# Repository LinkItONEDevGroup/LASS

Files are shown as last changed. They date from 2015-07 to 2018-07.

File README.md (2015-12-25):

# LASS
Project Name: 

	Location Aware Sensing System (LASS)

Vision: 
	
	We hope location aware sensor devices can be easy to provide/build by anyone.
	The sensors data can be manage globally.
	Any sensors data can be display, get, analyze by everyone.
	These sensors data become useful to everyone.
	Then we can monitor our environment globally.

Features:

	Sensor devices can be easy to buy parts and build by Maker
	Open source architecture to support the community
	All sensors result include gps location information
	The sensors data send to internet, and can be manage by any PCs
	Architecture design to support sensor customization
	Visual sensors data is easy through the tool we provided.
	Support sensors data visualize on the google map.
	Support export function, data can be easy analyze through perfessional statistic software R
	Mobile phone UI supported by integrated with Blynk
	Default support more and more sensors.

Press release:
	[【開源公益專案】LASS環境感測網路系統](http://makerpro.cc/2015/09/projectplus-lass/) On [MakerPRO](http://makerpro.cc/)
	
[Presentation slides](https://github.com/LinkItONEDevGroup/LASS/blob/master/Doc/LASS-AllandFuture.pdf)

Contents in [wiki](https://github.com/LinkItONEDevGroup/LASS/wiki):

	0.2 We need your help
	0.3 Device Status
	0.4 Supported sensor status
	1.0 How to get started
	1.1 How to setup the sensor device
	1.2 How to analyse sensor data?
	1.3 How to customize your sensors
	1.4 How to customize your alarms
	2.1 User Data Format Specification
	2.3 Shell requirement
	3.1 Data presentation CLI manual
	4.1 Make a wish
	4.2 Request donation of default supported sensors

Contents in [hackpad](https://lass.hackpad.com/LASS-README-DtZ5T6DXLbu) : workspace for contributors and users

	Contributors Area ( Only contributors have write permission )
	LASS - Contributors List
	LASS - Events
	LASS - Sensors Integration status
	LASS - Data specification
	LASS - Sensors data specification
	LASS - FAQ
	
	Users Area ( Anyone have write permission )
	LASS - Sensor customization service
	LASS - Referenced projects
	LASS - Use case sharing
	LASS - Need help
	LASS - User suggestion
	LASS - Make a wish
	LASS - Scratch pad area

Top level architecture:
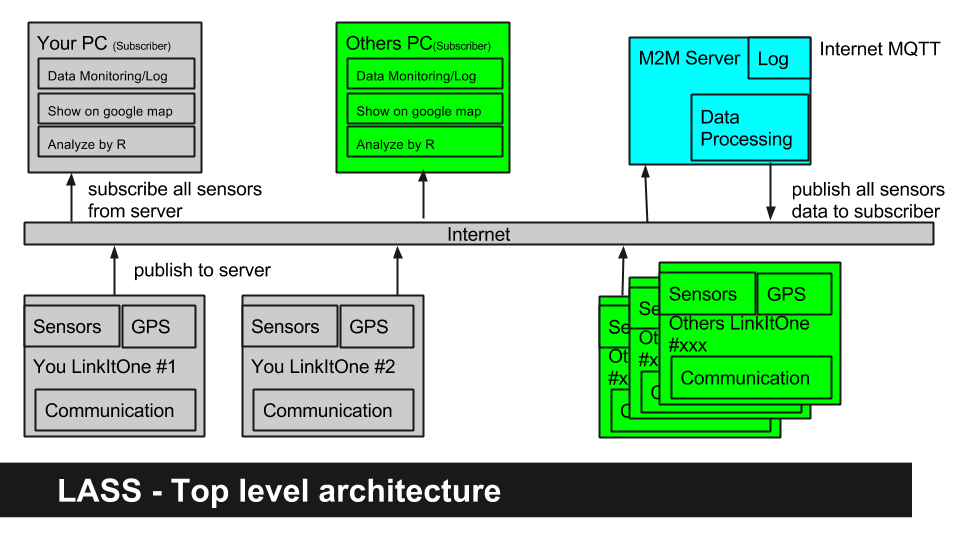
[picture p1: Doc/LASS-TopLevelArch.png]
LASS-TopLevelArch


	Devices (LinkItONE with sensors) sense any data you need ----> 
	Send to gpssensor.ddns.net by MQTT protocol ----> 
	Server (mosquitto server) publish to the subscriber ---->
	Data user subscribe data to get raw data, data with real time chart, export to google map
		Data user have customization capacity to use the data what ever they like

Device architecture:	
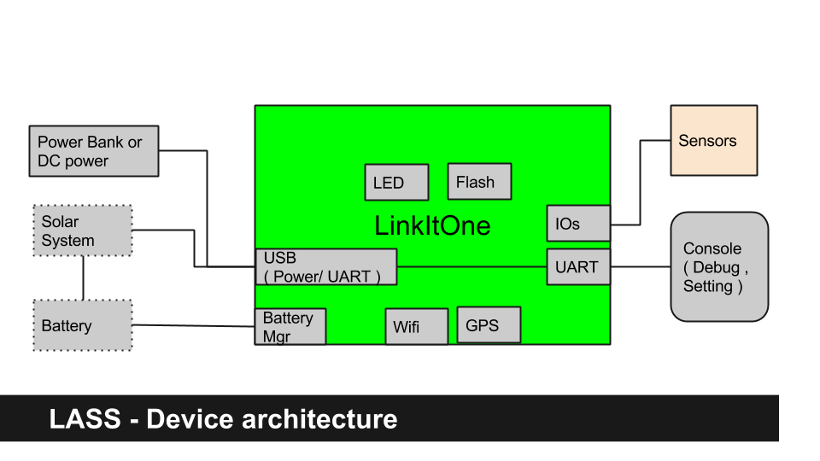
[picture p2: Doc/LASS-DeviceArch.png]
LASS-DeviceArch


Change Logs:

	V0.1 
		Devices send sensors value with GPS related information to server
		The server publish the information to subscribers.
		The device log data to flash when network fail at startup stage.
		The log data will be send when network OK at startup stage.
	
	V0.2
		Front End support: 
		
		Plot sensor data in realtime.
		Support device_id filter.
		CLI(Command line interface) support
		User setting can be adjust through CLI
		Support export to KML
		Use google map map to show it. 	
	
	V0.3
		Device:
		
		Solar charger supported and tested.
		User have more configable options
		Auto power saving mode support
		Wifi will get re-connected once it become available
		More organized code for sensor customization
		Architeture support more sensors at the same time.
		Data include date time from GPS information
		Logged data will send out once wifi get connected
		Monitor battery status to switch power mode
		MQTT organize by application scenario
		
		Front end support:
		
		Auto log support
		Data save/load supported
		Data support filter by date time
		Data date time by gps information support
	
	V0.4
		Device:
		
		Start to support dust sensor, UV sensor ( basic calibrated ) 
		Extend MQTT library buffer setting ( PubSubClient need update )
		
		Frond end support;
		Auto save data, Auto monitor
		GPS KML export value more reasonable.

	V0.4.5
		Example:
		
		Make one example to support [Blynk] (http://www.blynk.cc/), check Blynk directory.
			The example not integrate with LASS.
		
	V0.5
		Device:
		
		LASS support Blynk as mobile phone GUI to read all sensors data.

	V0.5.1 - V0.5.2 
		Frond end:
		
			Fake data generation for data analyze purpose.
			CVS export supported
			R example for data import and google plot 
	V0.6
		Device:
		
			Alarm supported include 3 alarm mode (self detect, central, partner )
			
	V0.6.1
		Frontend:
			GPS altitude information supported in CSV, KML (google map, google earth tested)
	V0.6.2 
		Frontend:
			front end minor features and bug fix
	V0.6.3 
		Device:
			Add audio record to SD example
			fix (1)data loss cause affected by MQTT publish to partner.(2)ALARM_ENABLE=0 compile error
	V0.6.4
		Frontend:
			more exception handler
			add server log importer
		Device:
			add FMT_OPT format to support GPS disable
			default support 20 sensors, and 10 reserved for user
			fix MQTT payload can't > 256 bytes, Library/PubSubClient.zip need to be updated.
			add default record_id to system sensor in order to check data loss
			add startup LED blink
	V0.6.5
		Device:
			Integrated APP_ID=2, pm25sensorG3
			Blink 3.1 sample code verified with LinkItONE at Blynk/Blynk.ino

	V0.6.6 
		Device:
			LASS support Blynk 3.1

Project status:
	
	It's working although we still have lots of idea to do. 
		
Usage procedure:
	
	ViewData: 
		mosquitto_sub -v -h gpssensor.ddns.net -t Sensors/#
		You may need to install the tool from here: http://mosquitto.org/download/
		
	LinkItONE: (you can skip this step if you only want to view the current data)
		Install the libraries ( all in Device_LinkItOne/Libraries )
		Modify user configuration in the code ( Search keyword "REPLACE" )
		Download firmware to LinkItONE
		User Interface:
			the console output use 115200N81
			System LED: 
				On   - Wifi/GPS ready, online publishing
				Off  - Wifi or GPS not ready, offline logging
				Blink- Sensing
        
	Original:
	    The idea come from here: http://iot-hackseries.s3-website-us-west-2.amazonaws.com/linkitone-setup.html

Remind:

	We try our best to test the system but we may make mistakes. Used at your own risk.
	
Created 26/06/2015
By Wuulong, https://github.com/LinkItONEDevGroup/LASS.git

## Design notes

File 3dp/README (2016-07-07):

The LASS devices may need varient kind of cases. The directory intend to collect them in order to share with others.
Please kindly add some information related to 3dp files here.

First try case: 
	caseA_test.stl

Second version: verified
	FRAME_V2_MAX_FINAL.skp
	FRAMELIFT_FINAL.skp
	
LASS_CASE_01.pdf
	The case user make that announce at LASS FB
	https://www.facebook.com/groups/1607718702812067/permalink/1633630400220897/

Scott_Chen
	Perfessional case that fit field try #1. 
	Include support for mount on the UAV
	Original->LASS_V3->LASS_V3.1_Cover
	
	LASS_V3,LASS_V3.1_Cover announcement
		https://www.facebook.com/groups/1607718702812067/permalink/1671977613052842/
	LASS4U
		LASS4U BOX 安裝說明: installation procedure
		LASS4U BOX CAD: CAD source and STL

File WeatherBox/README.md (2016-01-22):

## Arduino

### Library:
* DHT https://github.com/adafruit/DHT-sensor-library
* BH1750 https://github.com/claws/BH1750
* Si1145 https://github.com/adafruit/Adafruit_SI1145_Library
* TinyGPS https://github.com/mikalhart/TinyGPS
* ArduinoJson https://github.com/bblanchon/ArduinoJson

### References:
* [G3 PM2.5 感測器](http://www.icshop.com.tw/product_info.php/products_id/20460)
* [APRS气象站传感器套件](http://wiki.dfrobot.com.cn/index.php/(SKU:SEN0186)_APRS%E6%B0%94%E8%B1%A1%E7%AB%99%E4%BC%A0%E6%84%9F%E5%99%A8%E5%A5%97%E4%BB%B6)

## Raspberry Pi

### 設定開機自動執行程式

安裝 Supervisor

    # apt-get install supervisor

設定 Supervisor
```bash
# vi /etc/supervisor/supervisord.conf
[program:thingspeak]
command=/usr/bin/python /home/pi/thingspeak.py
```

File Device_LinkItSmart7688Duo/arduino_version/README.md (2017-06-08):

# MAPS-LinkIt Smart 7688 Duo
Image of PCB layout

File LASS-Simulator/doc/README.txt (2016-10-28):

README

Please refer "LASS simulator.pdf"
Current version: 0.2

By Version:
V0.0.1 
  Basic application fundation, CFG, logging, CLI, unit test, simulation
  Quick support  Deposition, Car, Population

V0.1
  Export ESRI
  Some setting from file
  Quick wind effect
  
V0.2
	quick load sensor data from LASS
	output LASS sensor data to ASC, CSV format  
	2 day LASS true-data simulation and output for animation

V0.2.1
	simulation history evaluation method.

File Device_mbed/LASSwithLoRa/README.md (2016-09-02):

##LASS mbed NXP LPC1768 實驗步驟

* 架構：

	感測器 -> LPC1768 -> 使用LoRa送出(Gemtek GL6509) 
	-> Gemtek MQTT Server -> Topic Gemtek MQTT 
	-> 抓取回來解析後重新包裝成LASS格式 
	-> 上傳至LASS MQTT Server

* 硬體資料與接線圖：https://lass.hackpad.com/LASS-mbed-NXP-LPC1768-LzijtlOOWIG

* 開發平台：https://developer.mbed.org/

* 操作：

	點選Compiler -> 點選Import -> 點選Click here  
	-> 在Source URL貼上http://developer.mbed.org/users/royedfa5229/code/LASS_LoRa_mbed/ (也可以使用Upload將檔案上傳)
	-> 可更改Import Name -> main.cpp為主程式 
	-> 按下Compile(注意！右上角為你使用的開發板) 
	-> 將下載下來的檔案放進開發板模擬的USB隨身碟 
	-> 重新插拔及燒入完成

* 觀看LCD即可知道數值,若需要更詳細觀察可下載【CoolTermWin】來使用

##程式說明與檔案內容物

* main.cpp為主程式

* 請更改char gps_lat[] = "自己的緯度";char gps_lon[] = "自己的經度";

* 若是使用不同mbed或是想更換Pin腳，可更改pin為自己要的pin腳Serial device(pin, pin);Serial lora(pin, pin);DHT dht22(pin, SEN51035P);Grove_LCD_RGB_Backlight rgbLCD(pin, pin);

* LASSwithLoRa底下的DHT、Grove_LCD_RGB_Backlight、mbed為Libraries

##測試

* 請看測試部分：https://lass.hackpad.com/LASS-mbed-NXP-LPC1768-LzijtlOOWIG

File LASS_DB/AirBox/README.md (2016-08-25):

# The AirBox device information

This folder contains the device information of the AirBox deployment in several major cities.

- **AirBox-SiteName.txt**: The file contains the device information of the AirBox deployment in Taipei Taiwan. It also contains the information of some devices that do not belong to the other city deployment projects.
- **AirBox-SiteName-NewTaipei.txt**: The file contains the device information of the AirBox deployment in New Taipei Taiwan.
- **AirBox-SiteName-Taichung.txt**: The file contains the device information of the AirBox deployment in Taichung Taiwan.

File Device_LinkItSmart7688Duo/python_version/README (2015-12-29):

Installation procedure:
        1. install mt7688duo.ino by using Arduino IDE
        2. copy non-ino files into mylinkit.local:/root by scp
        3. ssh root@mylinkit.local
                chmod 755 mt7688duo_install.sh
                /root/mt7688duo_install.sh
Running procedure:
                python mt7688duo.py

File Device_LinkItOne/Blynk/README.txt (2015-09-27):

Installation procedure:
	After install Blynk library, Blynk.ino should be able to run.
	The library is identical with the Blynk 3.1, we only need Blynk sub directory..
	
This sample verified with the Blynk 3.1 and iphone. checked with Analog A0, Virtual V0

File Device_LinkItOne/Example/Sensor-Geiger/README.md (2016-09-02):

##Geiger LinkItOne 實驗步驟

* 架構：

	感測器 -> LinkItOne -> Print數值

* POCKET Geiger 官方網站：http://www.radiation-watch.org/2011/05/professional.html

* 硬體資料與接線圖：http://radiation-watch.sakuraweb.com/share/type5_connect_with_arduino.pdf

* 開發平台：https://www.arduino.cc/en/Main/Software

* 操作：

	在Arduino內安裝LinkItOne的套件 -> 點選Sensor_Geiger.ino -> 點選Tools
	-> 選擇Board與Port -> 點選Verify -> Upload -> Serial Monitor

##程式說明

* 將原本官網所提供的Arduino Code 稍微修改成 LinkItOne 能夠使用

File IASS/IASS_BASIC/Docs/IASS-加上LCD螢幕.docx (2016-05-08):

# 替IASS加上LCD螢幕

如果您想要在IASS感測器上立即看到目前的感測值，那麼就需要替它加上LCD螢幕。在IASS感測器加上螢幕是很容易的事，只要將LCD用杜邦線接到板子各對應的孔，並將LCD_DISPLAY變數值更改為1，上傳到Arduino就可以了。

IASS預設使用內建I2C模組的16x2(1602)的LCD，如下圖右側，而左側為編號2004（20x4）的LCD，如果您使用不同尺寸的LCD，需自行修改程式。

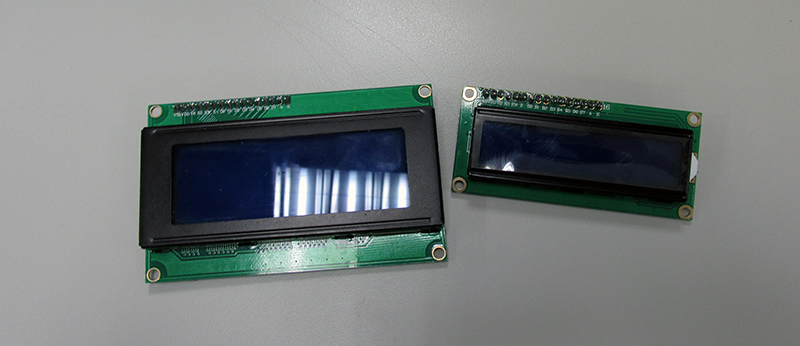
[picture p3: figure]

### 1）準備材料：

1. LCD 1602 5V LCM IIC I2C 16x2 $95 x 1 http://goods.ruten.com.tw/item/show?21408019307836
2. 杜邦線（母→公） 數條

### 2）接上LCD

此類的I2C LCD模組皆有四個接腳如下：

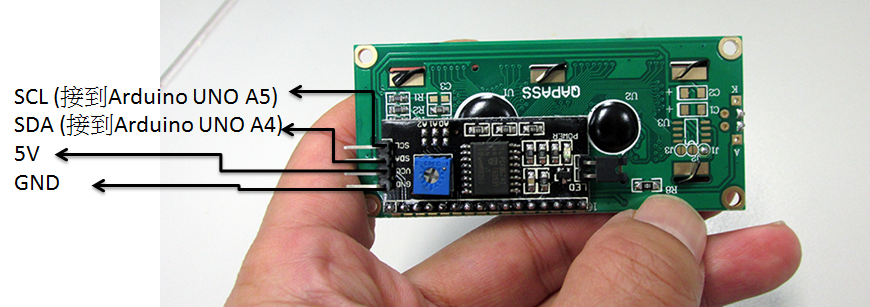
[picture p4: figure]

請參考下圖使用杜邦線將各接腳接到麵包板及Arduino上。

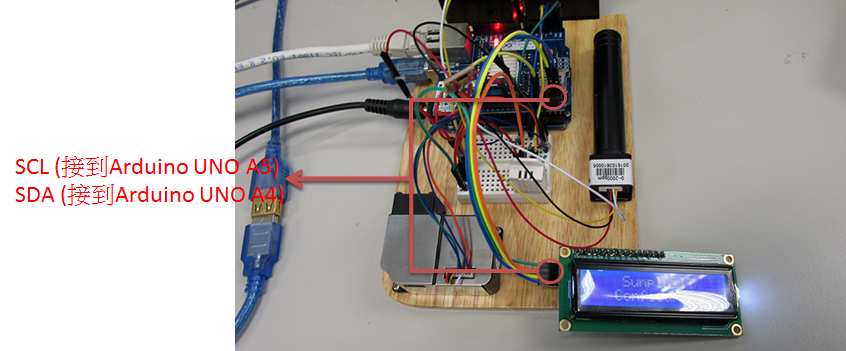
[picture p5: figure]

### 3）將LCD固定好

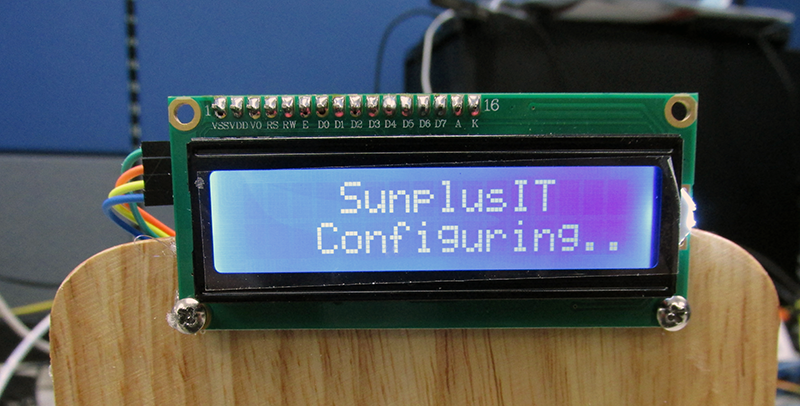
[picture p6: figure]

### 4）程式修改

我們只要將Arduino code中的LCD_DISPLAY變數更改為1就可以，改好後上傳寫入Arduino，完成後您便會看到LCD開始顯示訊息。

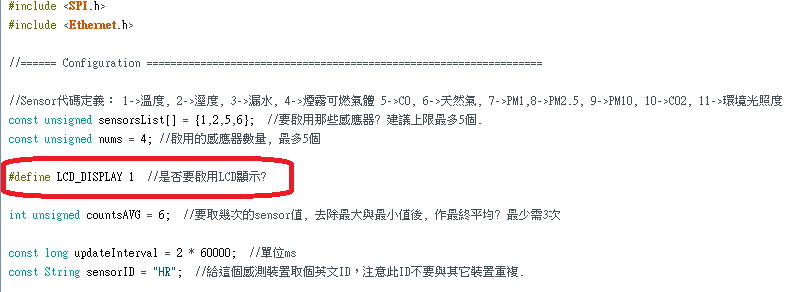
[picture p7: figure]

### 5）最後成果：感測值顯示在LCD上，由右往左循序的移動顯示。

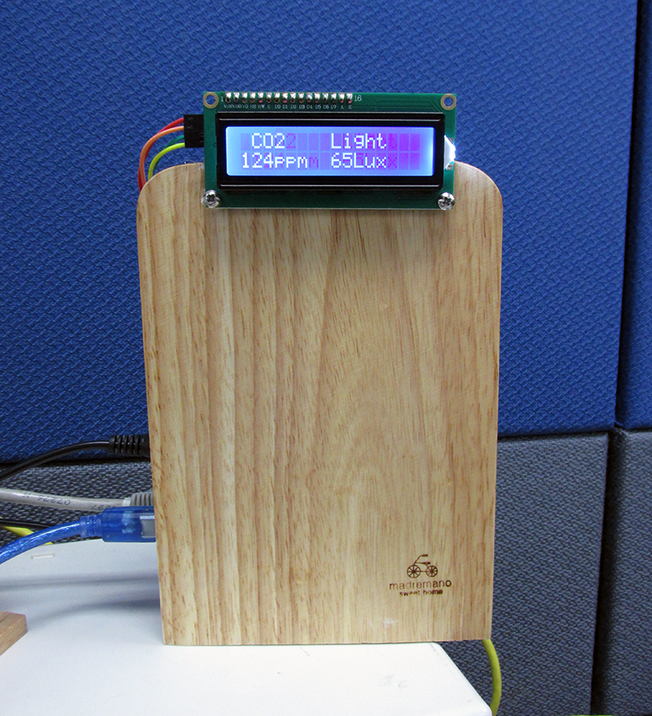
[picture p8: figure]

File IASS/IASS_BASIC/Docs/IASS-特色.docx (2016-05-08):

# IASS特色

## Every One Can DIY Your Own Sensor Device

IASS是一套免費開源的室內環控系統，使用Arduino開發板，搭配市面上常見且價廉物美的感測器，不需要撰寫任何程式，希望任何人皆能在30分鐘內行DIY組裝完成符合自己需求的感測裝置。

# IASS特色

### 1. 任何人皆能DIY感測裝置：

不需要程式設計或相關電子工程知識，每個人皆能DIY自己的環控系統。

### 2. 支援多種感測功能：

目前支援12種環境感應功能：溫度,溼度,漏水,噪音,一氧化碳,天然氣, PM2.5, PM10, PM100, 二氧化碳,環境光照度，可依自身需求決定要加裝的感應器。

### 3. 不需要撰寫程式：

提供現成的Arduino程式可直接使用，分為sensor與device兩種，使用者可依需求選擇不同的sensors程式搭配成device。

### 4. 提供預設搭配好的感測裝置：

除了使用者可自行搭配決定感測器種類外，亦提供預設數種device直接使用：
Office辦公室：溫溼、PM2.5、CO2、光照度
電腦機房：溫溼、漏水、可燃氣體
家居室內：溫溼、一氧化碳、天然氣

### 5. 自動上傳ThingSpeak：

組裝後的device接上網路後會自動上傳ThingSpeak以提供遠端瀏覽觀看（需自行註冊ThingSpeak帳號並於程式中放入API KEY）

### 6. 支援上傳指定 server：

除上傳ThingSpeak之外，亦可選擇將資料傳送到指定的server來接收。(使用GET)

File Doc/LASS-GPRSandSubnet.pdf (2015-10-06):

## LASS 進化 -

## 整合異質網路

2015/10/7 哈爸

http://is.gd/YipnPl

## LASS 再進化

LASS，目前已經算是一個感測器網路的雛形。站在這個基礎 上，我們得思考，如何再對目前環境感測器實現上的困難，再 突破

## 目前的問題

最關鍵的問題是廣域佈建的困難
1. 佈建地點沒電 => 要省電，用電池，要用太陽
能
2. 沒網路，資料傳不出來 => 要增加網路覆蓋，
就是增加傳輸距離

## 怎麼解決

單一的傳輸路徑與佈建方式，其實都容易有系統
上的難點。多方式佈建，則有整合上的困難與成
本的增加。
LinkItONE 內建很多的通訊方式，讓整合上的困 難降低，也讓成本增加很少。我們將利用這個優
勢

## 架構概念

Internet 是廣域網路被證明的解方，網路架構依 附在 Internet 上，使用 MQTT。考慮成本與實用 性，預設網路是 Wifi。這個部分已經完成

在佈建上困難的地方，將使用 GPRS 電信網路。
在極度困難，需要省電的情況，引用異質網路介
面

## 架構概念

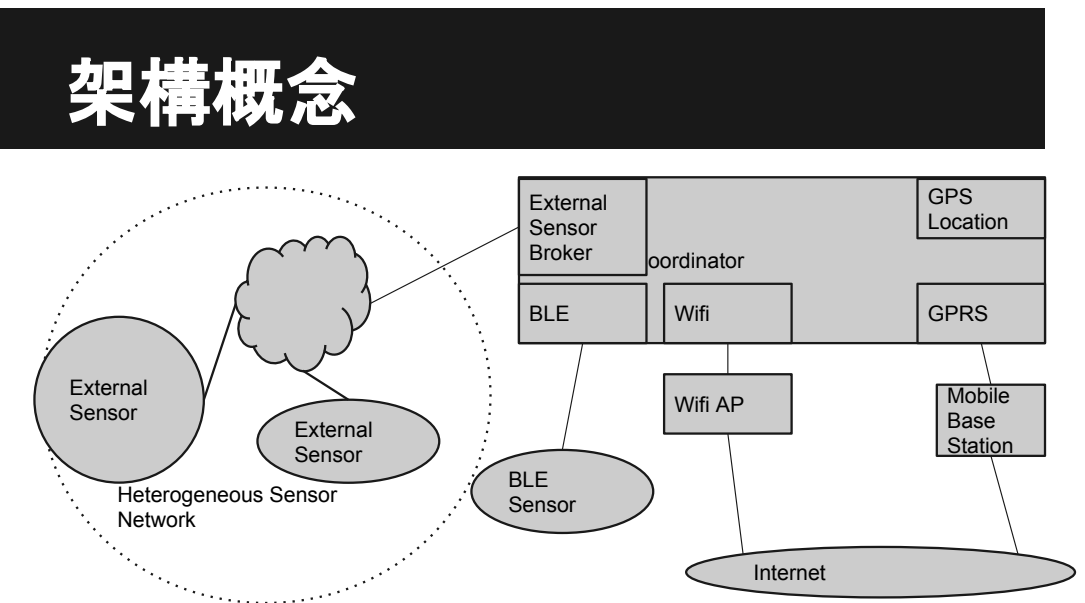
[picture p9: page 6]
Heterogeneous Sensor Network; LinkItONE Coordinator; GPS Location; External Sensor; External Sensor Broker; Wifi; Wifi AP; Internet; BLE; GPRS; Mobile Base Station; BLE Sensor

## 本次進化預計實現的項目

啟用 GPRS 將感測器 資料經由電信網路，轉入
Internet, 匯入原來 LASS 架構。

定義異質網路匯入架構，與概念性的驗證可實現
性，提供給異質網路接入的可靠基礎。

## 預計效益

在不方便有 Wifi, 與電信費用支出可接受的場
景，LASS 將很容易在電信網路可達的地方佈
建。
在電信網路達不到的地方，將可提供使用者彈性
選用合適的連接方式，用很簡單的方式做連結。

作法

本者開源專案由大家貢獻，並將結果回饋給大家
的基本精神。真正實作人員將由社群招募，並由
社群的貢獻來完成。

## 結果驗證

Sensor 資料可經由電信網路，轉入目前 LASS 以 Internet 為基礎的感測器網路架構
外接感測器，可以通訊的方式傳入 LASS 設備，
並轉傳上 LASS 感測器網路架構

## 所需協助

有興趣處理這個問題的 Maker 加入
異質網路資源的贊助（硬體與技術支援）
比方說 Bluetooth sensor, Zigbee sensor ...

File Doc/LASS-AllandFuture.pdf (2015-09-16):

# ＬＡＳＳ於感測器網路課程的分享

# V1.0 哈爸

# LASS 分享

2015/8/25 哈爸

http://is.gd/YipnPl

### Location Aware Sensor System by LinkIt ONE

# 關於哈爸

# 我是 Maker

# 軟體、嵌入式設計十多年相關經驗

# Computex 國際論壇講者

# 國際論壇認證制定參與者 前巨匠 Linux 認證講師，Java 認證講師

# 為何要做-夢想是什麼

# 點一下，就可以看到環境狀態在地圖上顯示出來 可選各種資料，在大範圍的地區

# 這要多少種感測器？如何部署？系統如何整合？多少錢？

# 難道真的是夢？五年前是，但在自造者時代，這不是夢。 這就是 LASS 要做的事情

# 方法是什麼

# 1. 如果有一個系統，能讓我很方便地提供某一個 位置的任一種感測器的資料，並在地圖中顯示

出來

# 2. 只要讓這個方法非常容易讓另外一個人也實現

# 這樣是不是就看到曙光？

# 這是什麼-系統功能

# 具備環境感測器網路系統架構 讓Maker 有能力自製所需要能與系統相容的感測器 將感測器資料還給使用者 完成度高的系統雛型 賦予所有使用者俱備監測全部感測器的能力

# 如何讓另外一個人也方便實現

# 開源(買得到，做得出來) 在哪買，怎麼做

## 完整系統雛型的 Open source

# 怎麼看資料做分析都公開

方便

# 盡可能降低各種進入的門檻

# 參考資料

### LASS README (https://github.com/LinkItONEDevGroup/LASS)

### LASS Wiki (https://github.com/LinkItONEDevGroup/LASS/wiki)

### LASS Hackpad (https://lass.hackpad.com/LASS-README-DtZ5T6DXLbu)

後話

# 這是 Open 的，取你的所需，去用它。鼓勵衍伸性專案與應 用。覺得可以將部分商業化的，也放心去做，我支持您，不過 我自己不做商業化的。

# LASS 系統設計

2015/8/8 哈爸

http://is.gd/YipnPl

### Location Aware Sensor System by LinkIt ONE

# 主要功能

# 具備環境感測器網路系統架構 讓Maker 有能力自製所需要的系統相容的感測器 將感測器所資料還給使用者 完成度高的系統雛型 賦予所有使用者俱備監測全部感測器的能力

# 系統架構

# LASS - Top level architecture LASS - Device architecture

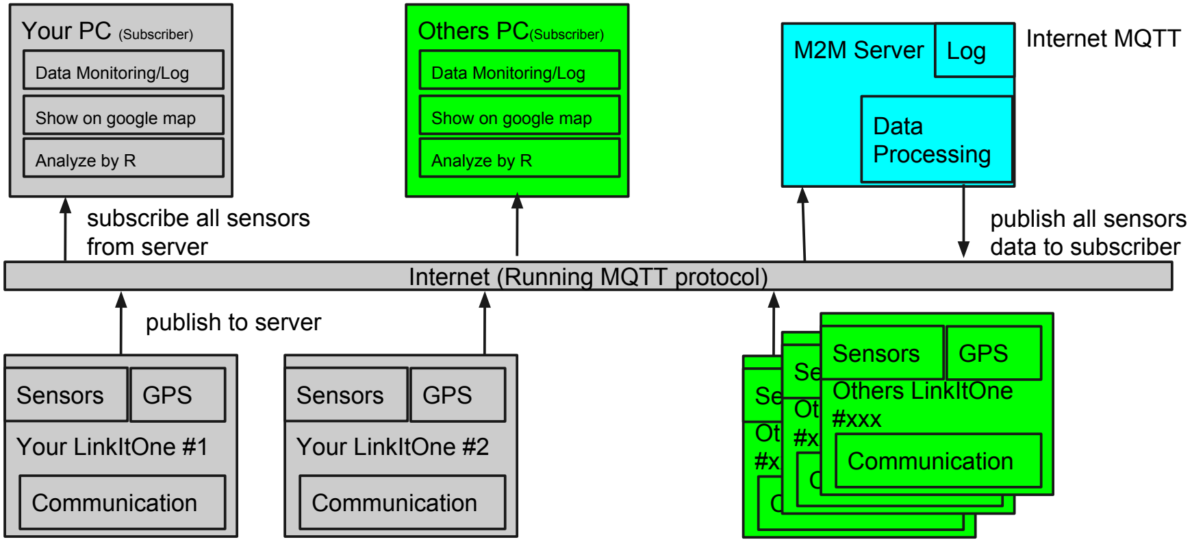
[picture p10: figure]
Your LinkItOne #1; GPS; Communication; Sensors; M2M Server; Internet MQTT Log; Data Processing; publish to server; Your LinkItOne #2; Others LinkItOne #xxx; Others LinkItOne; Internet (Running MQTT protocol); Your PC (Subscriber); Data Monitoring/Log; Show on google map; Analyze by R; subscribe all sensors from server; Others PC(Subscriber); publish all sensors data to subscriber; #xxx

## LASS - Top level architecture

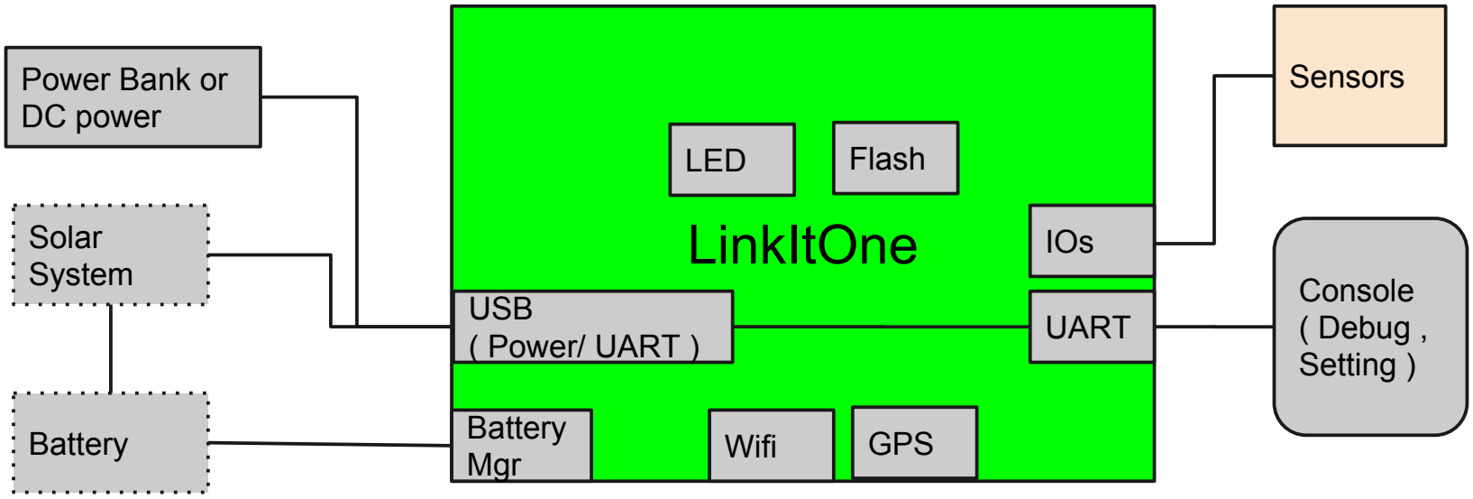
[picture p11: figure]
LinkItOne; Sensors; Flash; Wifi Battery Mgr; LED; Solar System; USB ( Power/ UART ); Battery; Power Bank or DC power; UART; Console ( Debug , Setting ); IOs; GPS

## LASS - Device architecture

# 三層架構運作方式與特色 - 感知層

架構三層 | 系統運作方式 | 特色
感知層 | 可支援各種感測器 軟體架構設計成可輕易經由簡單的修改 達成客製化要求 已整合 Dust/UV/sound 感測器 | 持續收錄更多 sensor 支援 方便使用者建構自己需要的感測器

三層架構引用 - 黃能富教授（物聯網感測器與感測器網路設計）

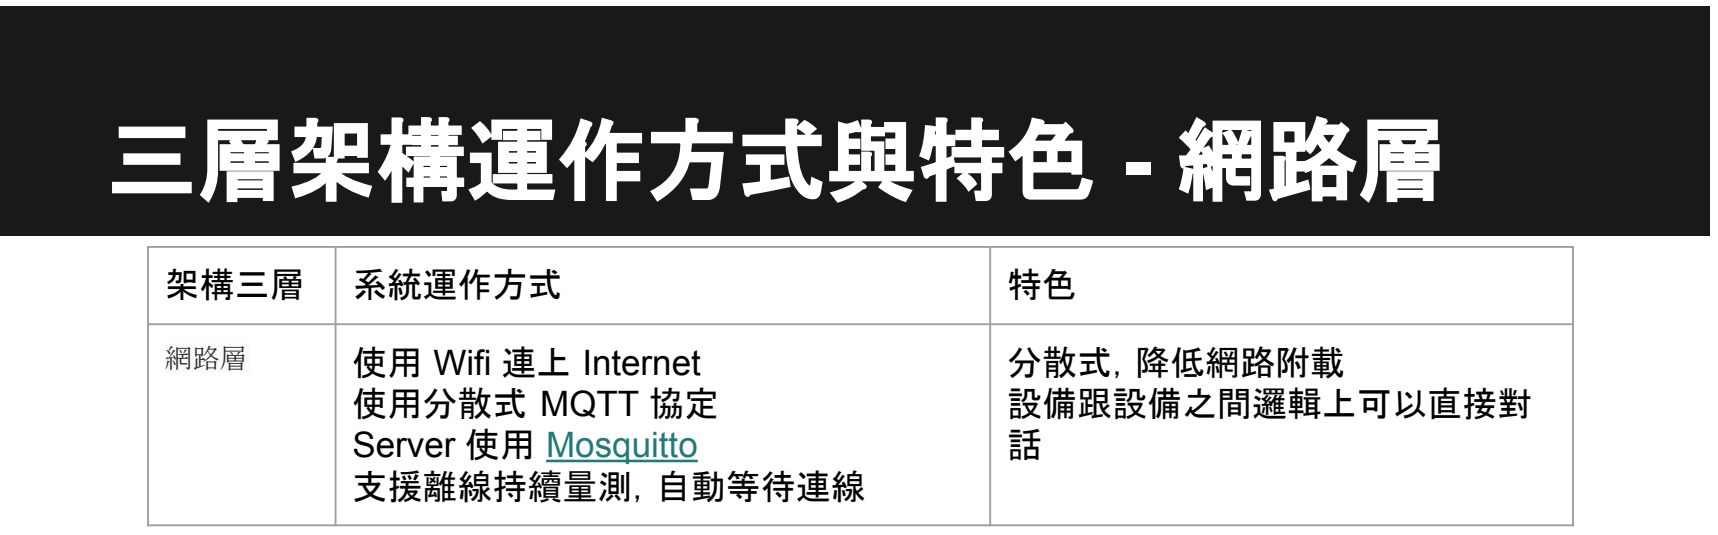
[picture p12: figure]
三層架構運作方式與特色 - 網路層; 架構三層; 系統運作方式; 網路層; 使用 Wifi 連上 Internet; 使用分散式 MQTT 協定 Server 使用 Mosquitto 支援離線持續量測，自動等待連線; 分散式，降低網路附載 設備跟設備之間邏輯上可以直接對 話

# 三層架構運作方式與特色 - 應用層

架構三層 | 系統運作方式 | 特色
應用層 | 伺服器留存 Log，提供下載 當場資料轉傳給所有監測的軟體 動態感測器圖 完整匯出 CSV, KML, R 範例支援 Google Map 顯示 支援多型態的警報機制 支援手機GUI即時監測(By Blynk) 資料架構支援異質系統共存
資料為長久可儲存的簡單架構
完整保留資料的主控權給使用者
資料型態方便進階分析 (R)
雲端精簡化，隨時可改用自己的
創意的夥伴警報機制
針對異質系統共存設計，讓不同研
究人員可以無痛分享彼此資料

# 設備端設計

### 所有感測器資料含GPS 地理資料 Wifi 網路無法連線資料能繼續感測儲存，自動等待網路聯通 無網路連線狀態下，一般情況資料可以儲存ㄧ個月以上 架構上支援多感測器 結構化針對感測器客製化設計，盡可能降低加入新感測器的困難度 支援電池供電，支援太陽能充電，目前應可支援晴天下持續運作 支援省電模式，根據電池電量自動轉換省電模式

# 雲端設計

# AWS Linux Mosquitto service

# Log (每小時 24 份，每天 30 份，每月 12 份， 每年 x 份) ：（尚未完成功能）

# 以FTP server 的形式公開

# 使用者前端設計

### 公開的MQTT 協定，使用者前端可隨客戶選用 這裏提供範例程式，簡化使用者取得資料與分析資料的困難 使用者前端能夠收取所有的感測器資料含其他系統

### Lass.py (Python)

### MQTT client

### Matlab plot

### KML export

### Data load/save

### 支援 Blynk，提供手機端 GUI 介面

# 目前支援的感測器

# 系統支援的感測器是可客製化的。

# 新增的感測器支援，可由社群提供。

# 預設硬體介面為 Grove, 目前支援以下感測器。持續加強中，

更新請參考 Sensor Integration List (https://lass.hackpad.com/LASS-Sensors-Integration-status-c0wWVTBqIWc)

Grove-Dust Sensor (http://www.icshop.com.tw/product_info.php/products_id/14220)

Grove-UV Sensor (http://www.icshop.com.tw/product_info.php/products_id/12316)

Grove-Sound Sensor (http://www.seeedstudio.com/depot/Grove-Sound-Sensor-p-752.html)

# 資料格式

# 只有相同的資料格式才方便做異質系統整合 資料格式需規格化，尤其是感測器與感測器資料 由於資料需跨越各種系統，越簡單越好，方便其 他系統整合

# 資料格式

# Log:

15:31:19|LASS/Test/HELLO_APP|ver_format=1|app=HELLO_APP|ver_app=0.6|device_id=LASS-

Hello|tick=68882494|date=2/8/15|time=7:30:45|device=LinkItONE|values=100.00,1.00,0.00,60.48,856.27

|gps=$GPGGA,073045.099,4402.0319,N,13124.7264,E,0,0,,128.5,M,21.5,M,,*45

收端時間|MQTT Topic|資料

請參考 (https://lass.hackpad.com/LASS-Data-specification-1dYpwINtH8R)

自我偵測模式 ( Self detect mode )
預先設定好，針對自帶 sensor 的狀況，發出緊訊

中控模式 ( Central mode )
由中控端，根據各式檢測演算法，指定 device 發出警訊 Device 會 Subscribe 特定的MQTT主題，根據命令做出警訊 夥伴模式 ( Partner mode )
預先設定好，監測另一個 Device 感測器的狀況，發出警訊 Device 會 Subscribe 夥伴發出的感測器資料，自主判斷發出警訊

# 警報架構 Alarm architecture

警報型態 | 使用情境 | 簡易可行的使用方式（舉例）
自我偵測 Self detect mode | 感測器值超過限定範圍 | 發出聲響 改變燈號 ...
中控模式 Central mode | 區域感測狀況警報 根據統計資訊智能判斷 於管理前端操作，可以隨時加強演算 法 | 半小時內平均超標 附近區域一起發生異常 發 Email, 簡訊, ...
夥伴模式 Partner mode | 監測對象超過限定範圍，需要通知的 對象得到警報 | 老家下雨，桌上點燈 重要觀測對象警報

# LASS - 警報型態 Alarm mode

# LASS - Demo

2015/8/8 哈爸

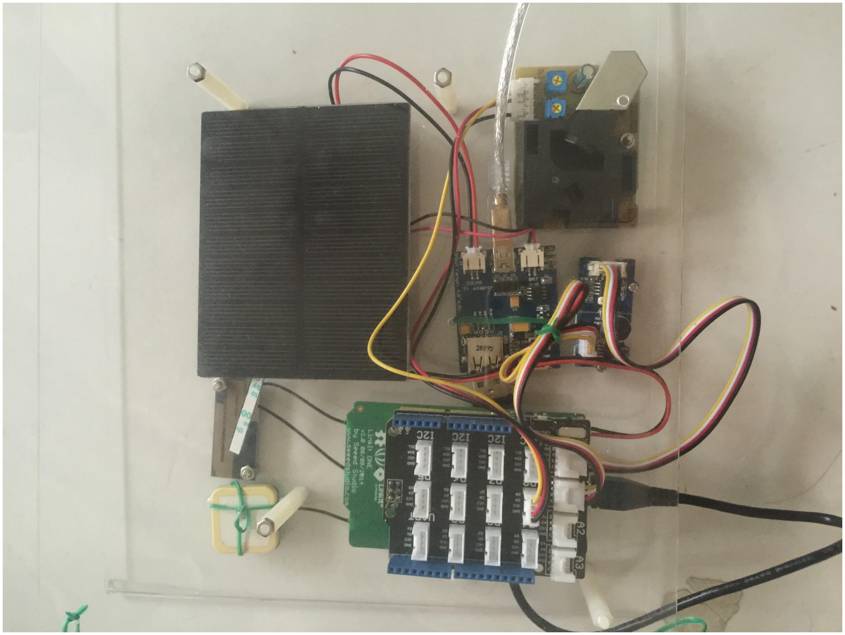
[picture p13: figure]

# Device

設備

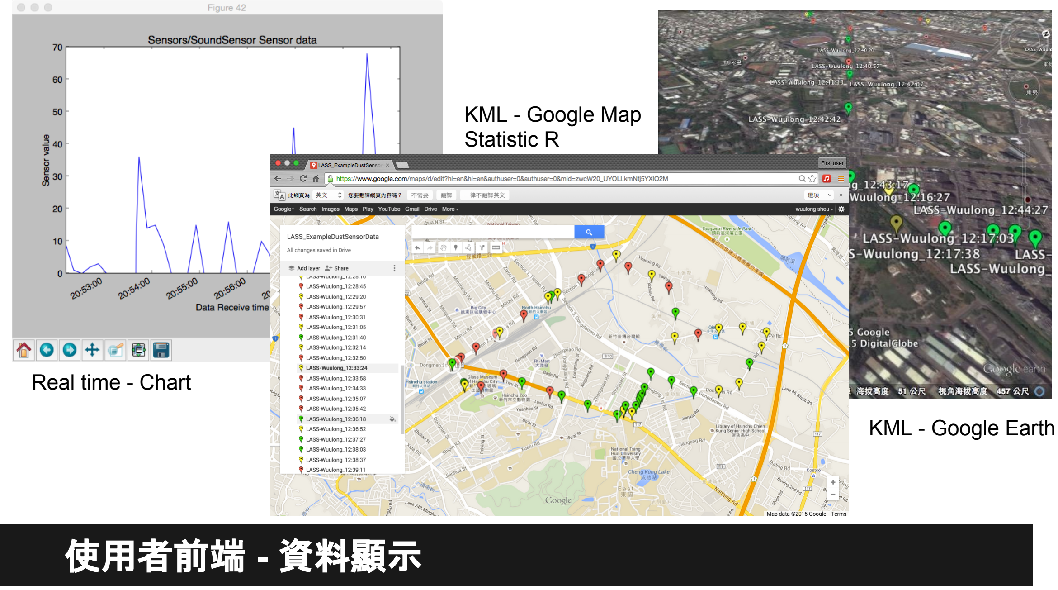
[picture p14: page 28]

# 使用者前端 - 資料顯示

Real time - Chart

KML - Google Map
Statistic R

KML - Google Earth

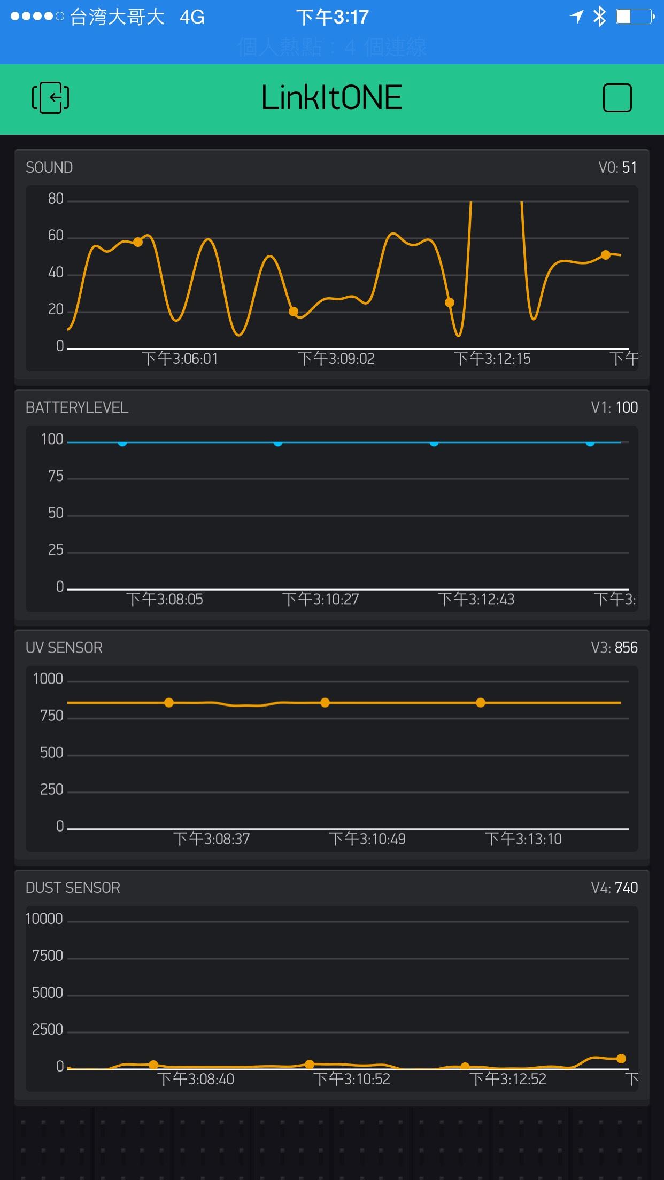
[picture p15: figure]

# 使用者前端 - 手機介面

# Log - 執行 log

# Raw - 可儲存/匯入的資料 CSV - 匯出給其他系統的通用型態

# KML - 匯出給 Goolge Map / Google Earth

CLI User manual (https://github.com/LinkItONEDevGroup/LASS/wiki/3.1-Data-presentation--CLI-manual)

## 使用者前端 - Files

# LASS 未來展望

2015/8/13 哈爸

http://is.gd/YipnPl

### Location Aware Sensor System by LinkIt ONE

# 目標在哪裡

# 點一下，就可以看到環境狀態在地圖上顯示出來 可選各種資料，在大範圍的地區

# LASS - 生命週期

原型期 | 客製化期 | 融合期 | 貢獻期

# 生命週期 - 原型期

要做什麼 | 設計實作系統架構 讓所有基本的系統架構完成雛形，讓細部組件能 夠得以持續改進 將設計與文件，製作方式，使用方式開源
會達成什麼 | Maker 可以自製 資料已經可以納入整體資料的一部分
對社會的貢獻是什麼 | 讓研究人員能夠自製全域感測器展開相關的研究 讓感測器網路的設計能有個例子，提供給教學上使用 讓感測器網路產品能有一個微小的共同基礎，能持續改善

# 生命週期 - 客製化期

要做什麼 針對各種使用情境，對感測器進行客製化 建立維護社群（開臉書群組） 建立社群支援機制 提高社群與參與 Maker 的價值 推廣

簡化零件的取得，有人出售零件包
準備教材，進入Maker 教育體系
針對各式情境，再對 LASS 進化，讓一些困
難問題能給予幫助
加強預設支援感測器種類
尋找感測器贊助廠商，讓廠商支援與社群接
軌

會達成什麼 Maker 更容易製作感測器 更多Maker 針對各種使用情境將感測器客製 化 更多使用者，自製或是購買去量測環境資料 LASS 將更能在特定情境下使用

臉書： LASS-開源公益的環境感測器網路 (https://www.facebook.com/groups/1607718702812067/)
CAVEDU 教育團隊 (http://www.cavedu.com/)

對社會的貢
獻是什麼

在特定情境下，能開始有真實的資料 產出，以
利所有人應用

在特定情境下，普通使用者 (非Maker) 有能
力，買來就去量。為自己環境出一份力

# 生命週期 - 融合期

要做什麼 | 加強各種情境資料標準化 加強資料分析工具 社群加強異質系統融合 實作全域即時查詢介面 資料採礦 | 加強產品化考量，幫助衍伸性專案 產品的可 實現性
會達成什麼 | 有各種資料能夠在全域中顯示 針對特定情境產出有價值的資料 更完整的資料處理處理的系統 更完整的中央管理機制 | 產生產品化的可能有效路徑
對社會的貢 獻是什麼 | 針對特定情境，我們能看到環境全域的狀態 與歷史資料 針對特定情境，我們能簡易的發現異常，並 期待做出反應 | 真正讓使用者拿到更好的 產品去感測環境

# 生命週期 - 貢獻期

要做什麼 | 隨著社群的自由發展持續演化出下一代系統
會達成什麼 | 更多情境的有效全域資料 不同情境的有效資料能 夠交互使用，產生更大的價值 使用者輕易取得資料呈現的結果 中央管理系統能更有效率地做出反應
對社會的貢獻是什麼 | 我們能看到環境全域的狀態與歷史資料 我們能簡易的發現異常，並期待做出反應

# 我們的原則

### 基本上任何對達成目標有幫助的，我們都很樂意支援（當然需要有其正當性與對社 會能有貢獻為原則）

### 對 Maker, 以及對 LASS 社群有貢獻的，我們也樂意支援

### 這個要大家化異求同的目標達成的可能就是，盡可能地開放，盡可能的分享，盡可 能的合作。LASS 不是我們的，LASS 是大家的，資料是大家的，系統與硬體只是 實作的方式而已

# 原則 - LASS 本身

# 能不能支援更多感測方式 ? Yes 能不能使用更多的通訊方式 ? Yes

## 能不能不用 LinkItONE ? Yes

# 歡迎使用更多的平台，以不破壞架構為原則 能不能接上其他雲端 ？ Y/N 如果異質資料還能融合的話就可以，不適合的話，請以衍 伸專案的方式進行

# 原則 - LASS 衍伸計畫

# 歡迎衍伸計畫，專題，比賽 歡迎衍伸計劃針對全部或部分進行產品化 基本上 LASS 也朝向更容易產品化前進，以降 低衍伸性產品商品化的難度（以不破壞整體架構 為原則）

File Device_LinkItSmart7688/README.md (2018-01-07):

# LASS7688 Project

This is the main page for the LASS7688 project. The development of this project is based on the AnySense_7688 project. The project is distributed in an open sourced manner, and you are welcome to contribute and help us!

## Change log

* 2018/1/7: version 0.1 released (use G5T, and support OTA, SD storage, OLED, restful data uploading)

## Hardware

* MediaTek LinkIt Smart 7688
* MediaTek LinkIt Smart 7688 Breakout (optional)
* T/H/PM sensor: Plantower PMS5003T
  * https://www.taiwaniot.com.tw/product/pms5003t-g5t-攀藤粉塵溫濕度二合一感測器/
  * http://mntech.com.tw/PMS5003T
* 0.96" OLED (optional)
  * https://www.taiwaniot.com.tw/product/0-96吋oled-液晶屏顯示模組/
  * http://www.icshop.com.tw/product_info.php/products_id/12424
* SD card (optional)

## How to install the codes (for new LinkIt Smart 7688 boards)?

Please login your 7688 board, and switch your 7688 to station mode (note: the other choice is to turn off WiFi and enable Ethernet connection). Then, please change the working directory to /root and follow the following steps:

1. Use the coommand to get the latest version of the codes: 
   ```
   git clone https://github.com/cclljj/LASS7688

2. update the values of GPS_LAT and GPS_LON with your GPS coordinates in the file /root/LASS7688/APP_LASS7688_config.py

3. Run the setup script:
   ```
   /root/LASS7688/setup.sh

Then, the script will install and configure everything. The system will reboot after the installation is done, and hopefully the system will start to upload data to the backend database.

## How to re-install the codes?

Please use the designated account/password to login the system, and remove the existing project source codes:

## Acknowledgement

The project was inspired by Spark Lee's Linkit7688_PM2.5 project (https://github.com/future/Linkit7688_PM2.5). We also thank Ming-Wei Cheng (a.k.a. A-Hai) for his technical advices and anonymous users for their valueable feedbacks.

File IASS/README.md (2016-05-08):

A)[IASS的特色](https://chtseng.wordpress.com/2016/03/31/iass%e7%89%b9%e8%89%b2/)

B)使用IASS的三種樣本，開始準備材料及組裝

&nbsp;&nbsp;B.1)選擇您需要的感測裝置類型<br>
&nbsp;&nbsp;&nbsp;&nbsp;- [辦公室專用感測裝置](https://chtseng.wordpress.com/2016/03/31/diy-%e8%be%a6%e5%85%ac%e5%ae%a4%e7%9a%84%e6%84%9f%e6%b8%ac%e8%a3%9d%e7%bd%ae/)			
&nbsp;&nbsp;&nbsp;&nbsp;- [居家安全專用感測裝置](https://chtseng.wordpress.com/2016/03/31/%e5%b1%85%e5%ae%b6%e5%ae%89%e5%85%a8%e5%b0%88%e7%94%a8%e6%84%9f%e6%b8%ac%e5%99%a8diy/)<br>
&nbsp;&nbsp;&nbsp;&nbsp;- [機房專用感測裝置](https://chtseng.wordpress.com/2016/03/31/%e6%a9%9f%e6%88%bf%e5%b0%88%e7%94%a8%e6%84%9f%e6%b8%ac%e5%99%a8diy-2/)<br>
		
&nbsp;&nbsp;B.2)[是否加裝LCD螢幕](https://chtseng.wordpress.com/2016/04/14/%E6%9B%BFiass%E5%8A%A0%E4%B8%8Alcd%E8%9E%A2%E5%B9%95/)
		
&nbsp;&nbsp;B.3)選擇要使用直接上傳ThingSpeak還是自建主機版本的Arduino程式
			
&nbsp;&nbsp;B.4)[Arduino程式燒錄](https://chtseng.wordpress.com/2016/03/31/%E7%A8%8B%E5%BC%8F%E7%87%92%E9%8C%84%E5%8F%8A%E5%A0%B1%E8%A1%A8%E8%A8%AD%E5%AE%9A/)	
	
&nbsp;&nbsp;B.5)若您選擇上傳ThingSpeak版本：	
&nbsp;&nbsp;&nbsp;&nbsp;- [ThingSpeak報表設定](https://chtseng.wordpress.com/2016/04/14/thingspeak-%E5%A0%B1%E8%A1%A8%E8%A8%AD%E5%AE%9A/)
	
&nbsp;&nbsp;B.6)若您選擇自建主機版本：<br>
&nbsp;&nbsp;&nbsp;&nbsp;- [安裝及設定IASS主機] (https://chtseng.wordpress.com/2016/04/13/%e8%87%aa%e8%a1%8c%e6%9e%b6%e8%a8%adiass%e4%b8%bb%e6%a9%9f-2/)
<br><br>
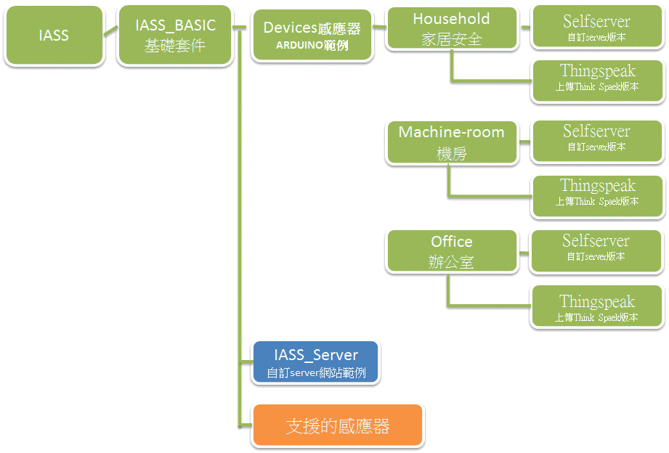
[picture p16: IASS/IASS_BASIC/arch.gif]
架構圖


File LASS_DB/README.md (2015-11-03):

#Description

This program will do the followings:
  1. to work as a MQTT subscriber of LASS
  2. to convert the MQTT messages into BSON format and insert into MongoDB
  3. to convert the MQTT messages into BSON format and insert into Couchbase
  
**MongoDB**: https://www.mongodb.org  <br>
**Couchbase**: http://www.couchbase.com

#Data Format
	LASS data format version 2.0 or the later version (i.e., the default data format of LASS version 0.7.1+)
	
#Parameters 

You may need to configure the following parameters in order to have the program run on your platform.

  * **MongoDB_SERVER**: the host address of your own MongoDB server
  * **MongoDB_PORT**: the port number of your own MongoDB server
  * **Couchbase_SERVER**: te host address and the data bucket name of your own Couchbase DB

#Requirements:
  * **Paho**: The Paho Python Client provides a client class with support for both MQTT v3.1 and v3.1.1 on Python 2.7 or 3.x. It also provides some helper functions to make publishing one off messages to an MQTT server very straightforward. <br>
	  URL: https://eclipse.org/paho/clients/python/

  * **PyMongo**: PyMongo is a Python distribution containing tools for working with MongoDB, and is the recommended way to work with MongoDB from Python.  <br>
    URL: https://api.mongodb.org/python/current/

  * **Couchbase**: The Python client for Couchbase. <br>
    URL: https://pypi.python.org/pypi/couchbase
    
  * **re**: This module provides regular expression matching operations in Python. <br>
    URL: https://docs.python.org/3/library/re.html
    
  * **json**: JSON encoder and decoder in Python. <br>
    URL: https://docs.python.org/3/library/json.html

#Installation
  * Download MQTT software from http://mosquitto.org
    * untar the package
    * install MQTT (on Mac OS X)
      * cmake .
      * make
      * sudo make install
    * Test MQTT
      * run server: mosquitto &
      * subscript a topic: mosquitto_sub -t MY/TOPIC
      * publish a message (on the other terminal): mosquito_pub -t MY/TOPIC -m 12345
  * Download MongoDB from https://www.mongodb.org
    * for Mac OS 
      * make new directory for the database: sudo mkdir /data
      * make new directory for the database: sudo mkdir /db
      * change the ownership of the directory: chown -R username /data/db
      * run MongoDB:  ./mongod
    * for Ubuntu 14.04
      * sudo apt-key adv --keyserver hkp://keyserver.ubuntu.com:80 --recv 7F0CEB10
      * echo "deb http://repo.mongodb.org/apt/ubuntu trusty/mongodb-org/3.0 multiverse" | sudo tee /etc/apt/sources.list.d/mongodb-org-3.0.list
      * sudo apt-get update
      * sudo apt-get install -y mongodb-org
      * sudo service mongod start
  * Download Couchbase from http://www.couchbase.com
  * Install Python Couchbase module 
    * install libevent from http://libevent.org
      * for Mac OS 
        * download the tar package
        * untar
        * ./configure
        * make
        * sudo make install
      * for Ubuntu 14.04
        * sudo apt-get install libevent-dev
    * install libcouchbase from https://github.com/couchbase/libcouchbase
      * for Mac OS 
        * git clone git://github.com/couchbase/libcouchbase.git
        * cd libcouchbase && mkdir build && cd build
        * ../cmake/configure
        * make
        * sudo make install
      * for Ubuntu 14.04
        * sudo wget -O/etc/apt/sources.list.d/couchbase.list http://packages.couchbase.com/ubuntu/couchbase-ubuntu1404.list
        * wget -O- http://packages.couchbase.com/ubuntu/couchbase.key | sudo apt-key add -
        * sudo apt-get update
        * sudo apt-get install libcouchbase2-libevent libcouchbase-dev
    * install python couchbase module (https://pypi.python.org/pypi/couchbase)
      * Module document: http://pythonhosted.org/couchbase/#
      * sudo pip install git+git://github.com/couchbase/couchbase-python-client

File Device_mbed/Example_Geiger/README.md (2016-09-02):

##Geiger mbed NXP LPC1768 實驗步驟

* 架構：

	感測器 -> LPC1768 -> Print數值

* POCKET Geiger 官方網站：http://www.radiation-watch.org/2011/05/professional.html

* 硬體資料與接線圖：http://radiation-watch.sakuraweb.com/share/type5_connect_with_arduino.pdf

* 開發平台：https://developer.mbed.org/

* 操作：

	點選Compiler -> 點選Import -> Search criteria -> LASS_Geiger_mbed 
	-> 或在https://developer.mbed.org/users/royedfa5229/code/LASS_Geiger_mbed/ (點選Import)
	-> 可更改Import Name -> main.cpp為主程式 
	-> 按下Compile(注意！右上角為你使用的開發板) 
	-> 將下載下來的檔案放進開發板模擬的USB隨身碟 
	-> 重新插拔及燒入完成

##程式說明與檔案內容物

* main.cpp為主程式
* 此程式主要是將原官網提供的Arduino code 轉換成 mbed 能使用

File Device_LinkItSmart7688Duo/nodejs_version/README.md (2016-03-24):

LASS Linkit 7688 Duo 實驗步驟

* 請參考文件： https://hackpad.com/1HcedS5HQnI

* 原理：MCU負責感測並送至MPU=>MPU之NodeJS負責對時，組MQTT上傳
* 準備：7688 Duo/G3/DHT/行動電源
* 連接六條硬體接線
* 7688Duo=>設定為Station Mode並設定連上手機分享以上網
* Copy DHT目錄至Arduino Library
* 開啟LASS-7688Duo.ino並上傳
* 編輯iot.js 改 deviceId: "TEST_001"=>改成你的device id
* scp iot.js至7688 root
* ssh至7688
* (以下看能否改為install.sh)
opkg update
opkg install mosquitto mosquitto-client libmosquitto
npm install mqtt --save
npm install ntp-client --save

##編輯/etc/rc.local
#!/bin/sh -e
node /root/iot.js
exit 0
##

chown 777 /etc/rc.local
reboot -f

* 用mqtt-spy工具連上gpssensor.ddns.net看 
  LASS/Test/PM25 或 LASS/Test/PM25/TEST_001 (兩邊都會有資訊)

* Todo:
* 利用手機更新GPS
* 手機介面

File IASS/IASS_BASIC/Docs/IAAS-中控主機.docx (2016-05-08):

# 自行架設IASS主機

IAAS感測裝置除了可上傳資訊到thingspeak.com之外，也可傳送到到指定的IP ，讓我們可將這些資訊自行接收儲存下來，並自行開發程式來處理及運用這些資訊。IASS本身也提供了一套基本的IASS主機程式，提供使用者可快速的安裝使用。該範例為使用PHP+mySQL所編寫，安裝上相當容易，步驟如下：

A） 準備一個可執行PHP + mySQL的web server，下載並解壓IAASweb.zip。
B） 建立資料庫：下載iaas_db.sql，並透過phpMyAdmin匯入mySQL。
C） 透過phpMyAdmin新增一mySQL account，將此帳號資訊填入pdo.php。
D） 將各感應device的ID及sensors代號列表填入pdo.php。
E） 將整個IAASweb目錄上傳web server。
F） 將web主機相關資訊更新到各感應device。
G） 後續修改及調整。

# A) 準備web server，下載並解壓IAASweb.zip。

您可以使用一般的PC，也可以用樹莓派RPI或香蕉派BPI搭配一台小型LCD螢幕來架設。

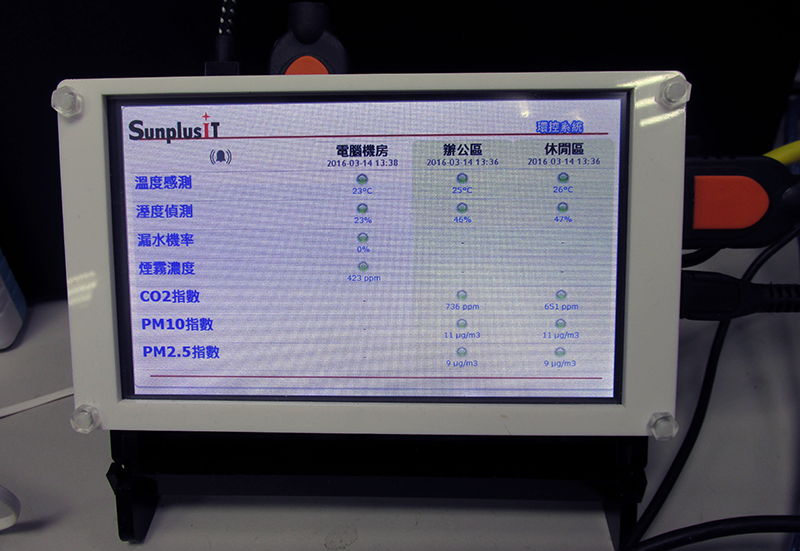
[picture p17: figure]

# B) 建立資料庫

1. 下載iaas_db.sql，使用phpMyAdmin匯入執行，完成後會建立一個sensor_data資料庫，裏面有四個tables。

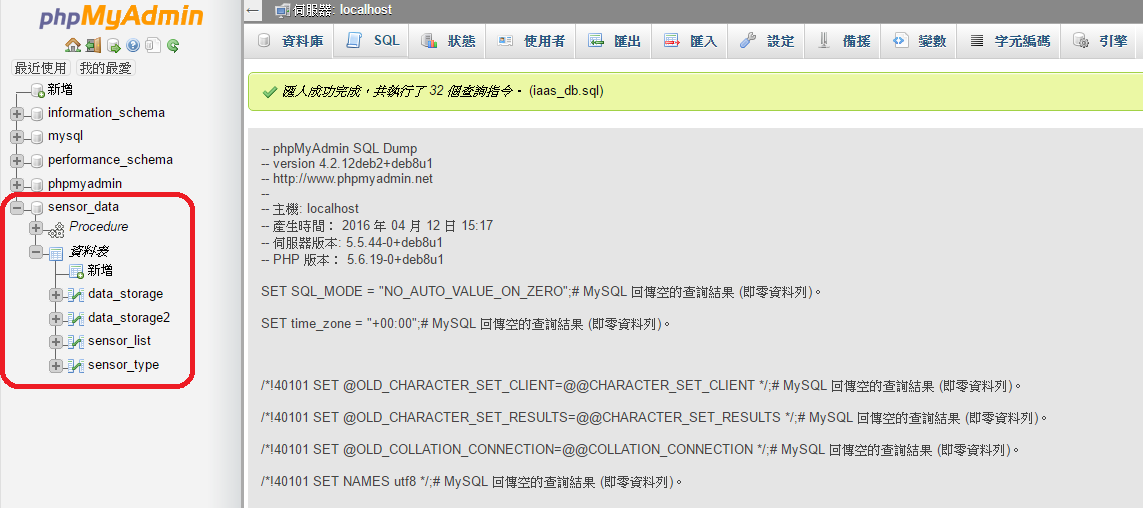
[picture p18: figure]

# C) 新增mySQL account

1. 透過phpMyAdmin新增一mySQL帳號，給予它存取sensor_data資料庫的權限。

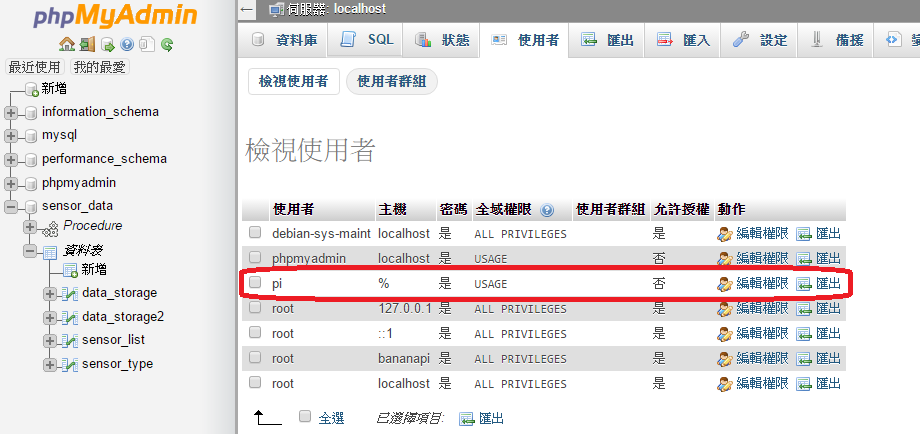
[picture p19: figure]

2. 編輯 conn/pdo.php 檔案，將剛剛新增的帳號及密碼填入。

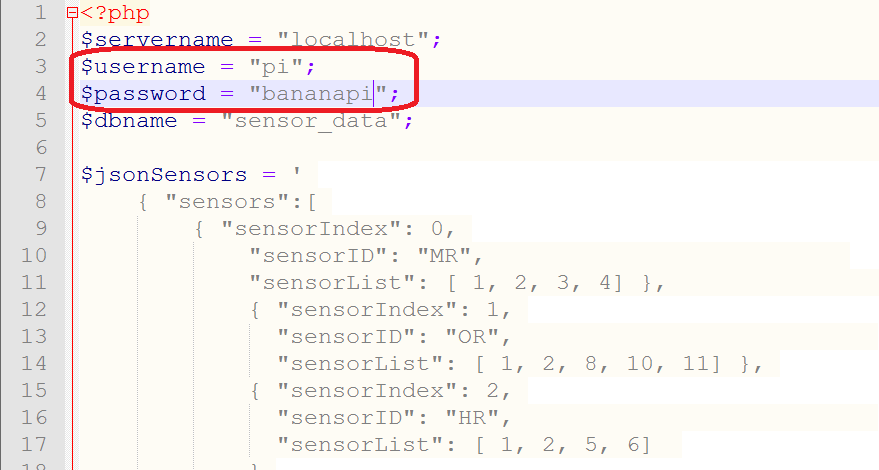
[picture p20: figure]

# D) 設定要顯示的裝置及sensors

1. 接下來，我們要設定主機上要顯示那些感測器的資訊。請回頭檢視一下您目前使用中的IAAS感應裝置，假設您目前有三台，請看一下它們的Arduino Code，分別記下sensorsList[]以及sensorID的值。（這兩個值是可自行設定的）

第一台：

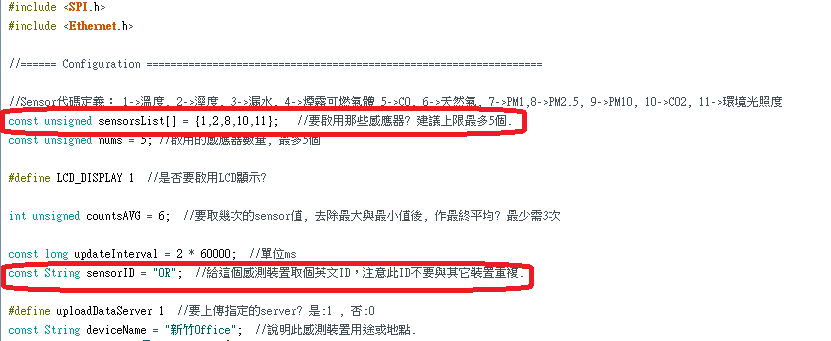
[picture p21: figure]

第二台：

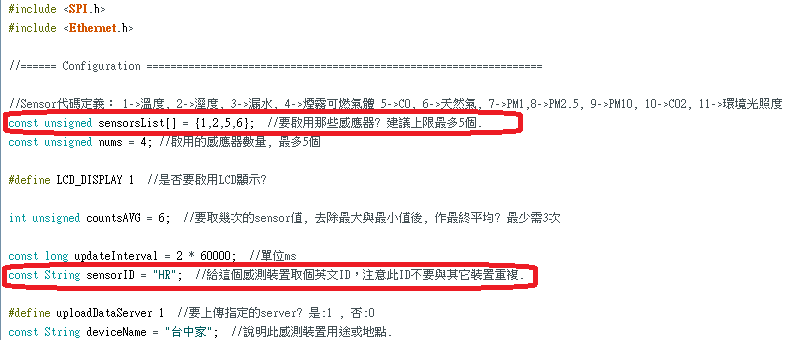
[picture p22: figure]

第三台：

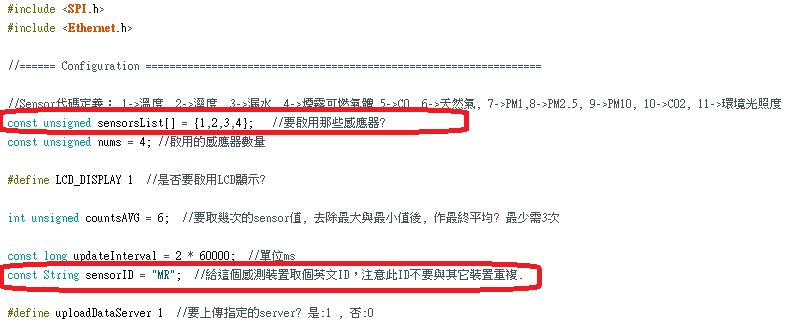
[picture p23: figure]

2. 編輯 conn/pdo.php 檔案，將各台的sensorList[]及sensorID資訊填入。

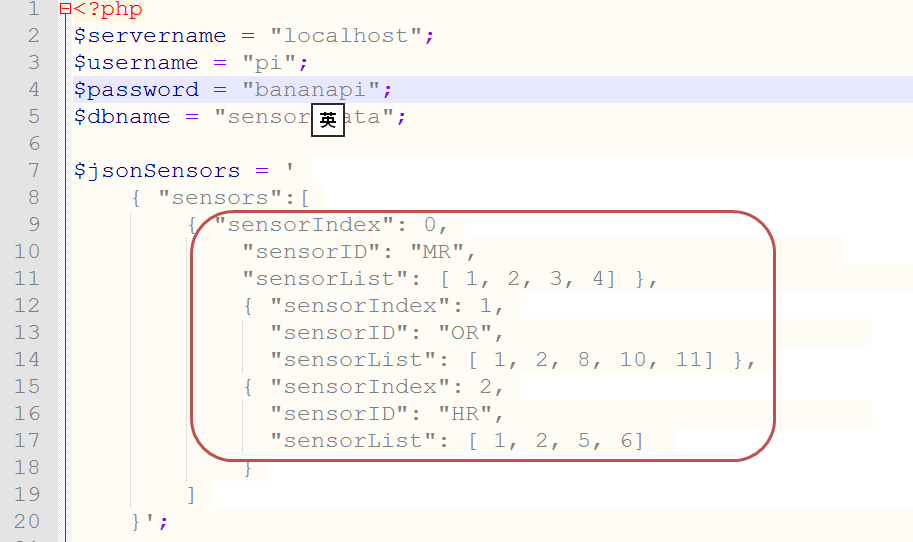
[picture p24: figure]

# E) 將IAASweb目錄整個上傳到網站伺服器。

上傳後，請記下該網站的存取路徑，下一步驟中需要使用。

# F) 將web主機相關資訊更新到各感應device

接下來我們要更新IAAS各device的Arduino code，讓感測資料能正確傳送到指定的伺服器，請尸修改下列的紅圈處。

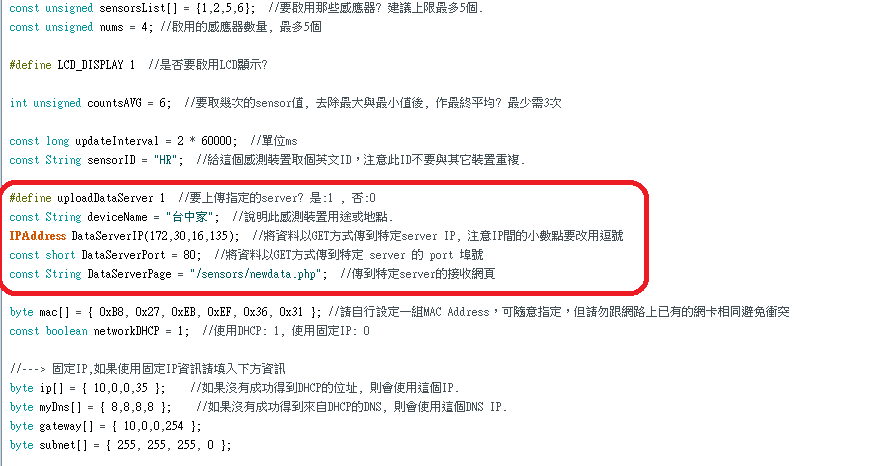
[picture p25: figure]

# 後續修改及調整

當網站開始有資料進來之後，進入網頁後您會發現所有燈號是紅色的，這是因為還未設定上限警示值的緣故。

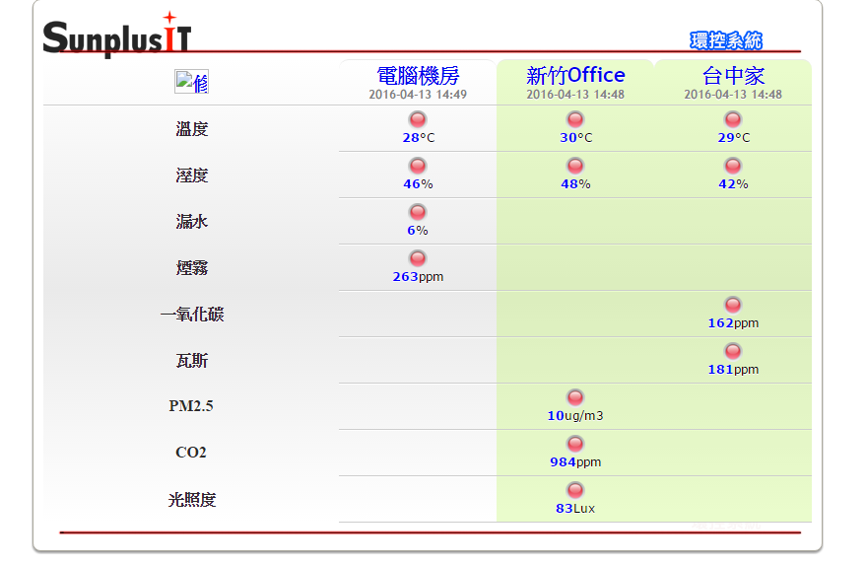
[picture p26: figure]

請進入phpMyAdmin，修改sensor_list表格中alarm_max及alarm_min此兩項資訊，即可讓頁面正確的顯示綠燈或紅燈。


我們依據不同感應器並針對不同場所，輸入上下區間值如下：


OK ，此時網頁已能正確的顯示燈號了。


另外，sensor_type表格中的maxV及minV則是用來設定曲線圖Y軸的上下限，您可依據不同感應的特性來調整這些值。


各感測值的曲線圖顯示結果。


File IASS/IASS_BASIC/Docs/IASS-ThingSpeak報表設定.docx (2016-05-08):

# ThingSpeak報表設定

# 注入靈魂，把程式燒錄到感測裝置上！

接下來，請在PC上安裝好Arduino IDE，並將感測裝置接上，確定Arduino IDE的設定及序列埠都正確。


到https://github.com/LinkItONEDevGroup/LASS/tree/master/IASS/IAAS_CODES/devices 目錄下，進入Office目錄，將office.ino程式內容Copy下來Paste到Arduino IDE，請視需要修改下方的參數（紅色部份是必要的修改）：

//Sensor代碼定義： 1->溫度, 2->溼度, 3->漏水, 5->CO, 6->天然氣, 7->PM2.5,8->PM10, 9->PM100, 10->CO2, , 11->環境光照度

const unsigned sensorsList[] = {1,2,7,8,9,10,11}; //要啟用那些感應器?

const unsigned nums = 7; //啟用的感應器數量

const String sensorID = "MR"; //給這個感測裝置取個英文ID，注意此ID不要與其它裝置重複.

const String deviceName = "電腦機房"; //說明此感測裝置用途或地點.

int unsigned countsAVG = 6; //要取幾次的sensor值, 去除最大與最小值後, 作最終平均? 最少需3次

const boolean uploadThingsSpeak = 1; //要上傳ThingsSpeak? 是:1 , 否:0

const String writeAPIKey = "{你的ThinkSpeak APIKEY}";

const long updateThingSpeakInterval = 5 * 60000; //單位ms

const boolean uploadDataServer = 0; //要上傳指定的server? 是:1 , 否:0

IPAddress DataServerIP(192,168,3,2); //將資料以GET方式傳到特定server IP，若不需要上傳則用 ""

const short DataServerPort = 80; //將資料以GET方式傳到特定 server 的 port 埠號

const String DataServerPage = "/iaas/update.php"; //將資料以GET方式傳到特定server的接收網頁路徑

byte mac[] = { 0xDE, 0xAD, 0xBE, 0xEF, 0xFE, 0xED }; //請自行設定一組MAC Address，可隨意指定，但請勿跟網路上已有的網卡相同避免衝突

const boolean networkDHCP = 1; //使用DHCP: 1, 使用固定IP: 0

//---> 固定IP,如果使用固定IP資訊請填入下方資訊

byte ip[] = { 10,0,0,35 }; //如果沒有成功得到DHCP的位址, 則會使用這個IP.

byte myDns[] = { 8,8,8,8 }; //如果沒有成功得到來自DHCP的DNS, 則會使用這個DNS IP.

byte gateway[] = { 10,0,0,254 };

byte subnet[] = { 255, 255, 255, 0 };

修改後，便可直接燒錄至Arduino（燒錄前請先把G3 PM2.5感測器的綠線不要插上，以避免RX port被佔用無法燒錄，燒錄成功後再插回）。接下來，您會在序列埠監控視窗看到如下的訊息。


說明：

[MR-1] 28,28,28,28,28,28 --> field1=28 → 溫度會丟到ThingSpeak的Field1

[MR-2] 38,38,38,38,38,38 --> field2=38 → 溼度會丟到ThingSpeak的Field2

[MR-7] CheckFailed 22,21,21,21,24,26 --> field3=20 → PM2.5會丟到ThingSpeak的Field3

[MR-8] 19,19,18,19,18,18 --> field4=18 → PM10會丟到ThingSpeak的Field4

[MR-9] 28,28,31,31,31,31 --> field5=29 → PM100溼度會丟到ThingSpeak的Field5

[MR-10] 854,854,854,854,854,854 --> field6=854 → CO2會丟到ThingSpeak的Field6

[MR-11] 138,150,158,167,173,178 --> field7=152 → 光照度會丟到ThingSpeak的Field7

所以，我們可以準備回到ThingSpeak的Channel設定頁面，將各Field的內容補充進去。

再次進入ThingSpeak，點選剛剛所建立的Channel，您應該會發現各個Field都有各自獨立的統計圖，且已經開始有資料進來了，您可以點選各Field圖示的修改按鈕，進行細部的修正，如Title、Y軸文字、上下限等等。例如下圖：


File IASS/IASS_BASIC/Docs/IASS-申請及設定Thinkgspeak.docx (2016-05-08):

# Thingspeak設定

# 組裝好，來申請個Thinkgspeak帳號吧！

要馬上看到感測裝置所搜集的資訊，以及各時段的記錄和變化曲線，除了自己架一台server來處理之外，最快也最方便的方式就是使用IoT平台了，有些IoT平台是免費的，而且可以替你繪出詳細的統計曲線，例如FreeBoard、ThingSpeak等等。

目前IASS系統支援ThingSpeak，在您註冊ThingSpeak帳號之後，便可將專屬的API KEY放在Arduino程式中，系統便會搜集到的資料直接上傳ThingSpeak繪製如下圖：

註冊帳號並登入之後，請先在My Channels當中建立一個新Channel，這個Channel您可以將它視為剛剛所組裝好的感測設備資料接收顯示端。


請依下圖所示來設定此Channel。


按下Save Channel按鈕後，會產生如下的畫面，這是此Channel的主頁面。


請按一下API Keys，然後記下Write API Key的值，稍後我們的感測裝置需要此Key來將資料上傳到此Channel。


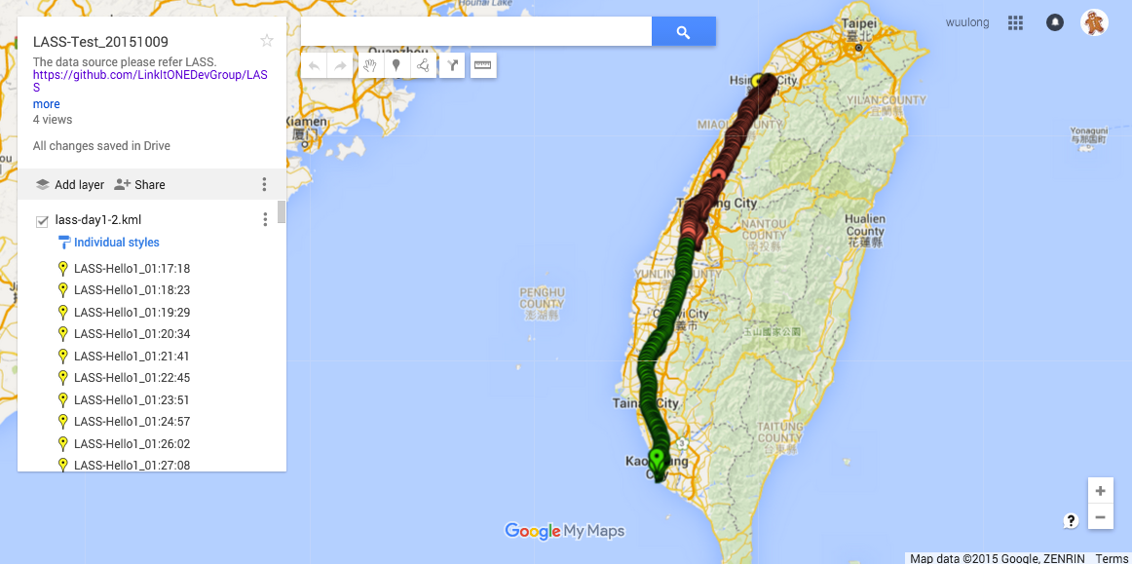
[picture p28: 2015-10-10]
Doc/LASS-20151009-day1.png

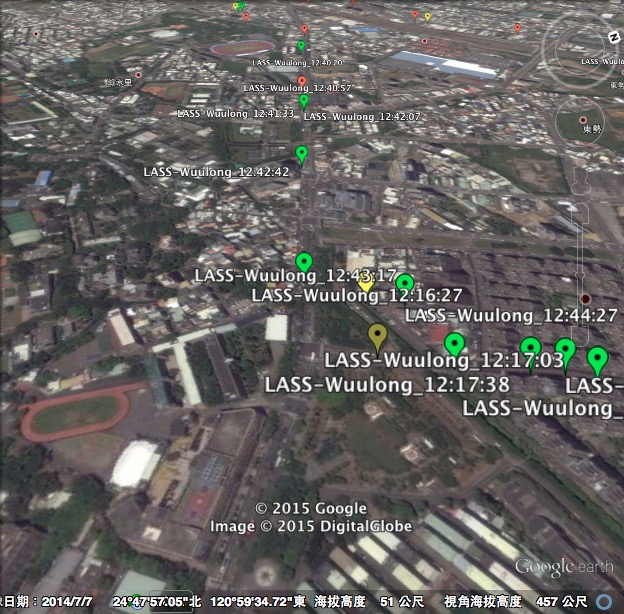
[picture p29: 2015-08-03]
Doc/DustSensor_Example3_ByGoogleEarth.jpg

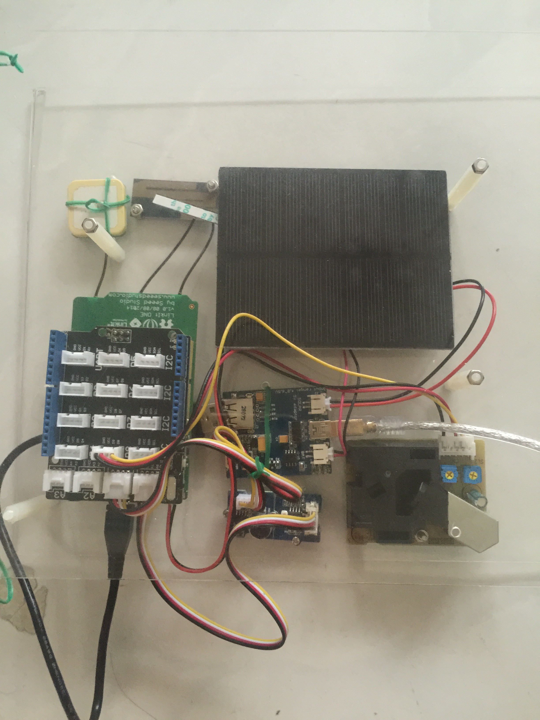
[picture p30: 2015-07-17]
Doc/DeviceExample3.jpg

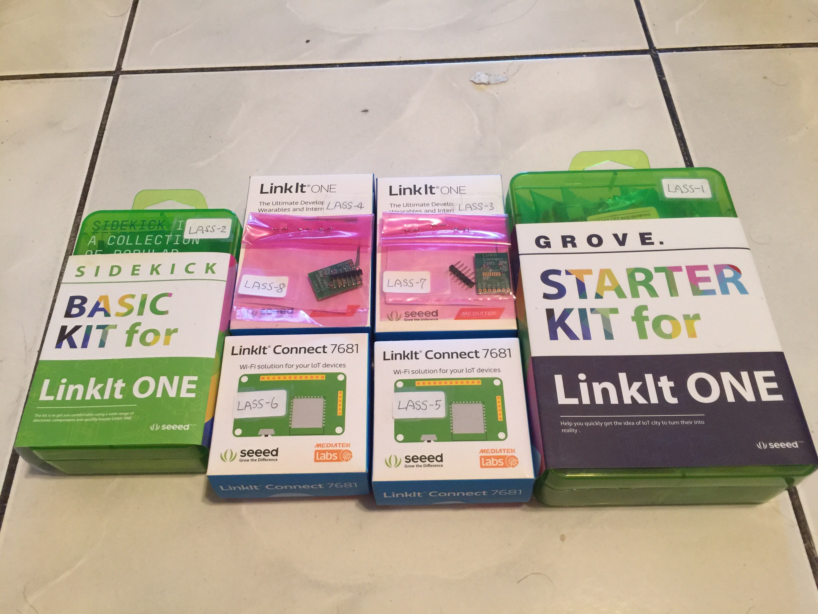
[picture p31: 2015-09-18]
Doc/Donation_20150919.JPG

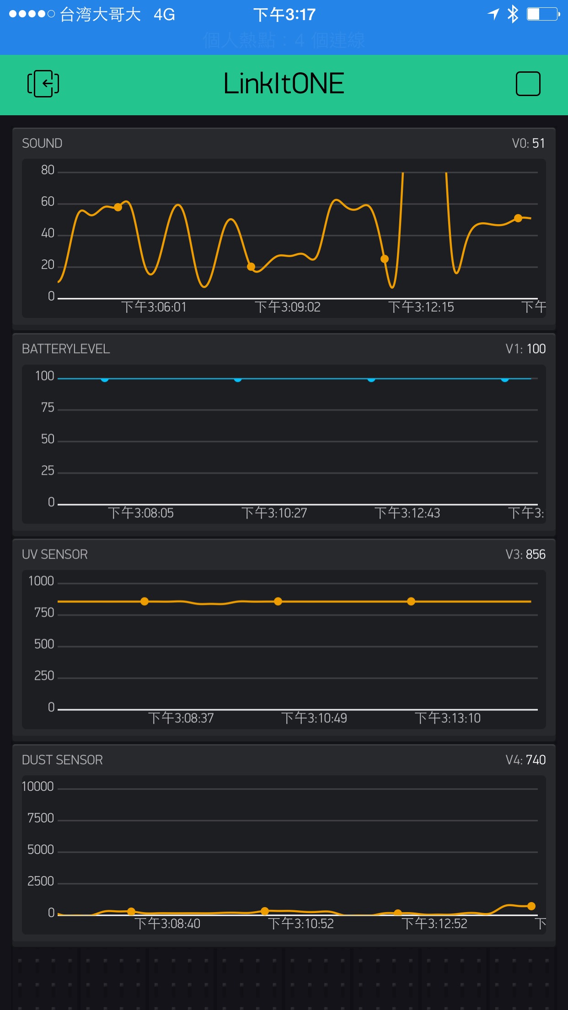
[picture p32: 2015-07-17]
Doc/Blynk_Example2.png

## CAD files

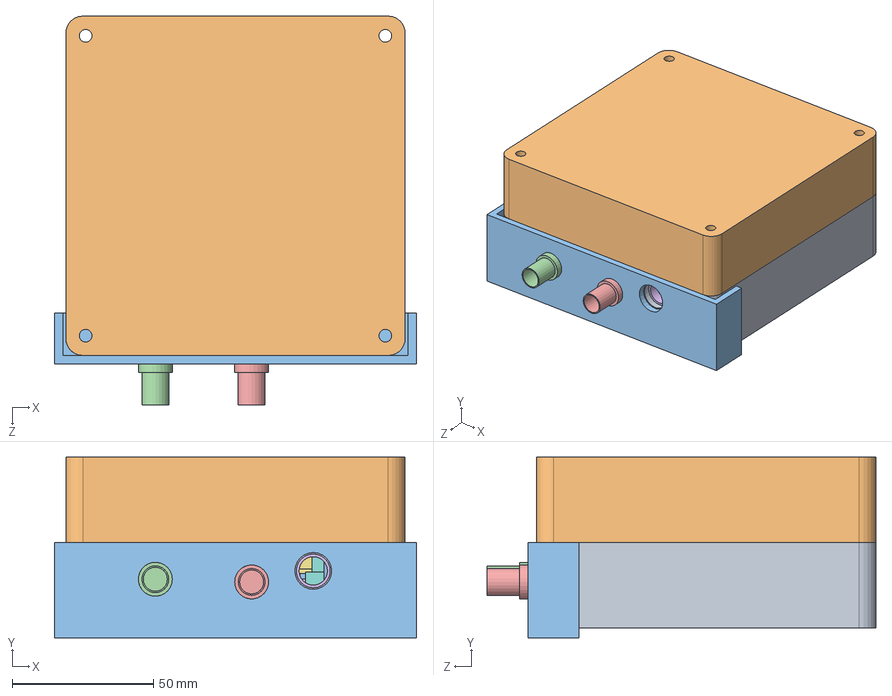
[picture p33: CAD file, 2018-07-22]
WaterBox/mechanical/design/水盒子G278C.SLDASM
128.0 x 63.9 x 137.5 mm
水質儀器_盒子G386
底層電池支架G278C
EC模組
pH模組
太陽能模組
溫度模組
超迷你開關
迷你塑膠扁柄開關

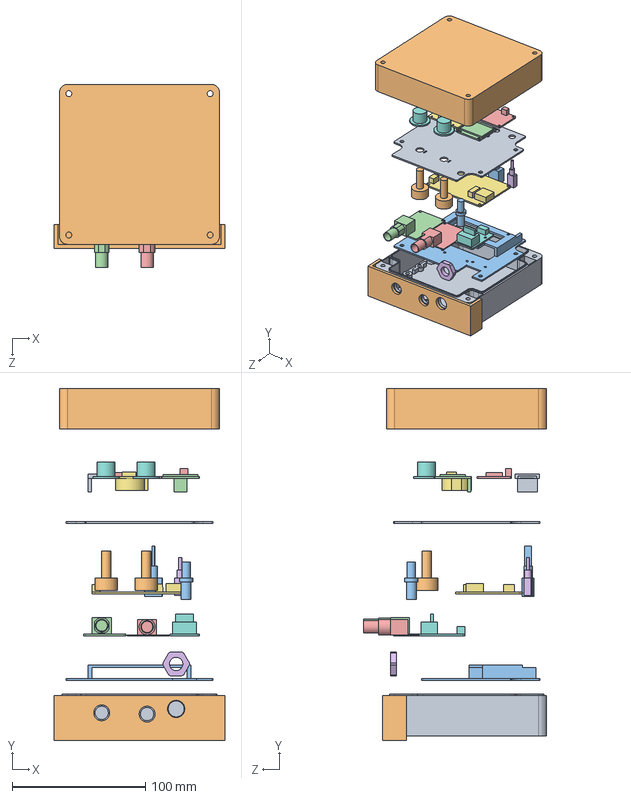
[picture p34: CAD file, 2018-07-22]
WaterBox/mechanical/3DP files/SolidWorks file/水盒子G278C.SLDASM
128.0 x 263.9 x 137.5 mm
水質儀器_盒子G386
水質儀器_盒子G386蓋子
底層電池支架G278C
EC模組
pH模組
迫緊接頭
太陽能模組
溫度模組
PCB板G278C
旋鈕 x 2
按鈕
OLED螢幕
MTDuino
超迷你開關
DS3231時間模組
旋鈕蓋 x 2
Q88 SD模組
G278C開孔支架
迷你塑膠扁柄開關

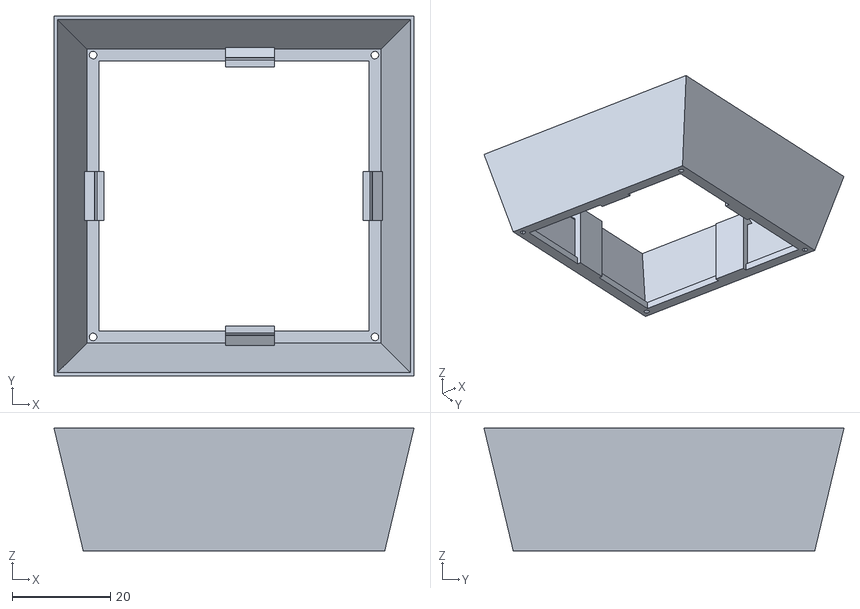
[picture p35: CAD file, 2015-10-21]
3dp/caseA_test.stl
73.4 x 73.4 x 25.0

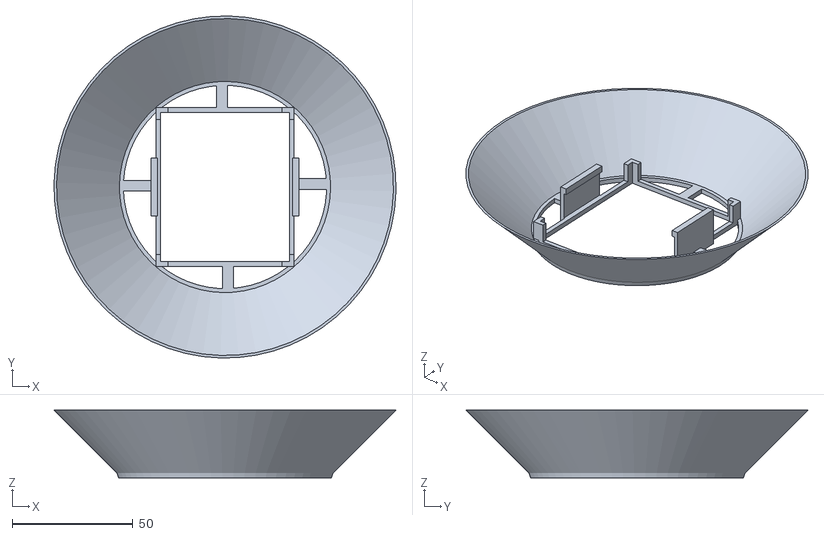
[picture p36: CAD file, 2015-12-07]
3dp/RODODO DESIGN/TOP1_CLEAN_NEW_fixed.stl
141.4 x 141.4 x 27.9

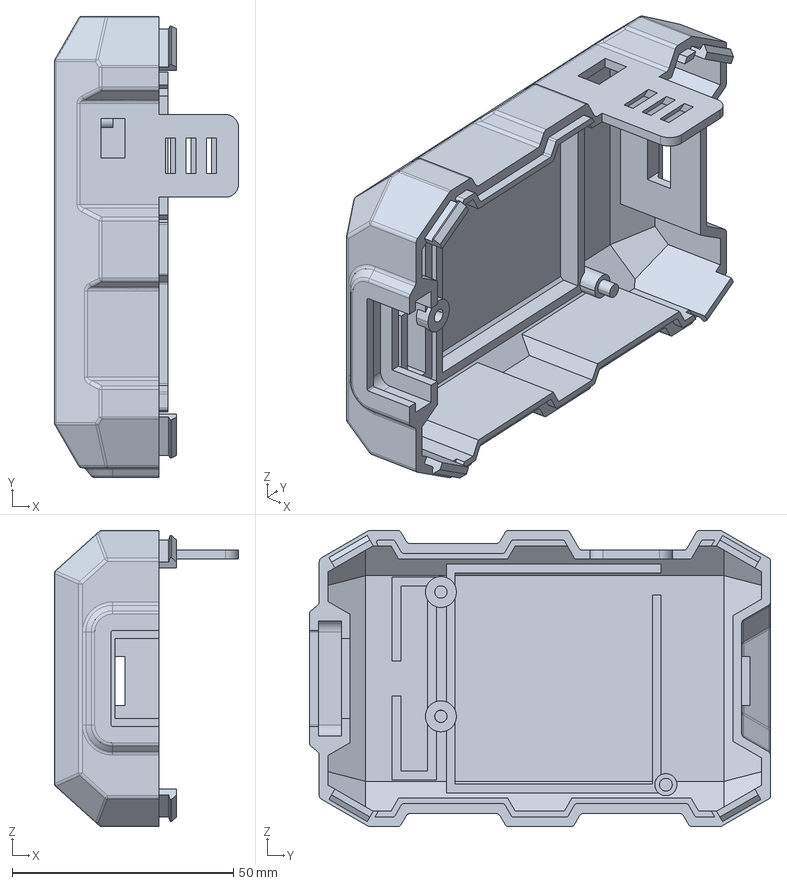
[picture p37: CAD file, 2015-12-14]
3dp/Scott_Chen/LASS cover Linkit One.igs
41.7 x 104.2 x 67.0 mm

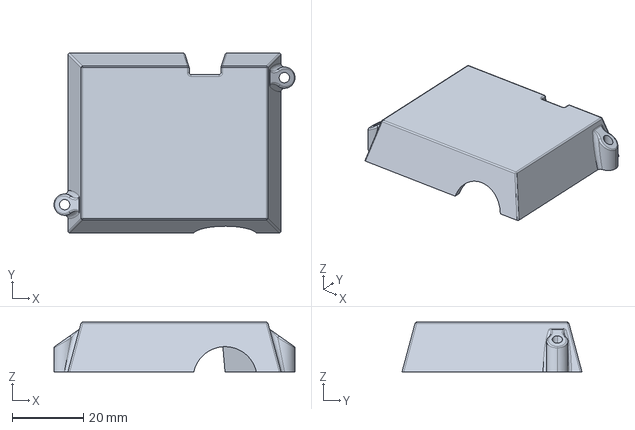
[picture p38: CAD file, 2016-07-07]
3dp/Scott_Chen/LASS4U/LASS4U BOX CAD/back cover.stp
67.9 x 50.7 x 14.0 mm

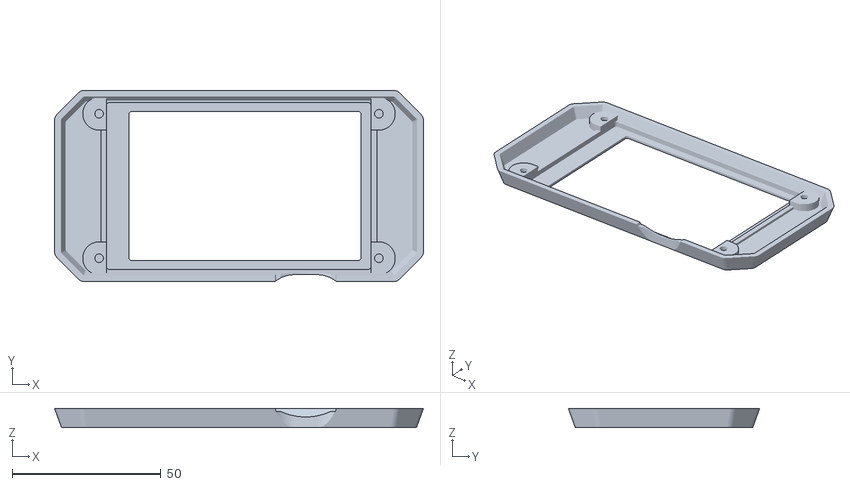
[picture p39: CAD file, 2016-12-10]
3dp/Scott_Chen/LASS4U/Lass4uV3modify/front cover(102616modify).STL
124.1 x 64.4 x 6.50

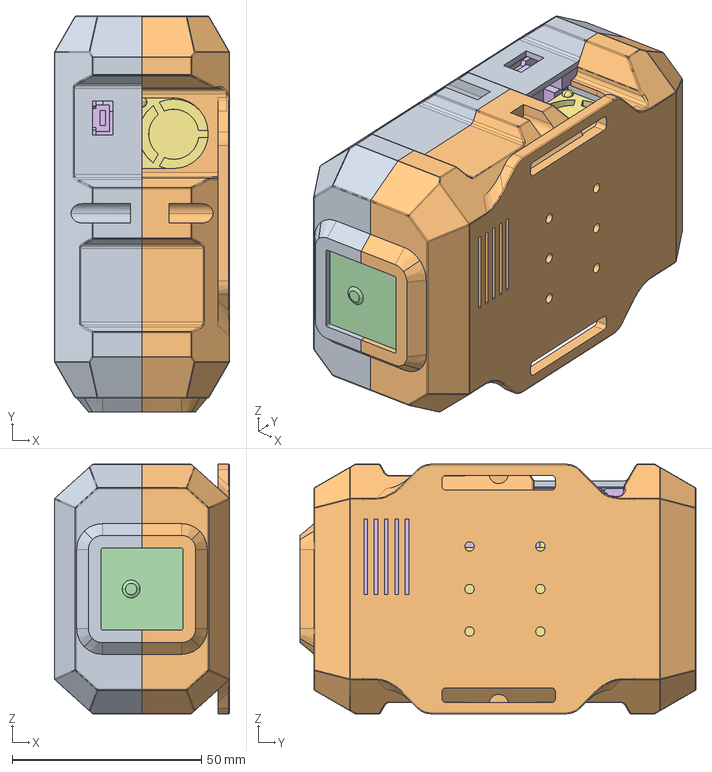
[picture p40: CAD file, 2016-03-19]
3dp/Scott_Chen/LASS_V3.1_Cover/3D CAD/LASS BOX ver3_1.stp
46.3 x 104.7 x 66.0 mm

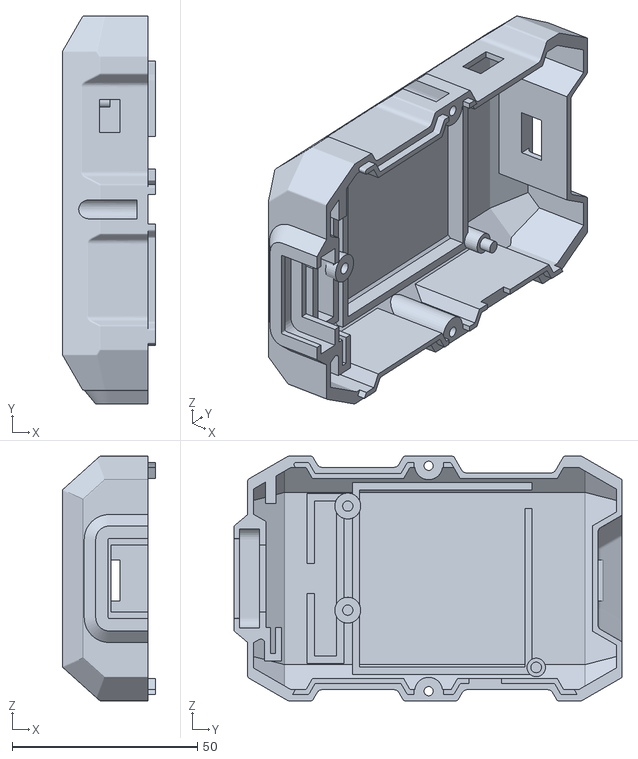
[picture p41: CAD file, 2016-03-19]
3dp/Scott_Chen/LASS_V3.1_Cover/for 3D printer/LASS BOX ver3_1 PCB side.stl
25.1 x 104.7 x 66.0

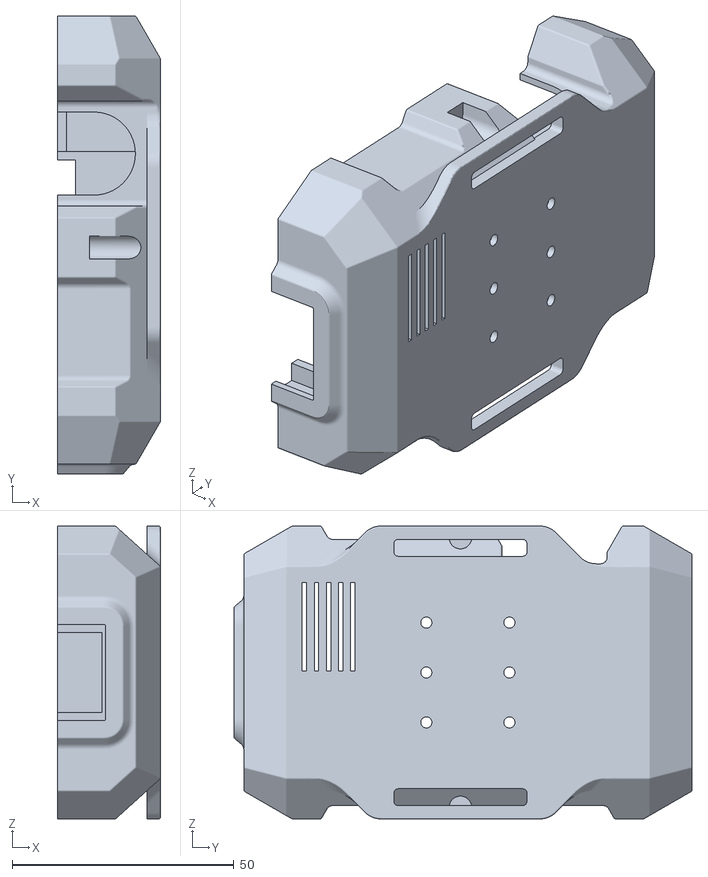
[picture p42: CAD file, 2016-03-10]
3dp/Scott_Chen/LASS_V3/for 3D printer/LASS BOX ver3 G3 side.stl
23.1 x 103.2 x 66.0

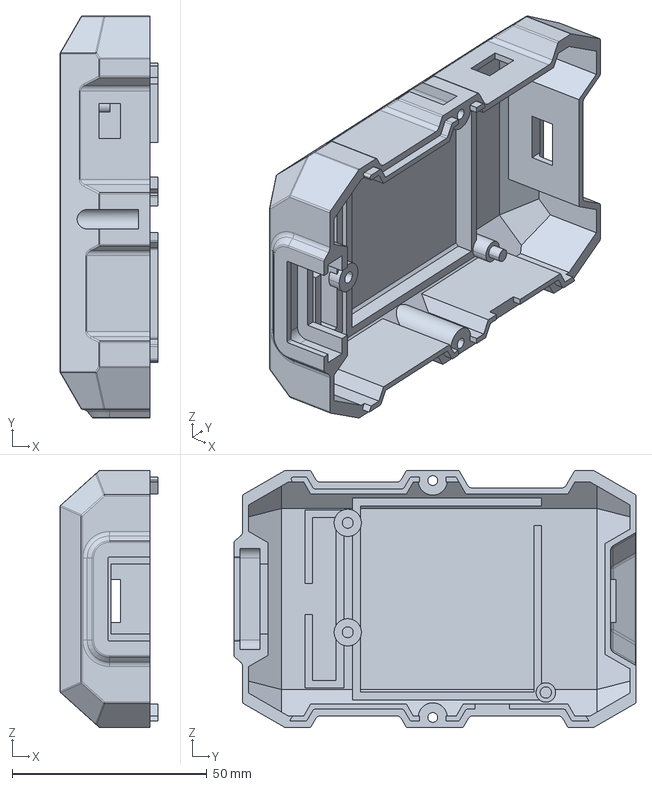
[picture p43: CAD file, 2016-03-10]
3dp/Scott_Chen/LASS_V3/LASS BOX ver3 PCB side.stp
25.1 x 103.2 x 66.0 mm

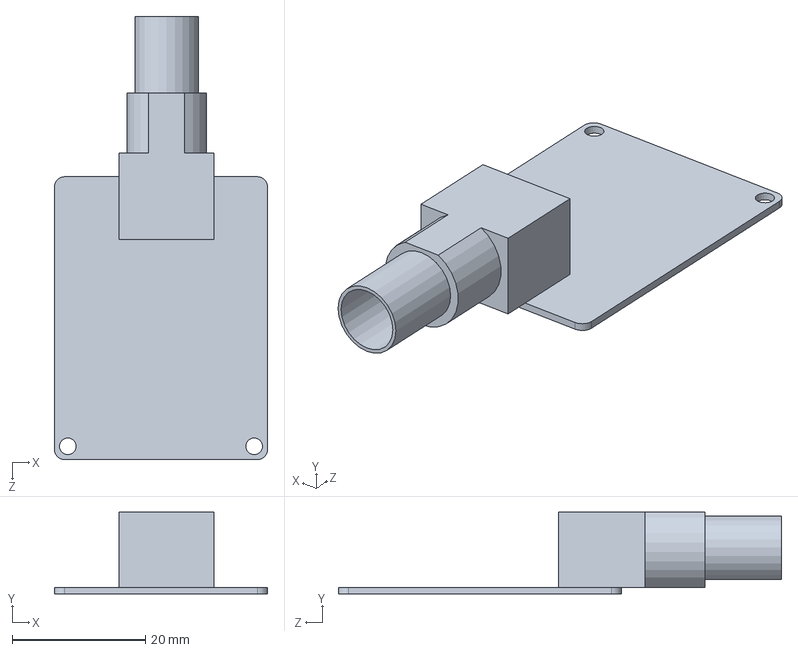
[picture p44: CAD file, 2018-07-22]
WaterBox/mechanical/3DP files/SolidWorks file/pH模組.sldprt
32.0 x 12.3 x 66.6 mm

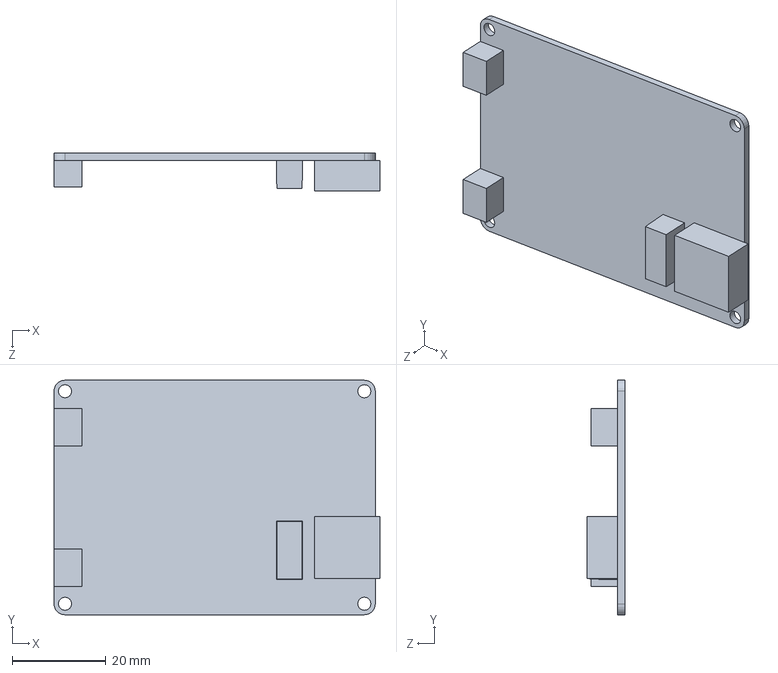
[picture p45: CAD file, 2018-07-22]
WaterBox/mechanical/design/太陽能模組.sldprt
69.5 x 50.0 x 8.00 mm

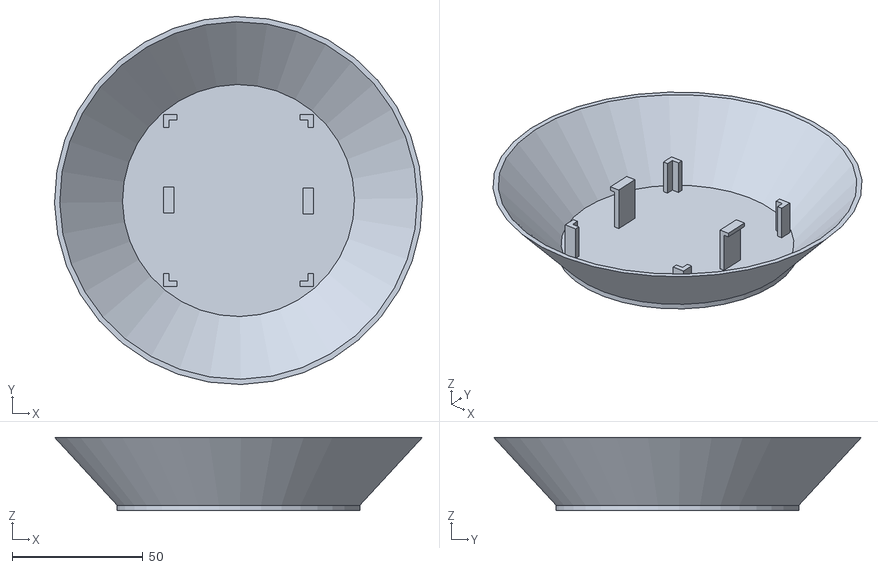
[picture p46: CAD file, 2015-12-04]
3dp/RODODO DESIGN/TOP2_CLEAN_NEW.stl
140.7 x 140.7 x 28.0

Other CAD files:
3dp/Scott_Chen/LASS G3.igs
3dp/Scott_Chen/LASS4U/LASS4U BOX CAD/Cover.stp
3dp/Scott_Chen/LASS_V3.1_Cover/for 3D printer/LASS BOX ver3_1 G3 side.stl
3dp/Scott_Chen/LASS_V3/LASS BOX ver3 over view.stp
3dp/RODODO DESIGN/FRAMELIFT_FINAL.skp
3dp/RODODO DESIGN/FRAMELIFT_FINAL.stl
3dp/RODODO DESIGN/FRAME_V21_MAX_FINAL.skp
3dp/RODODO DESIGN/FRAME_V21_MAX_FINAL.stl
3dp/RODODO DESIGN/TOP1_CLEAN_NEW.skp
3dp/RODODO DESIGN/TOP2_CLEAN_NEW.skp
3dp/Scott_Chen/LASS G3.stl
3dp/Scott_Chen/LASS cover Linkit One.stl
3dp/Scott_Chen/LASS4U/LASS4U BOX CAD/BOX_back.CATPart
3dp/Scott_Chen/LASS4U/LASS4U BOX CAD/BOX_back.stl
3dp/Scott_Chen/LASS4U/LASS4U BOX CAD/BOX_back.stp
3dp/Scott_Chen/LASS4U/LASS4U BOX CAD/BOX_front.CATPart
3dp/Scott_Chen/LASS4U/LASS4U BOX CAD/BOX_front.stl
3dp/Scott_Chen/LASS4U/LASS4U BOX CAD/BOX_front.stp
3dp/Scott_Chen/LASS4U/LASS4U BOX CAD/Cover.CATPart
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

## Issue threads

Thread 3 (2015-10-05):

Blynk seamless integration

vshymanskyy, 2015-10-05:
I see that you include a workaround for Blynk library:
```
#define ARDUINO 150 // to avoid Blynk library use yield() in function run(), without this. system will crash!
```
We at Blynk could integrate it into our library, but I need to now if there is a specific #define that is set only for LinkIt ONE, to detect this situation.
Also, it would be good for us to get a device sample to do testing on our side. Whom can we contact regarding this question? Thx.

wuulong, 2015-10-05:
Volodymyr Shymanskyy,

It's me, wuulong. Sorry for wait so long time to verify your new version.
As current my understand, Blynk only need to avoid to use yield() when
device type as LinkItONE. This work around should be able to remove, and
others LinkItONE user will not get this trouble.

Personally, I agree that if you get one device and can be maintain this
device in Blynk, that will be perfect. But I can't sent you device because
I don't have more. I will post your request into the group in FB to see if
someone can send you device. Let see if this work first.

10/3, The LASS demo Blynk interface in the Mini Maker Faire Hsinchu. Thanks
your great job to make this possible.

Wuulong
ps: this is the FB group, https://www.facebook.com/groups/1641811569367039/

On Tue, Oct 6, 2015 at 5:58 AM, Volodymyr Shymanskyy <
notifications@github.com> wrote:

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

--
許武龍 ( wuulong )
專業認證：IBM Certificated Linux Trainer for  LPIC, Security
Engineer(TWCERT/CC), JAVA Programmer(SCJP)
Interest: Maker, Embedded System, Robotics

kg6hxm, 2015-10-06:
I could send one from Denver. Where would it be going?

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

wuulong, 2015-10-06:
Volodymyr Shymanskyy,

    Great news! You got MTK Lab's donation. LinktITONE*1( at least ).
    Please provide your delivery information ( Maybe send to
wuulong@gmail.com )

  To make better support to you, I will provide the  contact of MTK Lab to
you.

This is my FB, you can add friend if you like.
https://www.facebook.com/wuulong.hsu

   I can feel we all thanks your work and hope you can continue to support
LinkItONE.

   Best Regards, Wuulong.

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

--
許武龍 ( wuulong )
專業認證：IBM Certificated Linux Trainer for  LPIC, Security
Engineer(TWCERT/CC), JAVA Programmer(SCJP)
Interest: Maker, Embedded System, Robotics

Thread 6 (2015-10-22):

lass.py enhancement

wjmuse, 2015-10-22:
1. Enable to set filter to let KML or JSON to appear only one type of sensor value on map place spot.
2. Filter should support device id or sensor id.
3. Fix lass.R to do some visualization.

wuulong, 2015-10-22:
&1 : Suggest to export all datas. And highlight one special sensor which is sensor_curr in the lass.py
&2 : Remind current lass.py already support device_id filter. What is sensor_id? The specification suggest to enable regular expression filter for the data. These method will have more flexible filter option
&3 : What problem you saw in current lass.R?

wjmuse, 2015-10-26:
@wuulong Thanks for your comment.
&1, &2, I think *sensor_curr* should be able to used as what I've thought about sensor filter. I'll follow up this as your suggestion.
&3, It may not has any problem, just make a note for myself to do some enhancement for new *ver_app*. :)

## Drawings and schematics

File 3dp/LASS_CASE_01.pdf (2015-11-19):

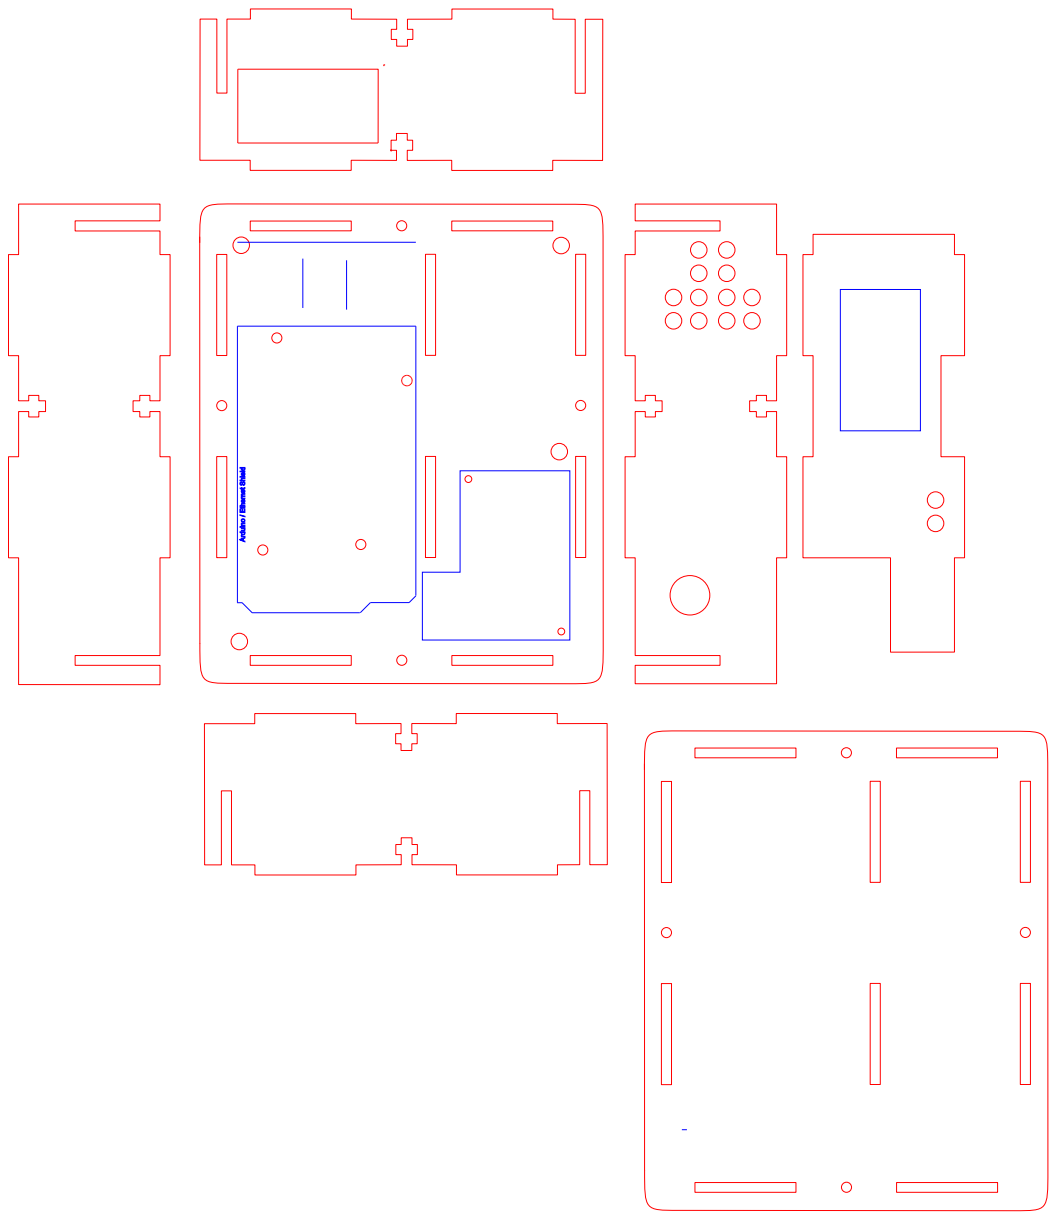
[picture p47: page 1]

Arduino / Ethernet Shield

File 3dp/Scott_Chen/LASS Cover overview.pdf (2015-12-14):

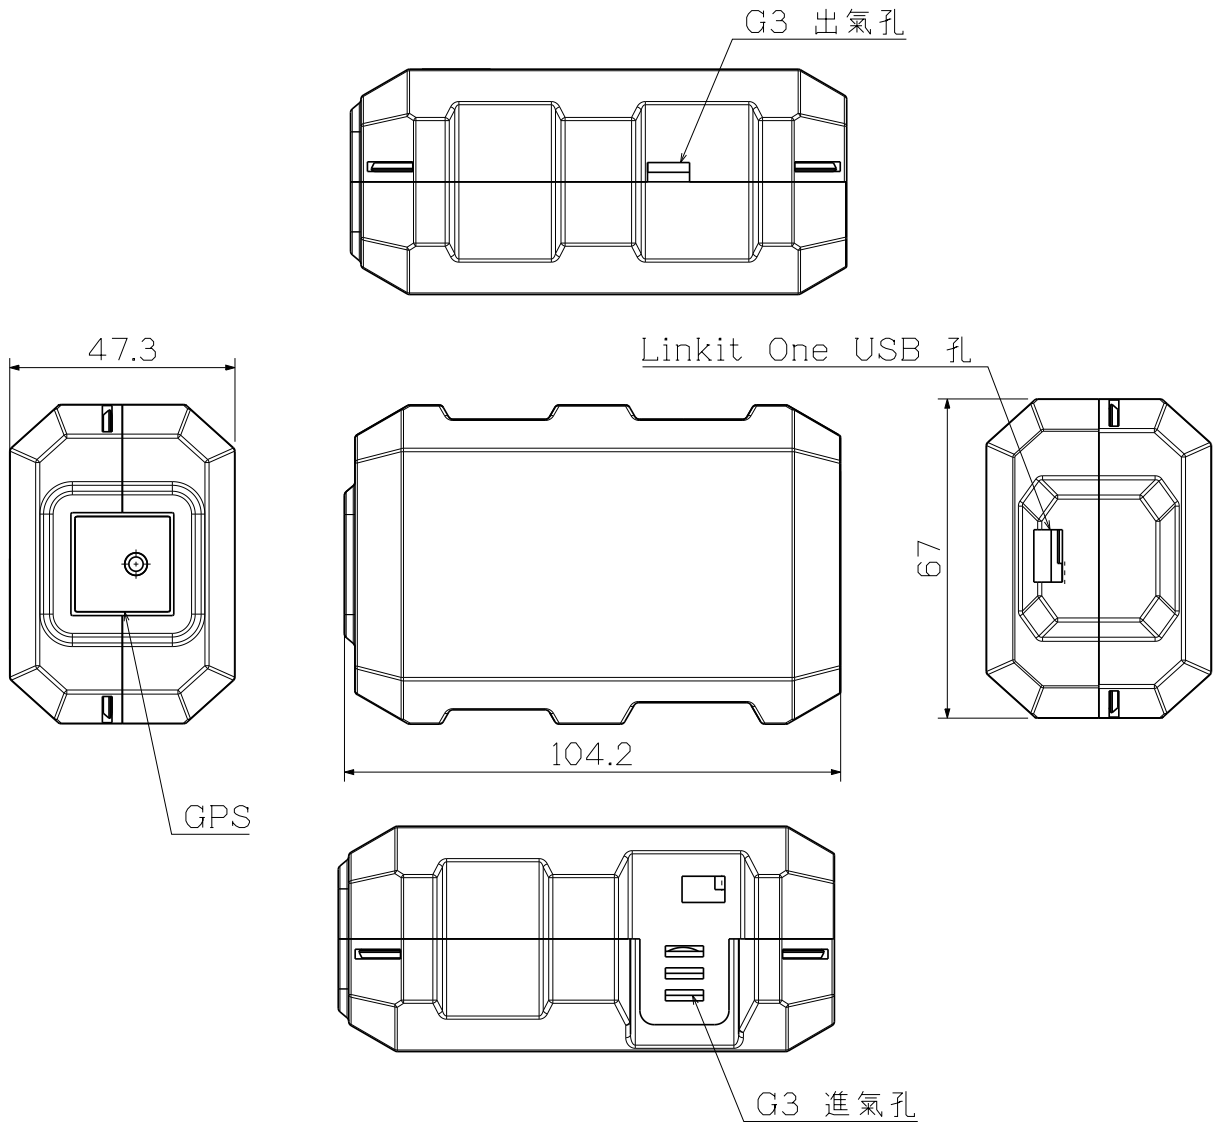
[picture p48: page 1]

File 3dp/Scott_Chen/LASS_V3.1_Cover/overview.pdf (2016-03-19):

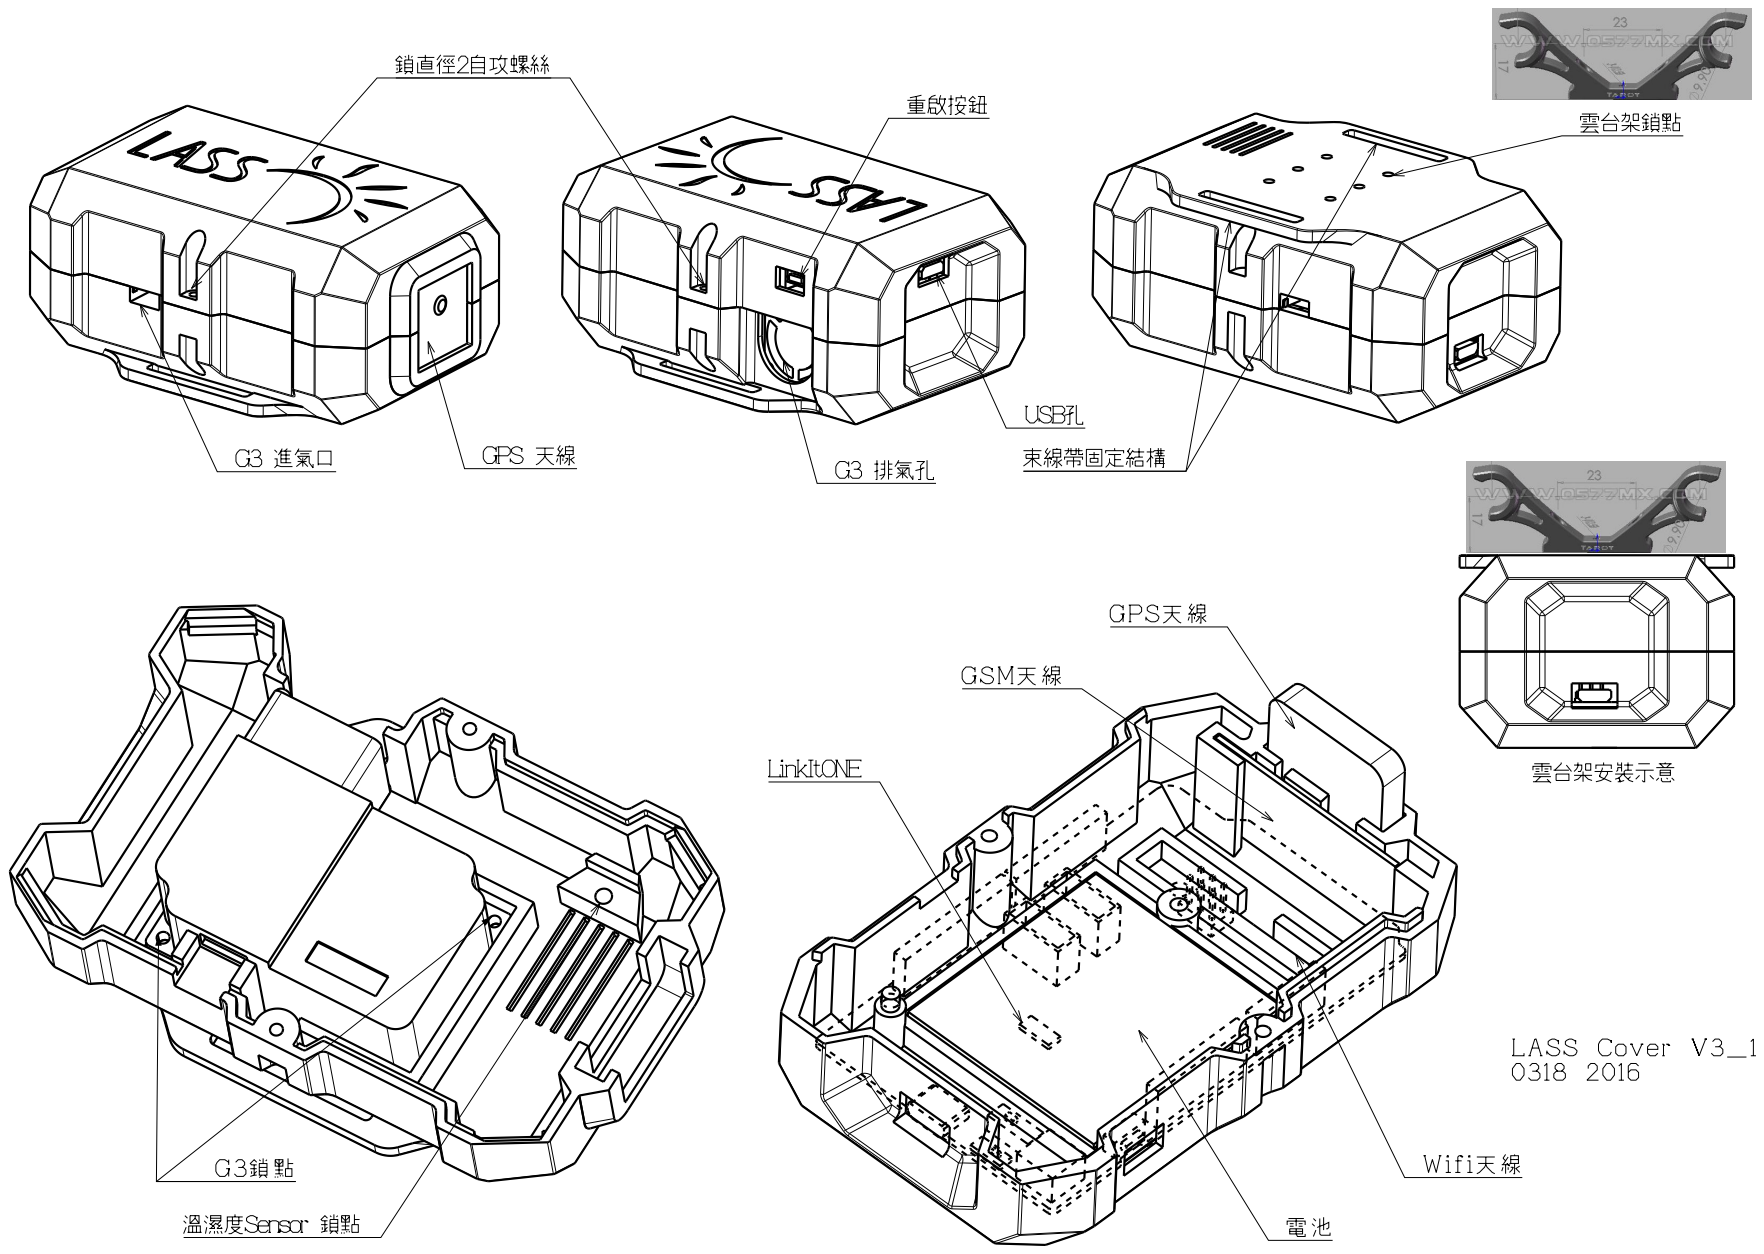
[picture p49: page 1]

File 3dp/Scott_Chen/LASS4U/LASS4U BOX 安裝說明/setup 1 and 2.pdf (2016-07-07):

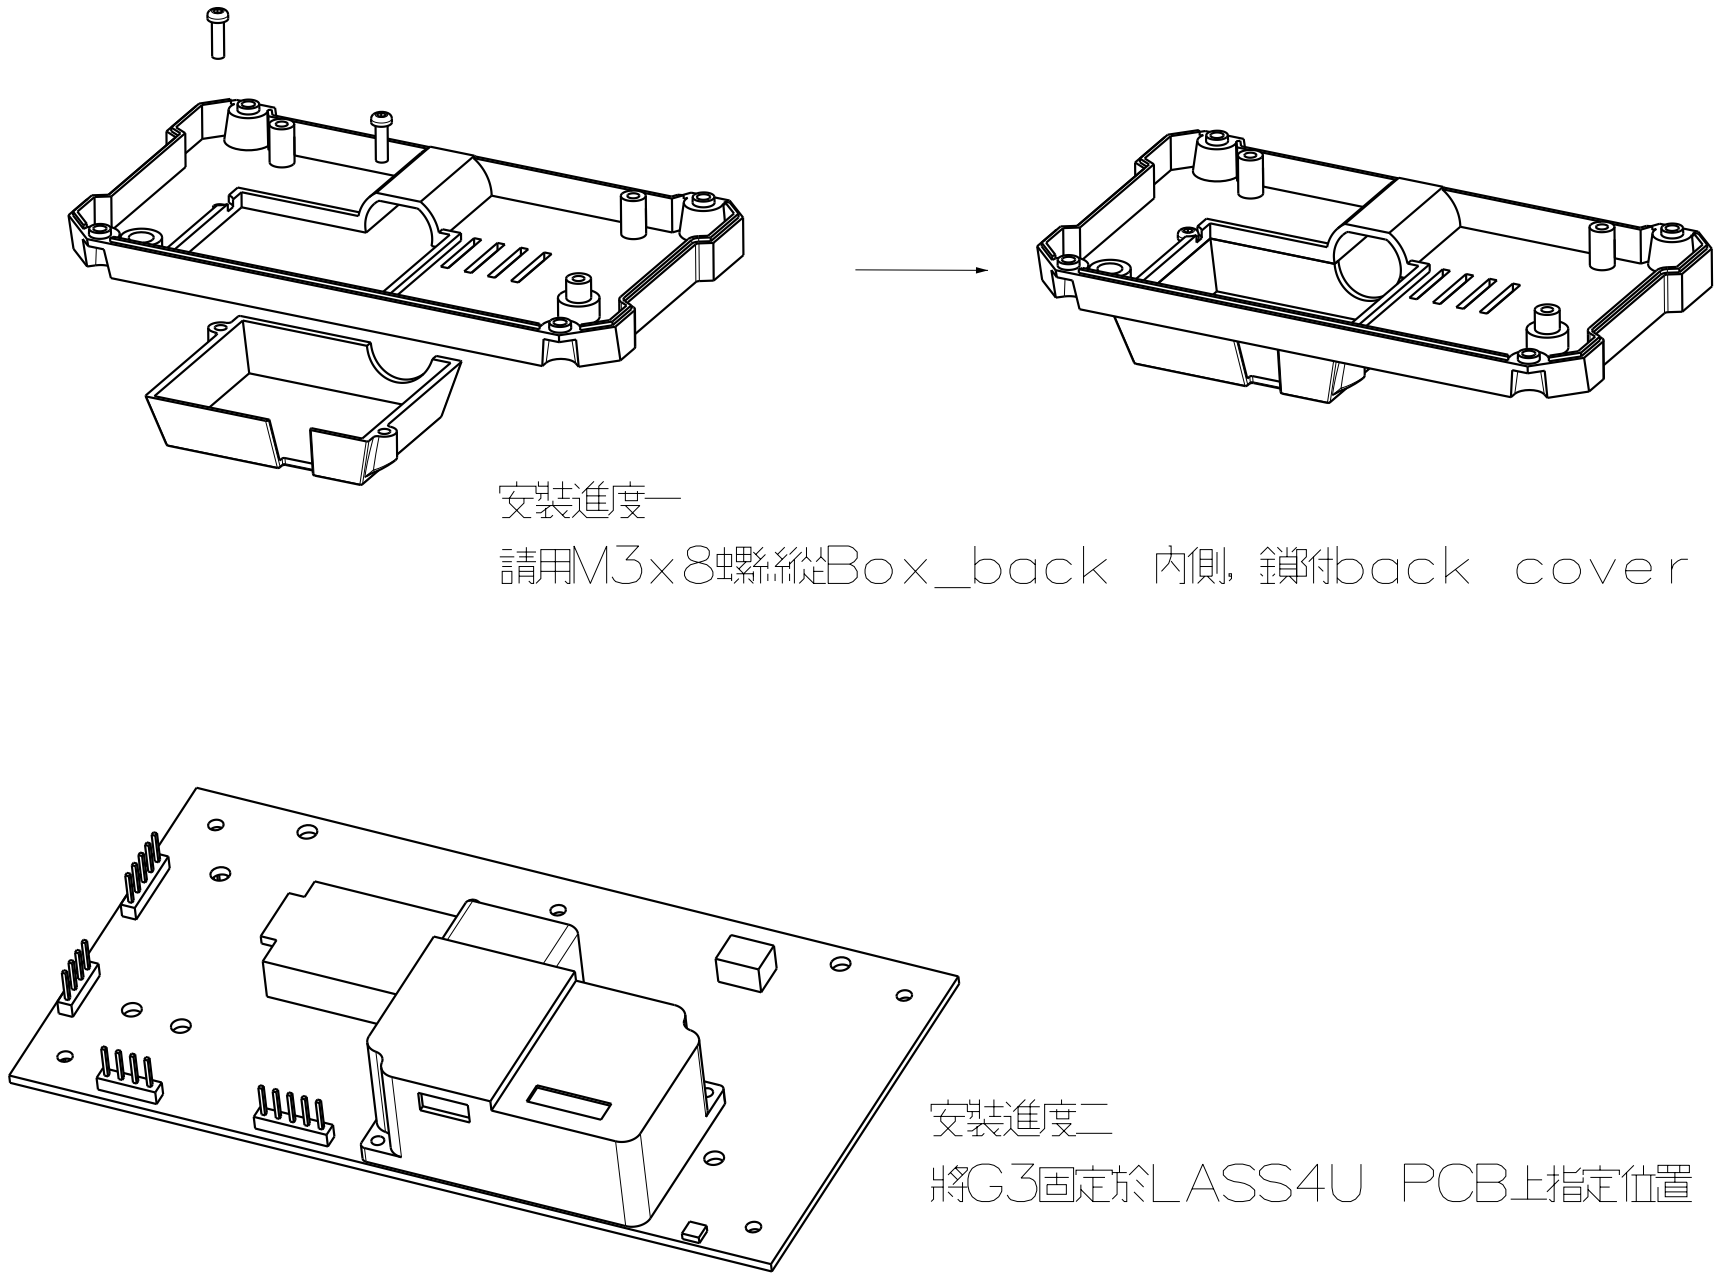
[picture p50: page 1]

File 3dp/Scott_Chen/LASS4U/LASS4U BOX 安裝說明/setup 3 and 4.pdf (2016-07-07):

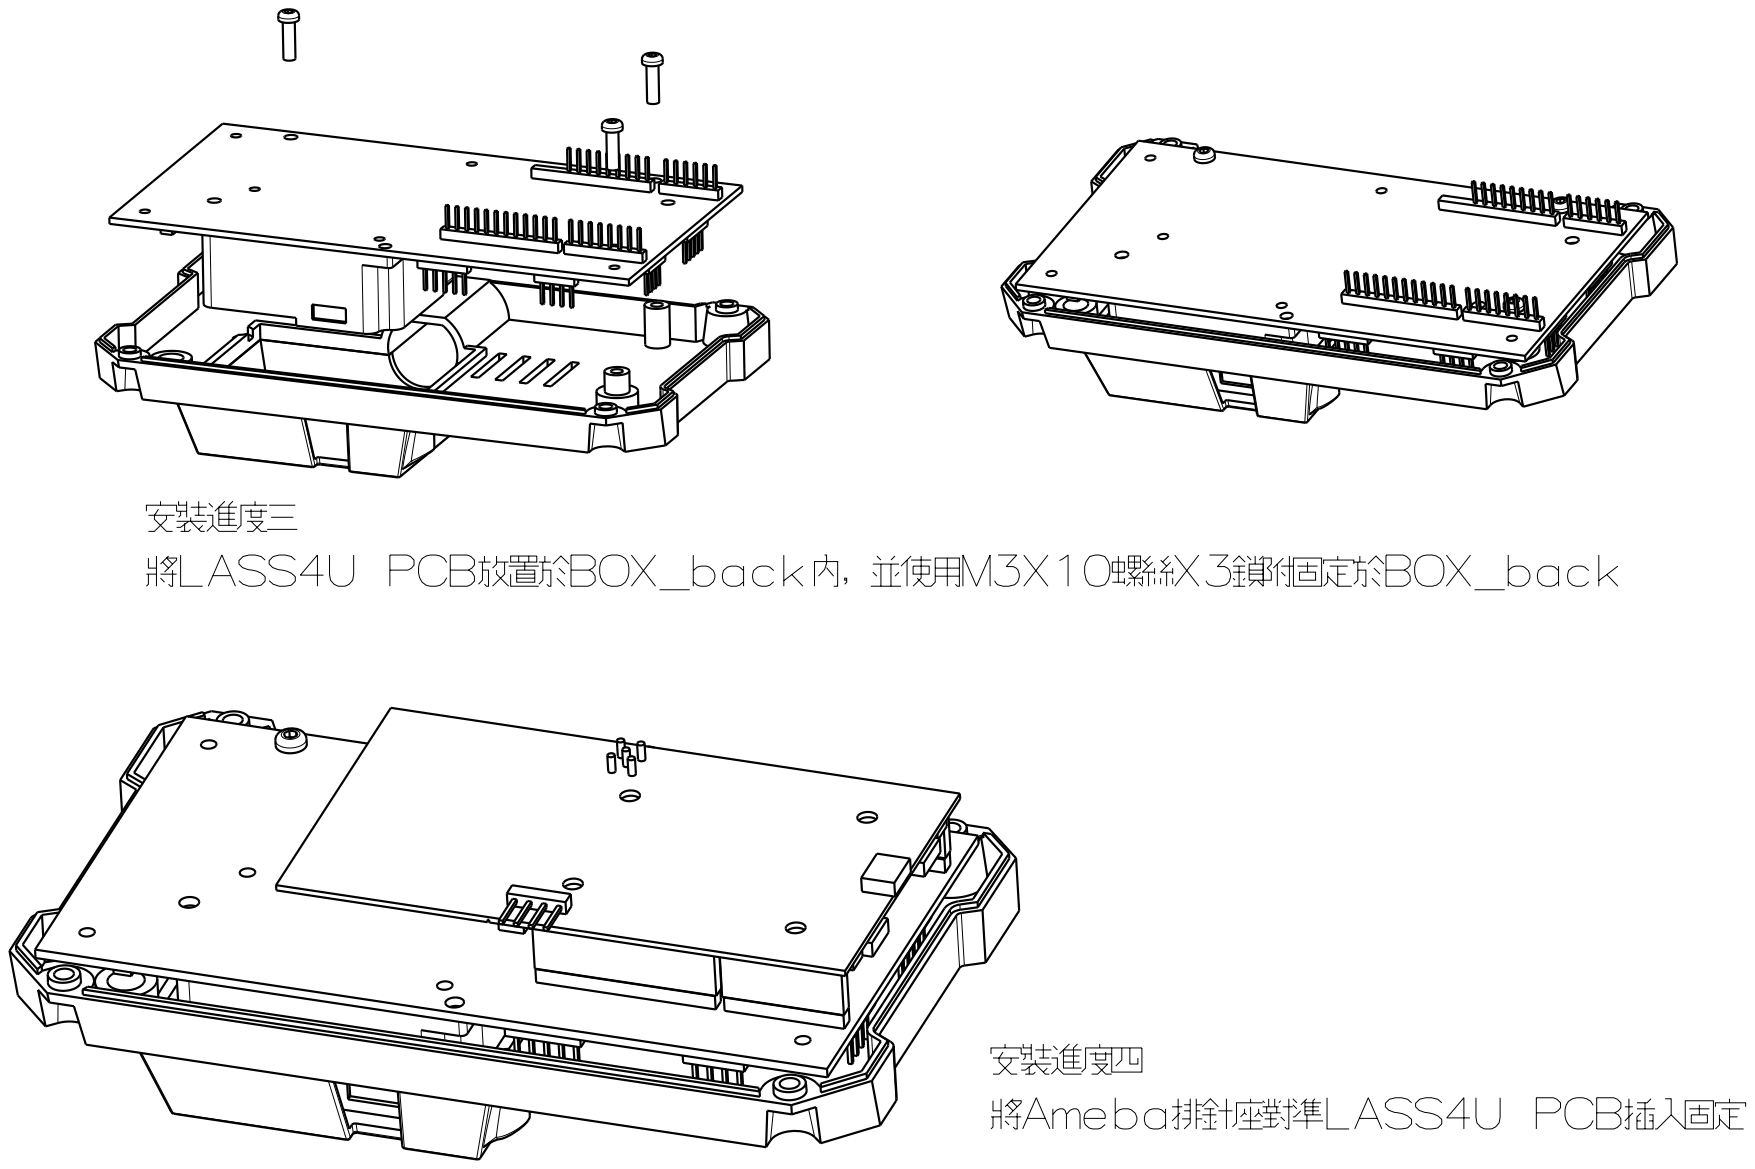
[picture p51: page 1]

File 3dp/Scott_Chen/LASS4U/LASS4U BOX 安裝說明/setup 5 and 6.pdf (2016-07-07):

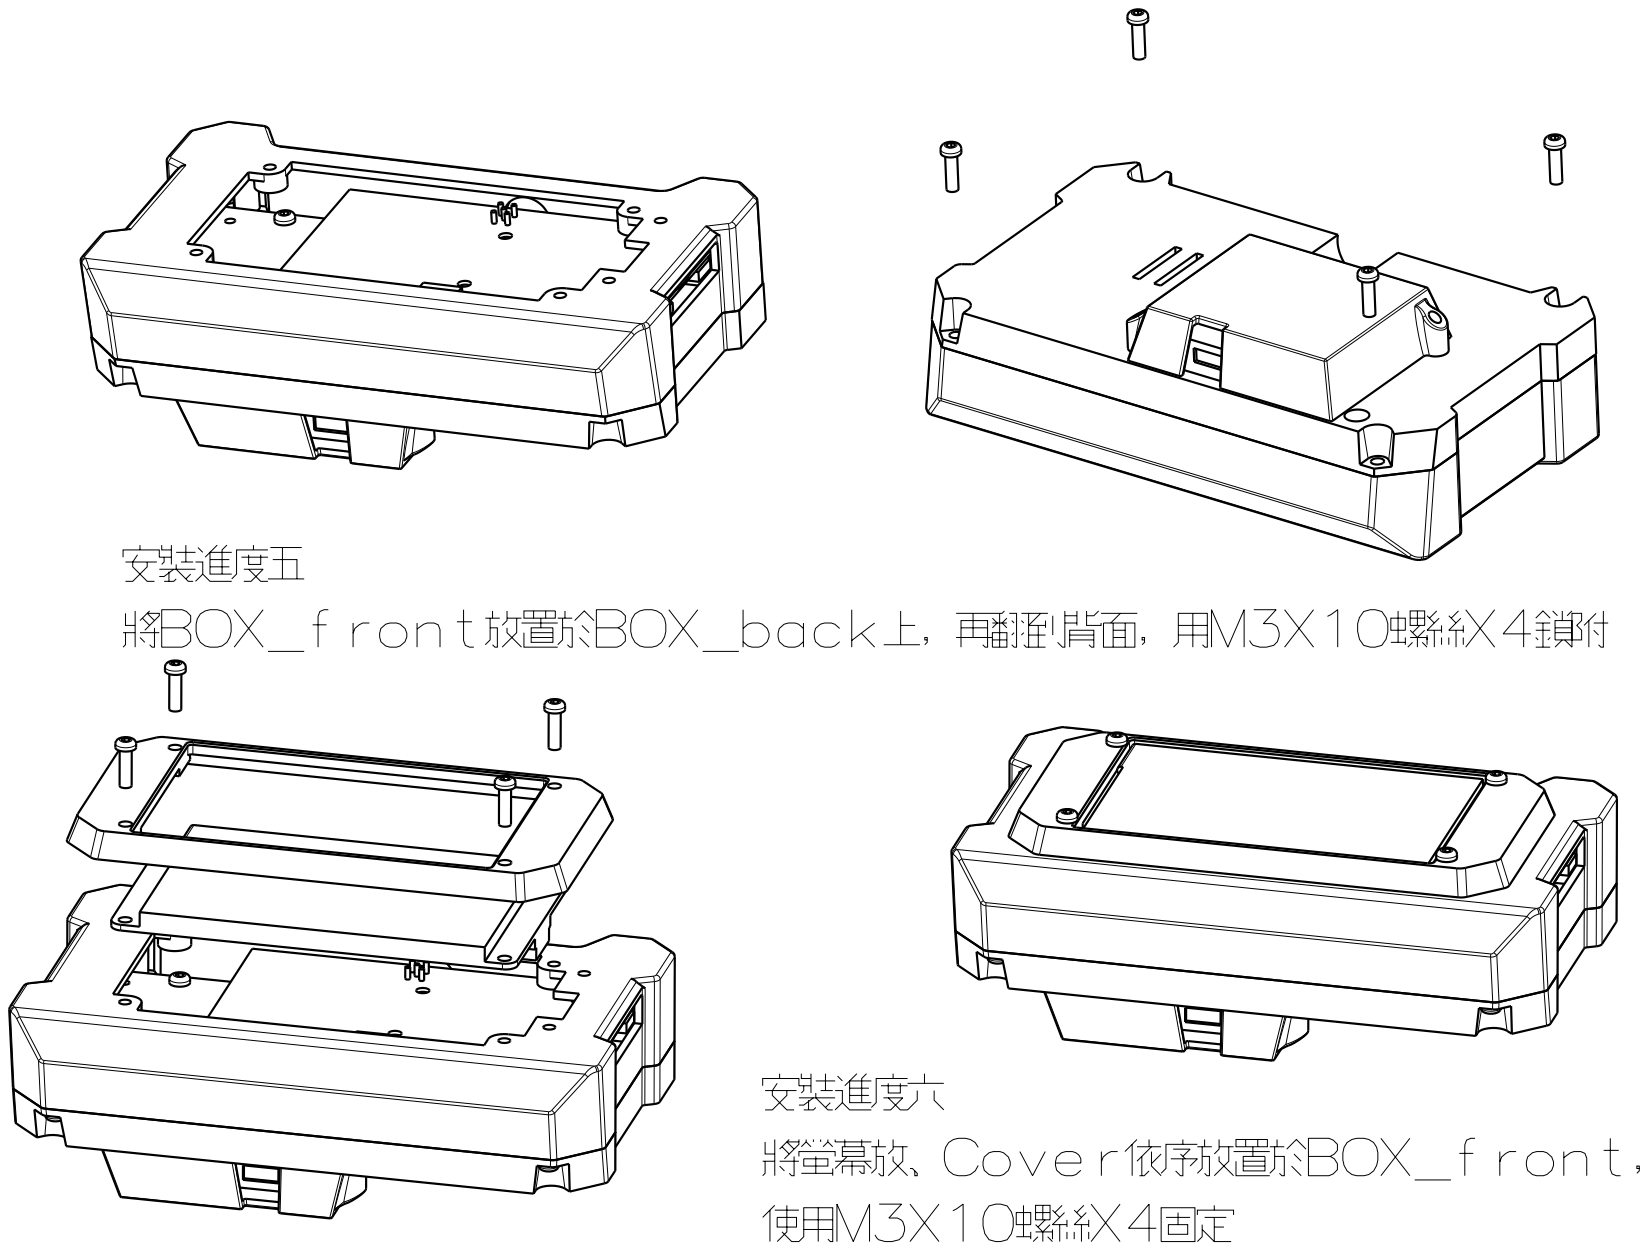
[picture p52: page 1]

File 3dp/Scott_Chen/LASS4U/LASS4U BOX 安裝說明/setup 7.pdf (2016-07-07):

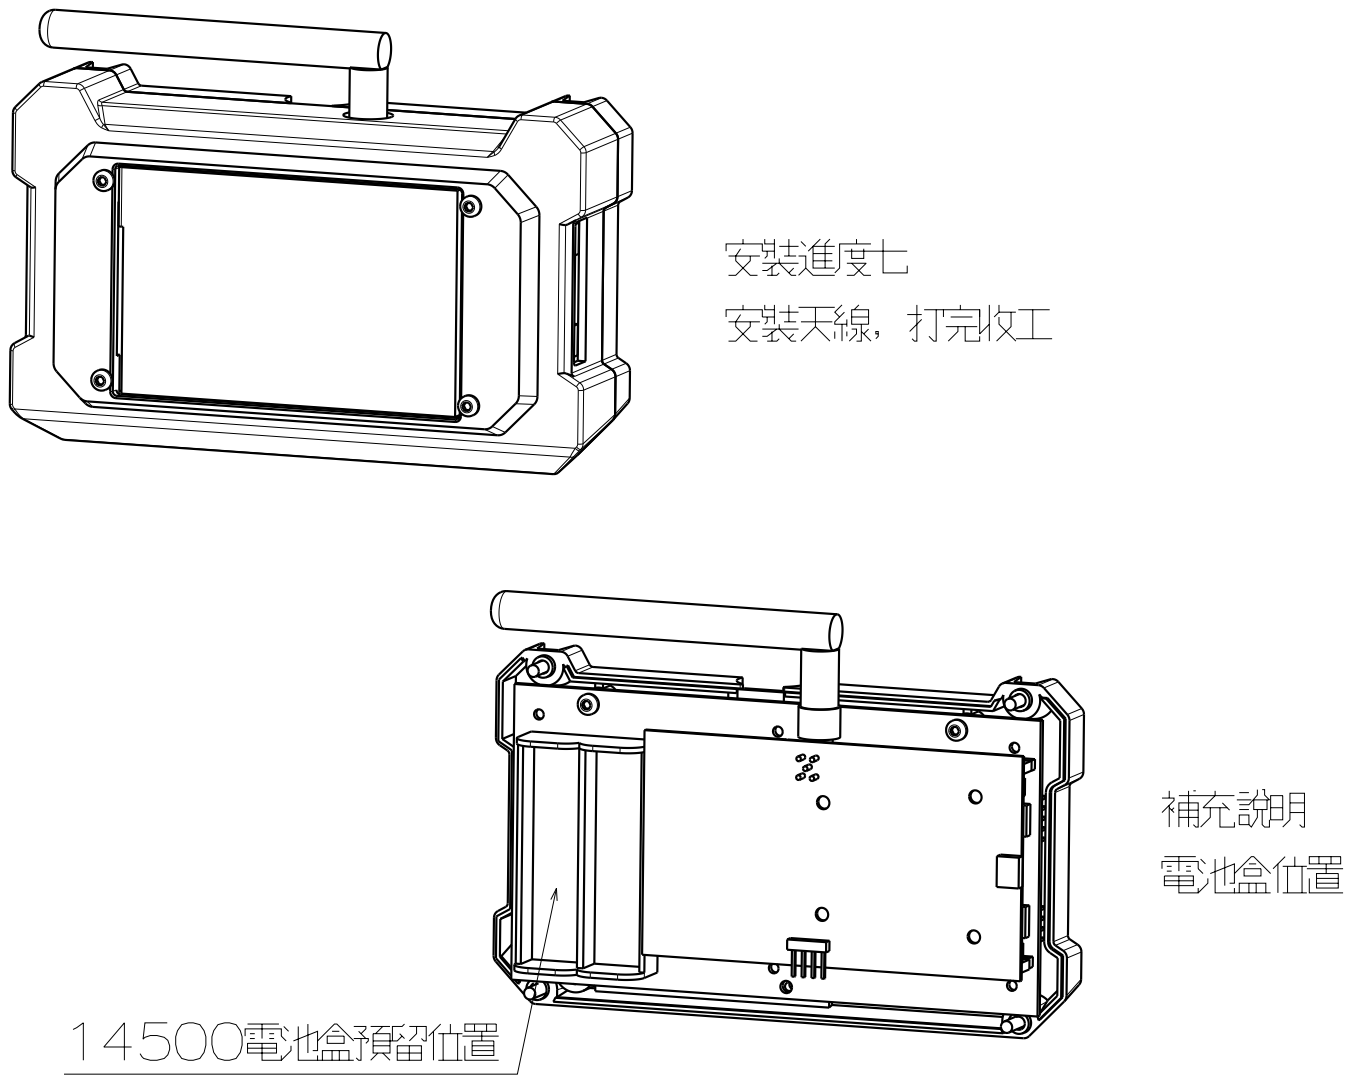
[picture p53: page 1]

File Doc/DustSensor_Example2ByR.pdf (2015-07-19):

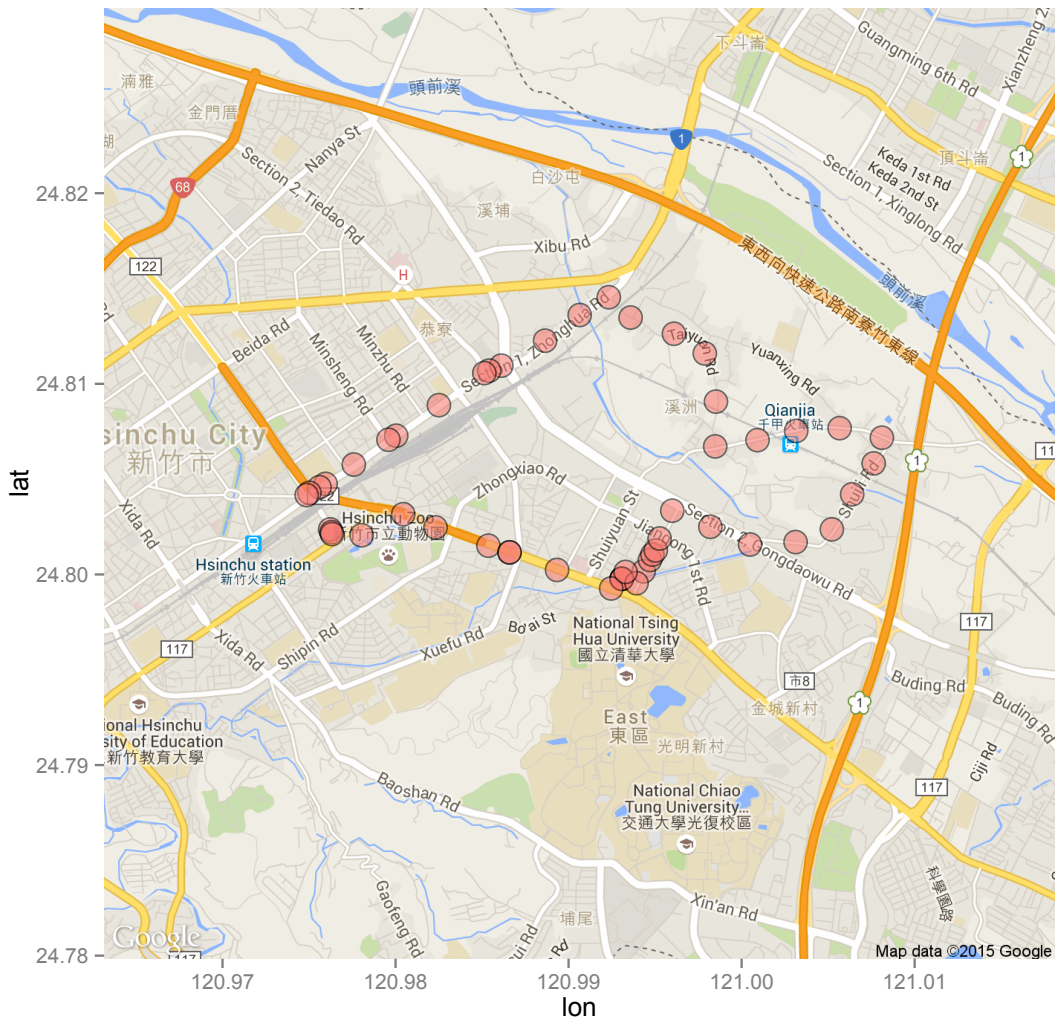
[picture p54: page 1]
lon; lat

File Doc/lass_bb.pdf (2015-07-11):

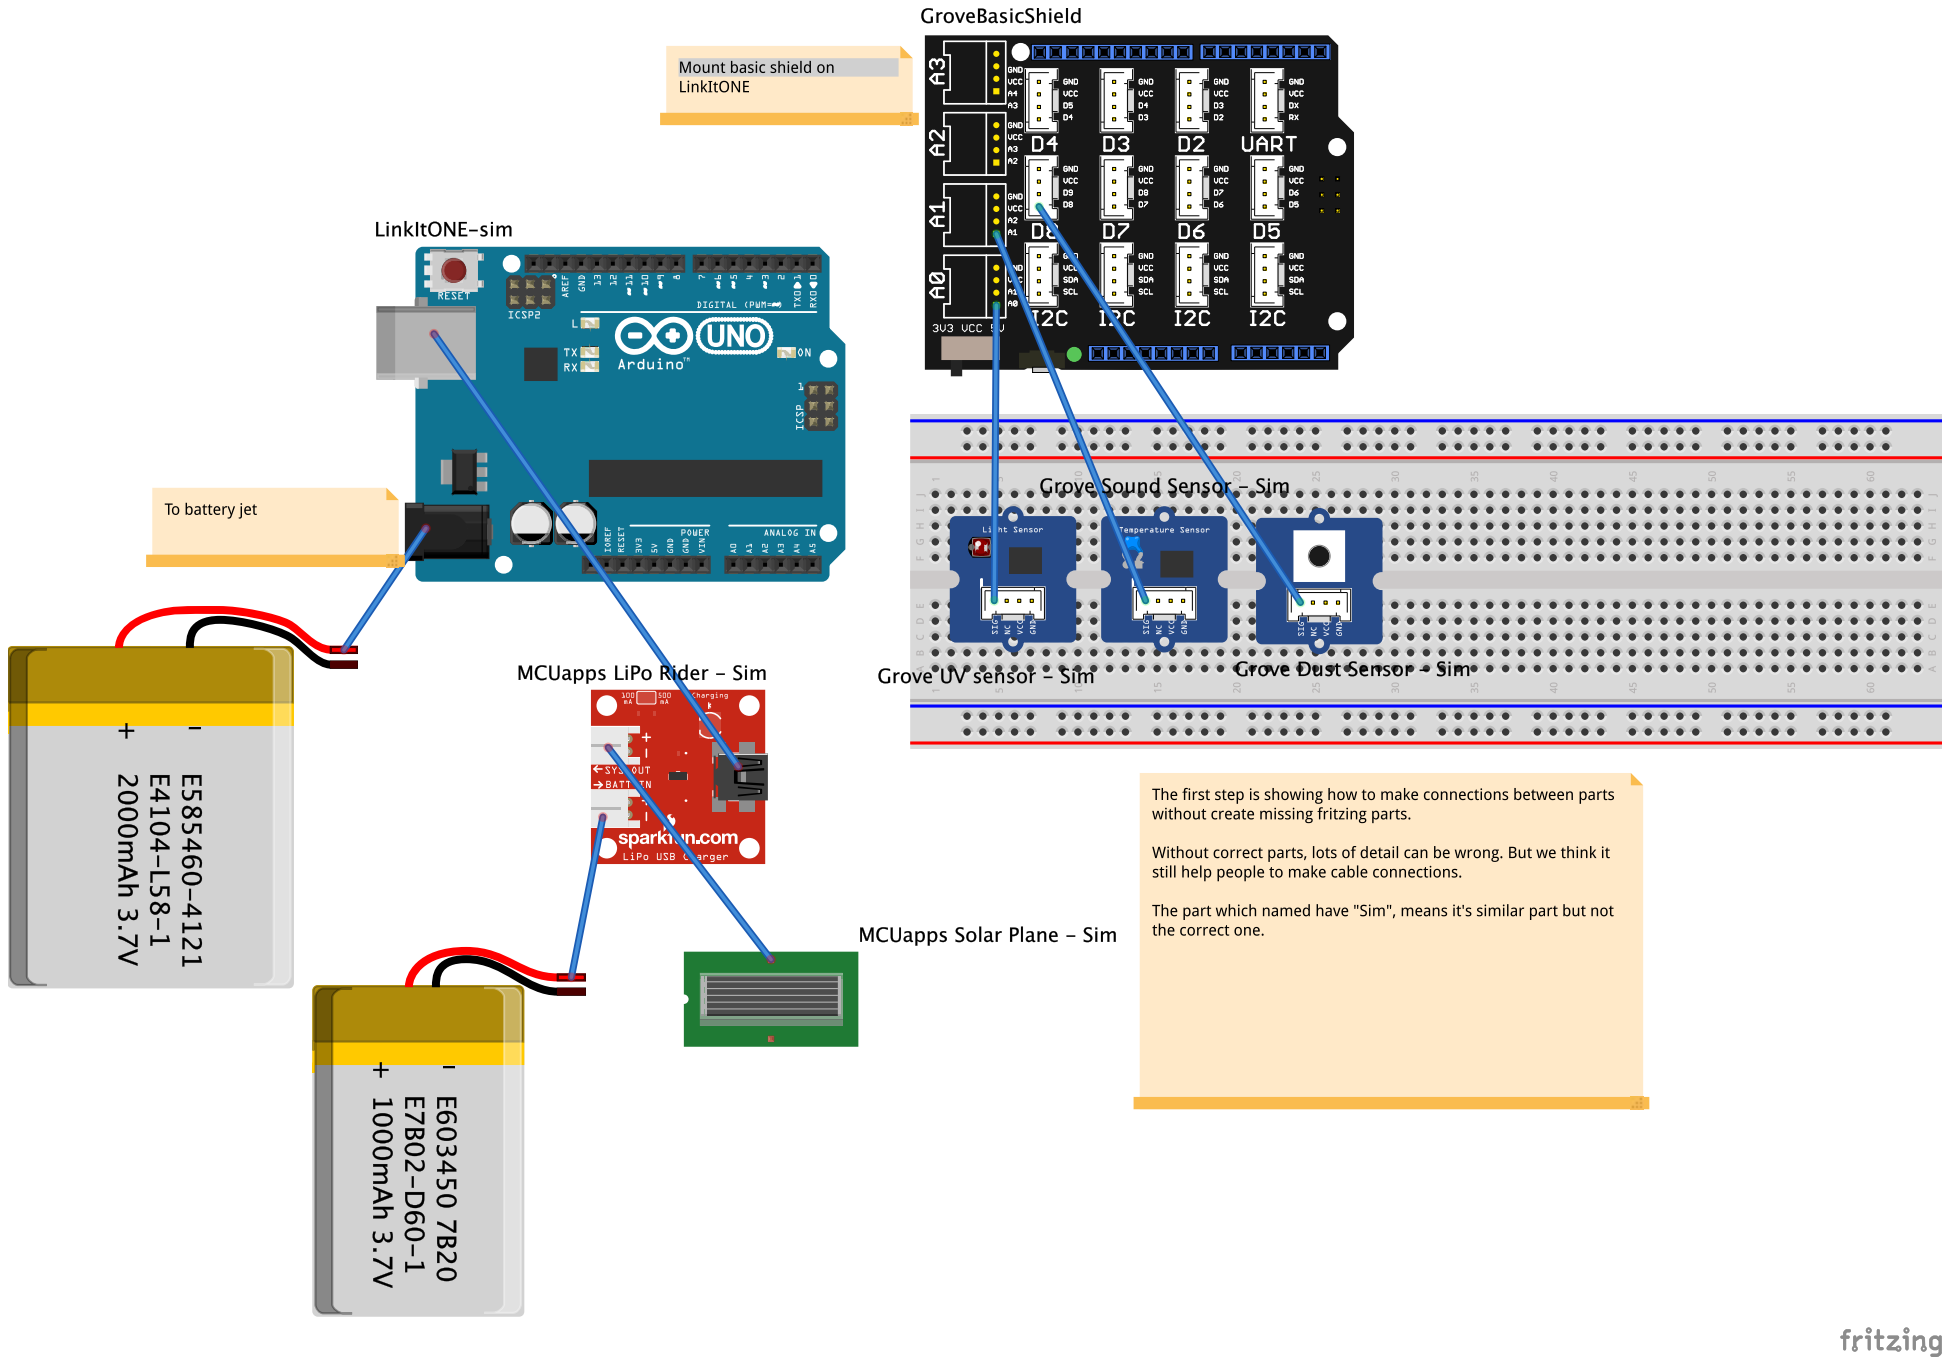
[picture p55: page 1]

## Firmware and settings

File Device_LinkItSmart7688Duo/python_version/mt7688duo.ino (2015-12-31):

/*
  Firmata is a generic protocol for communicating with microcontrollers
  from software on a host computer. It is intended to work with
  any host computer software package.

  To download a host software package, please clink on the following link
  to open the download page in your default browser.

  https://github.com/firmata/arduino#firmata-client-libraries

  Copyright (C) 2006-2008 Hans-Christoph Steiner.  All rights reserved.
  Copyright (C) 2010-2011 Paul Stoffregen.  All rights reserved.
  Copyright (C) 2009 Shigeru Kobayashi.  All rights reserved.
  Copyright (C) 2009-2015 Jeff Hoefs.  All rights reserved.

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
  See file LICENSE.txt for further informations on licensing terms.

  Last updated by Jeff Hoefs: April 11, 2015
*/

#include <Servo.h>
#include <Wire.h>
#include <Firmata.h>

#define I2C_WRITE                   B00000000
#define I2C_READ                    B00001000
#define I2C_READ_CONTINUOUSLY       B00010000
#define I2C_STOP_READING            B00011000
#define I2C_READ_WRITE_MODE_MASK    B00011000
#define I2C_10BIT_ADDRESS_MODE_MASK B00100000
#define MAX_QUERIES                 8
#define REGISTER_NOT_SPECIFIED      -1

// the minimum interval for sampling analog input
#define MINIMUM_SAMPLING_INTERVAL 10

#define VER_APP "0.0.3"
/*==============================================================================
 * GLOBAL VARIABLES
 *============================================================================*/

/* analog inputs */
int analogInputsToReport = 0; // bitwise array to store pin reporting

/* digital input ports */
byte reportPINs[TOTAL_PORTS];       // 1 = report this port, 0 = silence
byte previousPINs[TOTAL_PORTS];     // previous 8 bits sent

/* pins configuration */
byte pinConfig[TOTAL_PINS];         // configuration of every pin
byte portConfigInputs[TOTAL_PORTS]; // each bit: 1 = pin in INPUT, 0 = anything else
int pinState[TOTAL_PINS];           // any value that has been written

/* timer variables */
unsigned long currentMillis;        // store the current value from millis()
unsigned long previousMillis;       // for comparison with currentMillis
unsigned int samplingInterval = 19; // how often to run the main loop (in ms)

/* i2c data */
struct i2c_device_info {
  byte addr;
  int reg;
  byte bytes;
};

/* for i2c read continuous more */
i2c_device_info query[MAX_QUERIES];

byte i2cRxData[32];
boolean isI2CEnabled = false;
signed char queryIndex = -1;
// default delay time between i2c read request and Wire.requestFrom()
unsigned int i2cReadDelayTime = 0;

Servo servos[MAX_SERVOS];
byte servoPinMap[TOTAL_PINS];
byte detachedServos[MAX_SERVOS];
byte detachedServoCount = 0;
byte servoCount = 0;

boolean isResetting = false;

/* utility functions */
void wireWrite(byte data)
{
#if ARDUINO >= 100
  Wire.write((byte)data);
#else
  Wire.send(data);
#endif
}

byte wireRead(void)
{
#if ARDUINO >= 100
  return Wire.read();
#else
  return Wire.receive();
#endif
}

/*==============================================================================
 * FUNCTIONS
 *============================================================================*/

void attachServo(byte pin, int minPulse, int maxPulse)
{
  if (servoCount < MAX_SERVOS) {
    // reuse indexes of detached servos until all have been reallocated
    if (detachedServoCount > 0) {
      servoPinMap[pin] = detachedServos[detachedServoCount - 1];
      if (detachedServoCount > 0) detachedServoCount--;
    } else {
      servoPinMap[pin] = servoCount;
      servoCount++;
    }
    if (minPulse > 0 && maxPulse > 0) {
      servos[servoPinMap[pin]].attach(PIN_TO_DIGITAL(pin), minPulse, maxPulse);
    } else {
      servos[servoPinMap[pin]].attach(PIN_TO_DIGITAL(pin));
    }
  } else {
    Firmata.sendString("Max servos attached");
  }
}

void detachServo(byte pin)
{
  servos[servoPinMap[pin]].detach();
  // if we're detaching the last servo, decrement the count
  // otherwise store the index of the detached servo
  if (servoPinMap[pin] == servoCount && servoCount > 0) {
    servoCount--;
  } else if (servoCount > 0) {
    // keep track of detached servos because we want to reuse their indexes
    // before incrementing the count of attached servos
    detachedServoCount++;
    detachedServos[detachedServoCount - 1] = servoPinMap[pin];
  }

  servoPinMap[pin] = 255;
}

void readAndReportData(byte address, int theRegister, byte numBytes) {
  // allow I2C requests that don't require a register read
  // for example, some devices using an interrupt pin to signify new data available
  // do not always require the register read so upon interrupt you call Wire.requestFrom()
  if (theRegister != REGISTER_NOT_SPECIFIED) {
    Wire.beginTransmission(address);
    wireWrite((byte)theRegister);
    Wire.endTransmission();
    // do not set a value of 0
    if (i2cReadDelayTime > 0) {
      // delay is necessary for some devices such as WiiNunchuck
      delayMicroseconds(i2cReadDelayTime);
    }
  } else {
    theRegister = 0;  // fill the register with a dummy value
  }

  Wire.requestFrom(address, numBytes);  // all bytes are returned in requestFrom

  // check to be sure correct number of bytes were returned by slave
  if (numBytes < Wire.available()) {
    Firmata.sendString("I2C: Too many bytes received");
  } else if (numBytes > Wire.available()) {
    Firmata.sendString("I2C: Too few bytes received");
  }

  i2cRxData[0] = address;
  i2cRxData[1] = theRegister;

  for (int i = 0; i < numBytes && Wire.available(); i++) {
    i2cRxData[2 + i] = wireRead();
  }

  // send slave address, register and received bytes
  Firmata.sendSysex(SYSEX_I2C_REPLY, numBytes + 2, i2cRxData);
}

void outputPort(byte portNumber, byte portValue, byte forceSend)
{
  // pins not configured as INPUT are cleared to zeros
  portValue = portValue & portConfigInputs[portNumber];
  // only send if the value is different than previously sent
  if (forceSend || previousPINs[portNumber] != portValue) {
    Firmata.sendDigitalPort(portNumber, portValue);
    previousPINs[portNumber] = portValue;
  }
}

/* -----------------------------------------------------------------------------
 * check all the active digital inputs for change of state, then add any events
 * to the Serial output queue using Serial.print() */
void checkDigitalInputs(void)
{
  /* Using non-looping code allows constants to be given to readPort().
   * The compiler will apply substantial optimizations if the inputs
   * to readPort() are compile-time constants. */
  if (TOTAL_PORTS > 0 && reportPINs[0]) outputPort(0, readPort(0, portConfigInputs[0]), false);
  if (TOTAL_PORTS > 1 && reportPINs[1]) outputPort(1, readPort(1, portConfigInputs[1]), false);
  if (TOTAL_PORTS > 2 && reportPINs[2]) outputPort(2, readPort(2, portConfigInputs[2]), false);
  if (TOTAL_PORTS > 3 && reportPINs[3]) outputPort(3, readPort(3, portConfigInputs[3]), false);
  if (TOTAL_PORTS > 4 && reportPINs[4]) outputPort(4, readPort(4, portConfigInputs[4]), false);
  if (TOTAL_PORTS > 5 && reportPINs[5]) outputPort(5, readPort(5, portConfigInputs[5]), false);
  if (TOTAL_PORTS > 6 && reportPINs[6]) outputPort(6, readPort(6, portConfigInputs[6]), false);
  if (TOTAL_PORTS > 7 && reportPINs[7]) outputPort(7, readPort(7, portConfigInputs[7]), false);
  if (TOTAL_PORTS > 8 && reportPINs[8]) outputPort(8, readPort(8, portConfigInputs[8]), false);
  if (TOTAL_PORTS > 9 && reportPINs[9]) outputPort(9, readPort(9, portConfigInputs[9]), false);
  if (TOTAL_PORTS > 10 && reportPINs[10]) outputPort(10, readPort(10, portConfigInputs[10]), false);
  if (TOTAL_PORTS > 11 && reportPINs[11]) outputPort(11, readPort(11, portConfigInputs[11]), false);
  if (TOTAL_PORTS > 12 && reportPINs[12]) outputPort(12, readPort(12, portConfigInputs[12]), false);
  if (TOTAL_PORTS > 13 && reportPINs[13]) outputPort(13, readPort(13, portConfigInputs[13]), false);
  if (TOTAL_PORTS > 14 && reportPINs[14]) outputPort(14, readPort(14, portConfigInputs[14]), false);
  if (TOTAL_PORTS > 15 && reportPINs[15]) outputPort(15, readPort(15, portConfigInputs[15]), false);
}

// -----------------------------------------------------------------------------
/* sets the pin mode to the correct state and sets the relevant bits in the
 * two bit-arrays that track Digital I/O and PWM status
 */
void setPinModeCallback(byte pin, int mode)
{
  if (pinConfig[pin] == IGNORE)
    return;

  if (pinConfig[pin] == I2C && isI2CEnabled && mode != I2C) {
    // disable i2c so pins can be used for other functions
    // the following if statements should reconfigure the pins properly
    disableI2CPins();
  }
  if (IS_PIN_DIGITAL(pin) && mode != SERVO) {
    if (servoPinMap[pin] < MAX_SERVOS && servos[servoPinMap[pin]].attached()) {
      detachServo(pin);
    }
  }
  if (IS_PIN_ANALOG(pin)) {
    reportAnalogCallback(PIN_TO_ANALOG(pin), mode == ANALOG ? 1 : 0); // turn on/off reporting
  }
  if (IS_PIN_DIGITAL(pin)) {
    if (mode == INPUT) {
      portConfigInputs[pin / 8] |= (1 << (pin & 7));
    } else {
      portConfigInputs[pin / 8] &= ~(1 << (pin & 7));
    }
  }
  pinState[pin] = 0;
  switch (mode) {
    case ANALOG:
      if (IS_PIN_ANALOG(pin)) {
        if (IS_PIN_DIGITAL(pin)) {
          pinMode(PIN_TO_DIGITAL(pin), INPUT);    // disable output driver
          digitalWrite(PIN_TO_DIGITAL(pin), LOW); // disable internal pull-ups
        }
        pinConfig[pin] = ANALOG;
      }
      break;
    case INPUT:
      if (IS_PIN_DIGITAL(pin)) {
        pinMode(PIN_TO_DIGITAL(pin), INPUT);    // disable output driver
        digitalWrite(PIN_TO_DIGITAL(pin), LOW); // disable internal pull-ups
        pinConfig[pin] = INPUT;
      }
      break;
    case OUTPUT:
      if (IS_PIN_DIGITAL(pin)) {
        digitalWrite(PIN_TO_DIGITAL(pin), LOW); // disable PWM
        pinMode(PIN_TO_DIGITAL(pin), OUTPUT);
        pinConfig[pin] = OUTPUT;
      }
      break;
    case PWM:
      if (IS_PIN_PWM(pin)) {
        pinMode(PIN_TO_PWM(pin), OUTPUT);
        analogWrite(PIN_TO_PWM(pin), 0);
        pinConfig[pin] = PWM;
      }
      break;
    case SERVO:
      if (IS_PIN_DIGITAL(pin)) {
        pinConfig[pin] = SERVO;
        if (servoPinMap[pin] == 255 || !servos[servoPinMap[pin]].attached()) {
          // pass -1 for min and max pulse values to use default values set
          // by Servo library
          attachServo(pin, -1, -1);
        }
      }
      break;
    case I2C:
      if (IS_PIN_I2C(pin)) {
        // mark the pin as i2c
        // the user must call I2C_CONFIG to enable I2C for a device
        pinConfig[pin] = I2C;
      }
      break;
    default:
      Firmata.sendString("Unknown pin mode"); // TODO: put error msgs in EEPROM
  }
  // TODO: save status to EEPROM here, if changed
}

void analogWriteCallback(byte pin, int value)
{
  if (pin < TOTAL_PINS) {
    switch (pinConfig[pin]) {
      case SERVO:
        if (IS_PIN_DIGITAL(pin))
          servos[servoPinMap[pin]].write(value);
        pinState[pin] = value;
        break;
      case PWM:
        if (IS_PIN_PWM(pin))
          analogWrite(PIN_TO_PWM(pin), value);
        pinState[pin] = value;
        break;
    }
  }
}

void digitalWriteCallback(byte port, int value)
{
  byte pin, lastPin, mask = 1, pinWriteMask = 0;

  if (port < TOTAL_PORTS) {
    // create a mask of the pins on this port that are writable.
    lastPin = port * 8 + 8;
    if (lastPin > TOTAL_PINS) lastPin = TOTAL_PINS;
    for (pin = port * 8; pin < lastPin; pin++) {
      // do not disturb non-digital pins (eg, Rx & Tx)
      if (IS_PIN_DIGITAL(pin)) {
        // only write to OUTPUT and INPUT (enables pullup)
        // do not touch pins in PWM, ANALOG, SERVO or other modes
        if (pinConfig[pin] == OUTPUT || pinConfig[pin] == INPUT) {
          pinWriteMask |= mask;
          pinState[pin] = ((byte)value & mask) ? 1 : 0;
        }
      }
      mask = mask << 1;
    }
    writePort(port, (byte)value, pinWriteMask);
  }
}


// -----------------------------------------------------------------------------
/* sets bits in a bit array (int) to toggle the reporting of the analogIns
 */
//void FirmataClass::setAnalogPinReporting(byte pin, byte state) {
//}
void reportAnalogCallback(byte analogPin, int value)
{
  if (analogPin < TOTAL_ANALOG_PINS) {
    if (value == 0) {
      analogInputsToReport = analogInputsToReport & ~ (1 << analogPin);
    } else {
      analogInputsToReport = analogInputsToReport | (1 << analogPin);
      // prevent during system reset or all analog pin values will be reported
      // which may report noise for unconnected analog pins
      if (!isResetting) {
        // Send pin value immediately. This is helpful when connected via
        // ethernet, wi-fi or bluetooth so pin states can be known upon
        // reconnecting.
        Firmata.sendAnalog(analogPin, analogRead(analogPin));
      }
    }
  }
  // TODO: save status to EEPROM here, if changed
}

void reportDigitalCallback(byte port, int value)
{
  if (port < TOTAL_PORTS) {
    reportPINs[port] = (byte)value;
    // Send port value immediately. This is helpful when connected via
    // ethernet, wi-fi or bluetooth so pin states can be known upon
    // reconnecting.
    if (value) outputPort(port, readPort(port, portConfigInputs[port]), true);
  }
  // do not disable analog reporting on these 8 pins, to allow some
  // pins used for digital, others analog.  Instead, allow both types
  // of reporting to be enabled, but check if the pin is configured
  // as analog when sampling the analog inputs.  Likewise, while
  // scanning digital pins, portConfigInputs will mask off values from any
  // pins configured as analog
}

/*==============================================================================
 * SYSEX-BASED commands
 *============================================================================*/

void sysexCallback(byte command, byte argc, byte *argv)
{
  byte mode;
  byte slaveAddress;
  byte data;
  int slaveRegister;
  unsigned int delayTime;

  switch (command) {
    case I2C_REQUEST:
      mode = argv[1] & I2C_READ_WRITE_MODE_MASK;
      if (argv[1] & I2C_10BIT_ADDRESS_MODE_MASK) {
        Firmata.sendString("10-bit addressing not supported");
        return;
      }
      else {
        slaveAddress = argv[0];
      }

      switch (mode) {
        case I2C_WRITE:
          Wire.beginTransmission(slaveAddress);
          for (byte i = 2; i < argc; i += 2) {
            data = argv[i] + (argv[i + 1] << 7);
            wireWrite(data);
          }
          Wire.endTransmission();
          delayMicroseconds(70);
          break;
        case I2C_READ:
          if (argc == 6) {
            // a slave register is specified
            slaveRegister = argv[2] + (argv[3] << 7);
            data = argv[4] + (argv[5] << 7);  // bytes to read
          }
          else {
            // a slave register is NOT specified
            slaveRegister = REGISTER_NOT_SPECIFIED;
            data = argv[2] + (argv[3] << 7);  // bytes to read
          }
          readAndReportData(slaveAddress, (int)slaveRegister, data);
          break;
        case I2C_READ_CONTINUOUSLY:
          if ((queryIndex + 1) >= MAX_QUERIES) {
            // too many queries, just ignore
            Firmata.sendString("too many queries");
            break;
          }
          if (argc == 6) {
            // a slave register is specified
            slaveRegister = argv[2] + (argv[3] << 7);
            data = argv[4] + (argv[5] << 7);  // bytes to read
          }
          else {
            // a slave register is NOT specified
            slaveRegister = (int)REGISTER_NOT_SPECIFIED;
            data = argv[2] + (argv[3] << 7);  // bytes to read
          }
          queryIndex++;
          query[queryIndex].addr = slaveAddress;
          query[queryIndex].reg = slaveRegister;
          query[queryIndex].bytes = data;
          break;
        case I2C_STOP_READING:
          byte queryIndexToSkip;
          // if read continuous mode is enabled for only 1 i2c device, disable
          // read continuous reporting for that device
          if (queryIndex <= 0) {
            queryIndex = -1;
          } else {
            // if read continuous mode is enabled for multiple devices,
            // determine which device to stop reading and remove it's data from
            // the array, shifiting other array data to fill the space
            for (byte i = 0; i < queryIndex + 1; i++) {
              if (query[i].addr == slaveAddress) {
                queryIndexToSkip = i;
                break;
              }
            }

            for (byte i = queryIndexToSkip; i < queryIndex + 1; i++) {
              if (i < MAX_QUERIES) {
                query[i].addr = query[i + 1].addr;
                query[i].reg = query[i + 1].reg;
                query[i].bytes = query[i + 1].bytes;
              }
            }
            queryIndex--;
          }
          break;
        default:
          break;
      }
      break;
    case I2C_CONFIG:
      delayTime = (argv[0] + (argv[1] << 7));

      if (delayTime > 0) {
        i2cReadDelayTime = delayTime;
      }

      if (!isI2CEnabled) {
        enableI2CPins();
      }

      break;
    case SERVO_CONFIG:
      if (argc > 4) {
        // these vars are here for clarity, they'll optimized away by the compiler
        byte pin = argv[0];
        int minPulse = argv[1] + (argv[2] << 7);
        int maxPulse = argv[3] + (argv[4] << 7);

        if (IS_PIN_DIGITAL(pin)) {
          if (servoPinMap[pin] < MAX_SERVOS && servos[servoPinMap[pin]].attached()) {
            detachServo(pin);
          }
          attachServo(pin, minPulse, maxPulse);
          setPinModeCallback(pin, SERVO);
        }
      }
      break;
    case SAMPLING_INTERVAL:
      if (argc > 1) {
        samplingInterval = argv[0] + (argv[1] << 7);
        if (samplingInterval < MINIMUM_SAMPLING_INTERVAL) {
          samplingInterval = MINIMUM_SAMPLING_INTERVAL;
        }
      } else {
        //Firmata.sendString("Not enough data");
      }
      break;
    case EXTENDED_ANALOG:
      if (argc > 1) {
        int val = argv[1];
        if (argc > 2) val |= (argv[2] << 7);
        if (argc > 3) val |= (argv[3] << 14);
        analogWriteCallback(argv[0], val);
      }
      break;
    case CAPABILITY_QUERY:
      Firmata.write(START_SYSEX);
      Firmata.write(CAPABILITY_RESPONSE);
      for (byte pin = 0; pin < TOTAL_PINS; pin++) {
        if (IS_PIN_DIGITAL(pin)) {
          Firmata.write((byte)INPUT);
          Firmata.write(1);
          Firmata.write((byte)OUTPUT);
          Firmata.write(1);
        }
        if (IS_PIN_ANALOG(pin)) {
          Firmata.write(ANALOG);
          Firmata.write(10); // 10 = 10-bit resolution
        }
        if (IS_PIN_PWM(pin)) {
          Firmata.write(PWM);
          Firmata.write(8); // 8 = 8-bit resolution
        }
        if (IS_PIN_DIGITAL(pin)) {
          Firmata.write(SERVO);
          Firmata.write(14);
        }
        if (IS_PIN_I2C(pin)) {
          Firmata.write(I2C);
          Firmata.write(1);  // TODO: could assign a number to map to SCL or SDA
        }
        Firmata.write(127);
      }
      Firmata.write(END_SYSEX);
      break;
    case PIN_STATE_QUERY:
      if (argc > 0) {
        byte pin = argv[0];
        Firmata.write(START_SYSEX);
        Firmata.write(PIN_STATE_RESPONSE);
        Firmata.write(pin);
        if (pin < TOTAL_PINS) {
          Firmata.write((byte)pinConfig[pin]);
          Firmata.write((byte)pinState[pin] & 0x7F);
          if (pinState[pin] & 0xFF80) Firmata.write((byte)(pinState[pin] >> 7) & 0x7F);
          if (pinState[pin] & 0xC000) Firmata.write((byte)(pinState[pin] >> 14) & 0x7F);
        }
        Firmata.write(END_SYSEX);
      }
      break;
    case ANALOG_MAPPING_QUERY:
      Firmata.write(START_SYSEX);
      Firmata.write(ANALOG_MAPPING_RESPONSE);
      for (byte pin = 0; pin < TOTAL_PINS; pin++) {
        Firmata.write(IS_PIN_ANALOG(pin) ? PIN_TO_ANALOG(pin) : 127);
      }
      Firmata.write(END_SYSEX);
      break;
  }
}

void enableI2CPins()
{
  byte i;
  // is there a faster way to do this? would probaby require importing
  // Arduino.h to get SCL and SDA pins
  for (i = 0; i < TOTAL_PINS; i++) {
    if (IS_PIN_I2C(i)) {
      // mark pins as i2c so they are ignore in non i2c data requests
      setPinModeCallback(i, I2C);
    }
  }

  isI2CEnabled = true;

  Wire.begin();
}
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
void loop()
{
  byte pin, analogPin;
  

  /* DIGITALREAD - as fast as possible, check for changes and output them to the
   * FTDI buffer using Serial.print()  */
  checkDigitalInputs();

  /* STREAMREAD - processing incoming messagse as soon as possible, while still
   * checking digital inputs.  */
  while (Firmata.available())
    Firmata.processInput();

  // TODO - ensure that Stream buffer doesn't go over 60 bytes

  currentMillis = millis();
  if (currentMillis - previousMillis > samplingInterval) {
    previousMillis += samplingInterval;
    /* ANALOGREAD - do all analogReads() at the configured sampling interval */
    for (pin = 0; pin < TOTAL_PINS; pin++) {
      if (IS_PIN_ANALOG(pin) && pinConfig[pin] == ANALOG) {
        analogPin = PIN_TO_ANALOG(pin);
        if (analogInputsToReport & (1 << analogPin)) {
          if(analogPin==11){
            Firmata.sendAnalog(analogPin, loop_cnt);
            loop_cnt++;
            if(loop_cnt>=1024)
              loop_cnt=0;
            Serial.print(".");
          }else{
            Firmata.sendAnalog(analogPin, analogRead(analogPin));
          }
        }
      }
    }
    // report i2c data for all device with read continuous mode enabled
    if (queryIndex > -1) {
      for (byte i = 0; i < queryIndex + 1; i++) {
        readAndReportData(query[i].addr, query[i].reg, query[i].bytes);
      }
    }
  }
  Serial.print("Looping:");
  Serial.println(loop_cnt);
   
}

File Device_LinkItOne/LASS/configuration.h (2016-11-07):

//LASS CONFIGURATION FILE  
#include "Arduino.h"
//Step 1: How you Connect WIFI....Basic things.
//WIFI
//System default wifi setting: SSID=LASS, PASS=LASS123456, WIFI_AUTH=LWIFI_WPA
#define WIFI_SSID "LASS"         // REPLACE: your network SSID (name)
#define WIFI_PASS "LASS123456"   // REPLACE: your network password (use for WPA, or use as key for WEP)
#define WIFI_AUTH LWIFI_WPA   //Default:LWIFI_WPA // choose from LWIFI_OPEN, LWIFI_WPA, or LWIFI_WEP.
//-----------------------------------------------------------

//Step 2:Do you use Blyak.If yes,fill info below.
//Blynk-IoT
#define BLYNK_ENABLE 0 // deafult(0) 0: If you don't need to support BLYNK, 1: support BLYNK 
char blynk_auth[] = "yourBlynkID"; // REPLACE: your Blynk auto id
//-----------------------------------------------------------

//Step 3:MQTT info
//MQTT-IoT
#define MQTT_PROXY_IP "gpssensor.ddns.net"  // Current LASD server , dont change!
#define DEVICE_TYPE  "LinkItONE"            // since there is only one device LASS supported now,dont change!
#define DEVICE_ID "FT1_999"                 // REPLACE: The device ID you like, please start from LASD. Without this prefix, maybe it will be filter out.
#define MQTT_TOPIC_PREFIX "LASS/Test"       // CAN REPLACE if you like //Dont Replace IF YOU ARE FIELD-TRY USER
#define PARTNER_ID "LASS-Partner1"          // CAN REPLACE if you like


//Step 4:GPS
//Do you want to use gps? 0:YES 1:FAKE GPS
#define FAKE_GPS 0 // FAKE_GPS : 0: default format with gps, 1: default format but gps is fix data, need to update GPS_FIX_INFOR 
//NOTICE:If you choose 1 modify "FAKE" GPS location. Fill info below
const char gps_lat[]= "23.000000";  // device's gps latitude
const char gps_lon[]= "120.000000";   // device's gps longitude
const char gps_alt[]= "30.0";          // device's gps altitude
#define GPS_SIGNAL_NOCHECK 1   // 0: log or send only when GPS have signal, 1: always log and send even when GPS have no signal 

//NOTICE: for Field TRY-PM2.5 DONT CHANGE AFTER THIS LINE!   --2015/11/09
//-----------------------------------------------------------
//Step 5:About LASS 
#define APP_ID (APPTYPE_SYSTEM_BASE+1)               // REPLACE: this is your unique application 0-255: system reserved, 256-32767: user public use, 32768-65536: private purpose
#define APPTYPE_SYSTEM_BASE 0
#define APPTYPE_PUBLIC_BASE 256
#define APPTYPE_PRIVATE_BASE 32768
#define SERIAL_BAUDRATE 115200

//NOTICE: You are ready to ROCK, NO MORE TO SETUP!!!!
//-----------------------------------------------------------


//For ADVANCED user ONLY 
#define ALARM_ENABLE 0 // default(0) 0: disable alarm, 1: enable alarm
#if ALARM_ENABLE==1
  #define BUZZER_ALARM_PIN 3
#endif


//----- USER SENSOR CONFIG -----

#define SENSOR_CNT 25          // REPLACE: the sensors count that publish to server.
#define SENSOR_STRING_MAX 300  

#define SENSOR_ID_RECORDID 0
#define SENSOR_ID_BATTERYLEVEL 1
#define SENSOR_ID_BATTERYCHARGING 2 //      battery is charging: (0) not charging, (1) charging
#define SENSOR_ID_GROUNDSPEED 3
#define SENSOR_ID_DEBUGWIFI 4

//----- DEAFULT PIN DEFINE -----
enum pinConfig{
  ARDUINO_LED_PIN = 13,
  STORAGE_CHIP_SELECT_PIN = 10
};


//LASS's OPEN PM2.5 Field-TRY
#if APP_ID==(APPTYPE_SYSTEM_BASE+1)
  #define USE_PM25_G3
  //#define USE_PM25_A4
  #define USE_DHT22  // not recommend for DHT series sensors
  //#define USE_SHT31
  //#define USE_LCD  // use 1602 i2c LCD...
  #define SENSOR_ID_DUST 10
  #define SENSOR_ID_TEMPERATURE 11
  #define SENSOR_ID_HUMIDITY 12  
  #define SENSOR_ID_DUST10 13
  #define SENSOR_ID_DUST_BLYNK 6
  #define SENSOR_ID_TEMPERATURE_BLYNK 7
  #define SENSOR_ID_HUMIDITY_BLYNK 8
  #define SENSOR_ID_DUST10_BLYNK 9


//LASS's start up project by wuloong
#elif APP_ID==(APPTYPE_PUBLIC_BASE+1)
  #define SENSOR_ID_DUST 10
  #define SENSOR_ID_UV 11
  #define SENSOR_ID_SOUND 12
  // in order to prevent blynk not support that many virtual gpio in the macro. we setup virtual GPIO in lower pin
  #define SENSOR_ID_DUST_BLYNK 4
  #define SENSOR_ID_UV_BLYNK 5
  #define SENSOR_ID_SOUND_BLYNK 6
  enum pinSensorConfig{
    DUST_SENSOR_PIN = 8,  
    SOUND_SENSOR_PIN = A1,
    UV_SENSOR_PIN = A0,
    TEMP_HUMID_SENSOR_PIN = 2,
  };

//LASS's PM2.5 project by RODODO-MINGWEI
#elif APP_ID==(APPTYPE_PUBLIC_BASE+2)
  #define SENSOR_ID_DUST 10  
  #define SENSOR_ID_DUST10 13
  #define SENSOR_ID_DUST_BLYNK 4 
  #define SENSOR_ID_DUST10_BLYNK 7

//LASS project by Academia Sinica-LJ
#elif APP_ID==(APPTYPE_PUBLIC_BASE+3)
  #define SENSOR_ID_BAROMETER 10
  #define SENSOR_ID_TEMPERATURE 11
  #define SENSOR_ID_HUMIDITY 12  
  #define SENSOR_ID_LIGHT 13
  // in order to prevent blynk not support that many virtual gpio in the macro. we setup virtual GPIO in lower pin
  #define SENSOR_ID_BAROMETER_BLYNK 4
  #define SENSOR_ID_TEMPERATURE_BLYNK 5
  #define SENSOR_ID_HUMIDITY_BLYNK 6
  #define SENSOR_ID_LIGHT_BLYNK 7
//#endif
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

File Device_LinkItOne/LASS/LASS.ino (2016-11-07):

/*
  Location Aware Sensor System(LASS) by Linkit ONE 

        Vision: We hope location aware sensor data can be easy to provide, share, and become useful to everyone.
        
        Sensor Used as example:
          Sound Sensor: http://www.seeedstudio.com/wiki/Grove_-_Sound_Sensor
          
  Board jumper setting:
            SPI/SD = SPI
            Mass Storage Bootup/Normal Bootup = Normal Bootup
            USB Power Source/Li-Battery Power Source = USB Power Source 
        The circuit:
    Default Output PIN: 
                  ARDUINO_LED_PIN = 13,
                  STORAGE_CHIP_SELECT_PIN = 10 (Reserved)
                Sensor Input PIN:
                  SOUND_SENSOR_PIN = A1
                  DUST_SENSOR_PIN = 8,  cal
                  UV_SENSOR_PIN = A0
                  TEMP-HUMID_SENSOR_PIN = 2
                  BAROMETER_SENSOR_PIN -> I2C
                  LIGHT_SENSOR -> I2C
                Action Output PIN:
                  BUZZER_ALARM_PIN = 3
        LinkItONE:
          Used wifi, gps, flash. Remind wifi/gps antenna needed.
        
        Sensor position definition:
        0-9(System sensor):   reserved for system sensor, should not be modified for individual application purpose.
        10-19(User sensor): user customization purpose, user can freely customize this area
        
        Default system sensor order:
          0: record_id, 1: battery level, 2: battery charging, 3: ground speed ( Km/hour ) 
        Default user sensor order:
          10: dust sensor, 11: UV  sensor, 12: sound sensor 
        Default user sensor order in APP-3 (MAPS):
          10: barometer sensor (high accuracy), 11&12: temperature & humidity sensor pro, 13: digital light sensor

  Default Sensor Type: ( -: void;  0-9: reserved for system sensor;  A-Z: LASS default sensors;  a-z: reserved for other sensors)
    -: unused
    0: record ID
    1: battery level
    2: battery charging
    3: ground speed
    4: wifi debug: reconnect count
    d: dust sensor
    u: UV sensor
    s: sound sensor
    b: barometer sensor (hPa)
    t: temperature sensor (degree C)
    h: humidity sensor (%)
    l: light sensor (LUX)
        
        Original:
          The idea come from here: http://iot-hackseries.s3-website-us-west-2.amazonaws.com/linkitone-setup.html

        Optional sample sensor:
          AP1-SENSOR_ID_DUST: Dust sensor: http://www.seeedstudio.com/depot/Grove-Dust-Sensor-p-1050.html
          AP1-SENSOR_ID_UV: UV sensor: http://www.seeedstudio.com/depot/Grove-UV-Sensor-p-1540.html
          AP1-SENSOR_ID_SOUND: Sound sensor: http://www.seeedstudio.com/depot/Grove-Sound-Sensor-p-752.html
          AP2-SENSOR_ID_DUST: Dust sensor http://tw.taobao.com/item/43750623059.htm
          AP3-SENSOR_ID_BAROMETER: Barometer sensor (high accuracy): http://www.seeedstudio.com/wiki/Grove_-_Barometer_(High-Accuracy)
          AP3-SENSOR_ID_TEMPERATURE: Temperture and Humidity sensor pro: http://www.seeedstudio.com/wiki/Grove_-_Temperature_and_Humidity_Sensor_Pro
          AP3-SENSOR_ID_HUMIDITY: Temperture and Humidity sensor pro: http://www.seeedstudio.com/wiki/Grove_-_Temperature_and_Humidity_Sensor_Pro
          AP3-SENSOR_ID_LIGHT: Digital Light sensor: http://www.seeedstudio.com/wiki/Grove_-_Digital_Light_Sensor
          AP4-SENSOR_ID_DUST: Dust sensor http://tw.taobao.com/item/43750623059.htm
          AP4-SENSOR_ID_TEMPERATURE: Temperture and Humidity sensor pro: http://www.seeedstudio.com/wiki/Grove_-_Temperature_and_Humidity_Sensor_Pro
          AP4-SENSOR_ID_HUMIDITY: Temperture and Humidity sensor pro: http://www.seeedstudio.com/wiki/Grove_-_Temperature_and_Humidity_Sensor_Pro
        Optional alarm:
          Buzzer : http://www.seeedstudio.com/depot/Grove-Buzzer-p-768.html
        Created 26/06/2015
  By Wuulong

  https://github.com/wuulong/LinkitOneGroup

*/
//ALL Configuration is at configuration.h
#include "configuration.h"

#define VER_FORMAT "3"  // version number has been increased to 2 since v0.7.0
#define VER_APP "0.8.3"
#define CLEAR_SETTING 0  //modify this to 1 if you can't change Setting in Flash

// Blynk
#if BLYNK_ENABLE == 1
  #define ARDUINO 150 // to avoid Blynk library use yield() in function run(), without this. system will crash!
  #include <BlynkSimpleLinkItONE.h>
  #define BLYNK_POOLING_TIME 1000 // the blynk pooling loop can't delay too long, quick check is 5000 ms, set is < 5000
#else
  #include <LWiFi.h>
  #include <LWiFiClient.h>
#endif

//Time NTP
#include <LWiFiUdp.h>
LWiFiUDP Udp;
unsigned int localPort = 2390;      // local port to listen for UDP packets
const int NTP_PACKET_SIZE = 48; // NTP time stamp is in the first 48 bytes of the message
byte packetBuffer[NTP_PACKET_SIZE]; //buffer to hold incoming and outgoing packets
uint32_t epochSystem = 0; // timestamp of system boot up
IPAddress timeServerIP(129, 6, 15, 28);


//web-server
#include <LWiFiServer.h>
LWiFiServer server(80);

#include <PubSubClient.h>
#include <Wire.h>
#include <MtkAWSImplementations.h>
#include <LGPS.h>
#include <LTask.h> 
#include "vmthread.h" 
#include "stddef.h"
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

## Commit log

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2015-07-18 V0.5.1 support fake data generation, quick devices mgr
2015-07-18 V0.5.2 cvs export supported
    [ride2.csv]
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2015-08-12 V0.6.2 front end minor features and bug fix
    [LASS.ino]
2015-09-16 The slides talk in the course of NTHU sensor network design
2015-09-25 V0.6.3 bug fix: (1)data loss cause affected by MQTT publish to partner.(2)ALARM_ENABLE=0 compile error
    [LASS.ino]
2015-09-27 V0.6.4
    1. DataPresentation
    more exception handler
    add server log importer
    2. Device
    add FMT_OPT format to support GPS disable
    default support 20 sensors, and 10 reserved for user
    fix MQTT payload can't > 256 bytes, Library/PubSubClient.zip need to be updated.
    add default record_id to system sensor in order to check data loss
    add startup LED blink
    [LASS.ino]
2015-09-27 Blink 3.1 sample code verified with LinkItONE at Blynk/Blynk.ino
2015-09-28 bug fixies after v0.6.6, for Hsinchu Maker Faire
    [LASS.ino]
2015-09-29 - extend the original LASS.ino (v0.6.6) for a new application, called MAPS - MAPS supports barometer, temperature&humidity, and light sensors - the corresponding libraries are also included in this u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
2015-09-29 - change the PARTNER_ID to Lass-Partner1 - change the sensor IDs to starts from 10
2015-10-05 - change the data format of datastr from its original form (dd/mm/yy) into UTC format - force each number in utcstr to have two digits - changes the original "values=xxxxx" to multiple "value-X=xxxxx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
2015-10-06 - fix some typos in the comments - remove some unused codes/printout - change the version number to 0.7.1
    [LASS.ino]
2015-10-08 - remove gps-type="Point" in the MQTT message because such detailed info should be done on the backend, but not on the sensor node
2015-10-12 - minor corrections (some typos)
    [LASS.ino]
2015-10-12 - add a new utility program that subsribe to LASS data stream and insert into databases
2015-10-12 - replace the index of sensorType[] with SENSOR_ID_XXX
    [LASS.ino]
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2015-10-15 - fix the data "gps-xxx=XXXX" to "gps_xxx=XXX" in order to obey the new format 3.0
    [LASS.ino]
2015-10-15 - fix gps-_lon to gps_lon
    [LASS.ino]
2015-10-16 - update the codes for the G3 sensor (provided by MingWei)
2015-10-16 1. JavaScript Client can show marker from JSON that generate from lass.py. location correct 2. lass.py support JSON export, export limited records per device 3. lass.py new CLI command to support gps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
2015-10-21 second layer cover add 4 latch (but not strong enough)
    [caseA_test.stl]
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2015-11-01 correct default blynk token value
    [LASS.ino]
2015-11-02 - add the current system datetime in the output
2015-11-09 update: configuration
    [configuration.h]
2015-11-09 - change default FM_OPT to 0
    [configuration.h]
2015-11-10 - fix a typo in the codes (BHUMIDITY -> HUMIDITY)
    [LASS.ino]
2015-11-10 - fix a typo (BHUMIDITY -> HUMIDITY)
    [LASS.ino]
2015-11-10 some small document fix
    [configuration.h]
2015-11-11 case box verified
    [FRAMELIFT_FINAL.skp, FRAME_V2_MAX_FINAL.skp]
2015-11-12 V0.7.8
    Important Update: Wifi Force Reboot Method Introduced
    重大更新： WIFI當機預防機制
    [configuration.h]
2015-11-13 V0.7.9
    Expose PM10 Value In same function…
    揭露 PM10的讀數
    [configuration.h]
2015-11-13 - fix: when LWiFi.connect() is failed, the return value may be 0 or -1
    [LASS.ino]
2015-11-15 - fix the issue that the system may halt when WiFi connection is poor - several error handling mechanism are added in this update
    [configuration.h]
2015-11-19 add case that user make, please refer README
2015-11-20 0.7.1 - modify default sensing period from 10 seconds to 60 seconds
    [configuration.h]
2015-11-21 - add an example of query the last 100 entries by one particular device
2015-11-21 V0.7.12 improve system crash due to wifi reconnect, tested with re-connect 12 times PASS
    [configuration.h]
2015-11-21 V0.7.13 Support fly mode by setup ADJ_MODE = ADJ_MODE_FLY Current fly mode means sensing every 5 seconds, search wifi every 5 mins
    [configuration.h]
2015-11-21 fix BLYNK_ENABLE compile error, be noticed that virtual channel ID for APP_ID=1 be changed
    [configuration.h]
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2015-11-22 function to support user setting save/load from flash,verified,not enabled
    [configuration.h]
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2015-11-26 - add temperature and humidity information on the webpage
2015-11-26 - support data visualization merely based on device_id
2015-11-27 - show the last data sent by a specified device_id in json format
2015-11-27 - show the last 1000 data sent by a specified device_id in json format
2015-11-28 3DP CASE
    [FRAMELIFT_FINAL.skp, FRAMELIFT_FINAL.stl, FRAMELIFT_FINAL~.skp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]
2015-11-30 Web setup
    [configuration.h]
2015-11-30 0.7.17 beta
    [configuration.h]
2015-12-01 3DP flow fix
    [FRAMELIFT_FINAL~.skp, FRAME_V21_MAX_FINAL.skp, FRAME_V21_MAX_FINAL.stl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]
2015-12-02 0.7.17 hot fix 2
    Hardware issue
    [LASS_WEB.ino]
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2015-12-04 FIX DORAEMON ISSUES
    [TOP1_CLEAN.skp, TOP1_CLEAN_NEW.skp, TOP1_CLEAN_NEW.stl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]
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2015-12-07 kisslicr not manifold issue fixed
    [TOP1_CLEAN_NEW.stl, TOP1_CLEAN_NEW_fixed.stl]
2015-12-14 LASS 3DP case for Field Try 1, designed by Scott Chen
    [LASS G3.igs, LASS G3.stl, LASS cover Linkit One.igs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]
2015-12-28 V0.0.2 mt7688duo wip, draft format ready, sensor data sensing, mqtt send and receive
2015-12-31 V0.0.3: hack analog port as user define analog port for special sensor using ArduinoDue class in pyfirmata to fix sample code run as Arduino type
    [mt7688duo.ino]
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2016-01-17 WIP: Add GroveMultichannelGasSensor verificaition code. expected to work with all ArduinoLike platform
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2016-01-27 V 0.7.17 Field-Try Support A4,SHT31
    V 0.7.17 Field-Try Support A4,SHT31
    [configuration.h]
2016-01-27 V 0.7.18 Support A4 ,SHT31 on Field_Try
    V 0.7.18 Support A4 ,SHT31 on Field_Try
    [configuration.h]
2016-01-29 V0.8
    >> FAKE_GPS Support
    >> UDP Time with FAKE_GPS
    >> Companion Channel Cleaned
    [configuration.h]
2016-01-29 Fix: read APRS weather station data
    [WeatherBox.ino]
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2016-02-01 V0.8.0a
    Fix Bug From Ameba Time Library
    [configuration.h]
2016-02-01 V0.8.0b
    Time issue from ameba library
    [configuration.h]
2016-02-01 LASS CompactPM25 CrossFit V0.0.2 新登場
    相容: Realtek Ameba\Arduino Ethernet\ Nodemcu \ AVR系列配網路擴充板等
2016-02-01 LASS CompactPM25 CrossFit V0.0.2 新登場
    LASS CompactPM25 CrossFit V0.0.2 新登場
    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
2016-02-13 1. add gps_distance function, detect device move 2. kml export by device and by condition (all moving devices)
2016-02-14 1. add app=Air-1 supported 2. support Grove - Multichannel Gas Sensor 3. VER=0.8.1
    [configuration.h]
2016-02-14 restore default device ID to FT1_999
    [configuration.h]
2016-03-10 minor fix lass crossfit
    [LASS_CompactPM25.ino]
2016-03-10 3dp case for drone V3 from Scott Chen contributions
    [LASS BOX ver3 G3 side.stl, LASS BOX ver3 G3 side.stp, LASS BOX ver3 PCB side.stp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]
2016-03-12 Correcting Path
    [configuration.h]
2016-03-18 [3dp] Scott_Chen, LASS_V3.1_Cover 1.修正GPS天線太緊 2.修正螺絲Boss局部干涉 3.新增GSM固定
    [LASS BOX ver3_1 G3 side.stl, LASS BOX ver3_1 PCB side.stl, LASS BOX ver3_1.stp]
2016-03-21 a compile bug fixed!
    a compile bug fixed!
    [configuration.h]
2016-03-22 Fix dead loop
    Fix dead loop
    [LASS.ino]
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2016-03-26 v0.8.2 update/更新
    Important update…
    Fix Fake GPS wrong time…
    Fix Dead Loop…
    Fix Dead Webserver setup…
    with a CLEAR_SETTING bit
    reduce upload period to LASS server to 30 sec
    [configuration.h]
2016-03-26 v0.8.2 update/更新2
    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
    [LASS.ino]
2016-03-26 v0.8.2a improve
    each time you upload code ….it will use settings in configuration.h
    只要重新燒錄就會使用 configuration.h的設定...
    [configuration.h]
2016-03-27 support a new APP called MAPS2
    [configuration.h]
2016-04-05 fix fake_gps demo config....
    no code change…just demo config change
    [configuration.h]
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2016-04-14 [IASS] IAAS_CODES replaced with IASS_BASIC
    [DHT.ino, FC-37.ino, MH-Z16.ino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]
2016-04-19 robert501128 pull request: bug fix, init device ID
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2016-07-07 LASS4U box contribute by Scott Chen
    [BOX_back.CATPart, BOX_back.stl, BOX_back.stp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]
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2016-09-02 add LinkIt Smart 7688 Duo arduino code version, w/ new extend board PCB layout
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2016-10-31 V0.2.2 imported some environment data source ( car , population, fixed pollution source )
    [土地面積、人口及密度2015年01季.csv, 基本資料.csv, 廢棄物申報.csv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]
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2016-11-07 with LCD support in request of 台中共學團
    1602 LCD支援....
    [configuration.h]
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2016-12-10 LASS4U 3DP case Modify by ICSHOP
    retail version of LASS4U 3DP case
    [front cover(102616modify).STL]
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2018-06-24 Update 3_System.ino
    修正send_to_sigfox(), _bale2Hex()
    [3_System.ino]
2018-07-11 3d printer file
    [G278C開孔支架.STL, 底層電池支架G278C.STL]
2018-07-22 before LASS 2018 workshop commit
    [G278C開孔支架.STL, 底層電池支架G278C.STL]
2018-07-22 LASS 2018 workshop commit
    [DS3231時間模組.sldprt, EC模組.sldprt, G278C開孔支架.STL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]
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2019-08-30 add 7 devices to UChicago project
    74DA38ED07F4 AirBox-UChicago-43
    74DA38ED0778 AirBox-UChicago-44
    74DA38ED0774 AirBox-UChicago-45
    74DA38ED0802 AirBox-UChicago-46
    74DA38ED07FE AirBox-UChicago-47
    74DA38ED0804 AirBox-UChicago-48
    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
2019-12-20 Fix 市 and 巿
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
